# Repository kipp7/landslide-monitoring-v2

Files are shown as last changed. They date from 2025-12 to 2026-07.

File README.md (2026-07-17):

# Landslide Monitoring V2








English | [简体中文](README.zh-CN.md)

<p align="center">
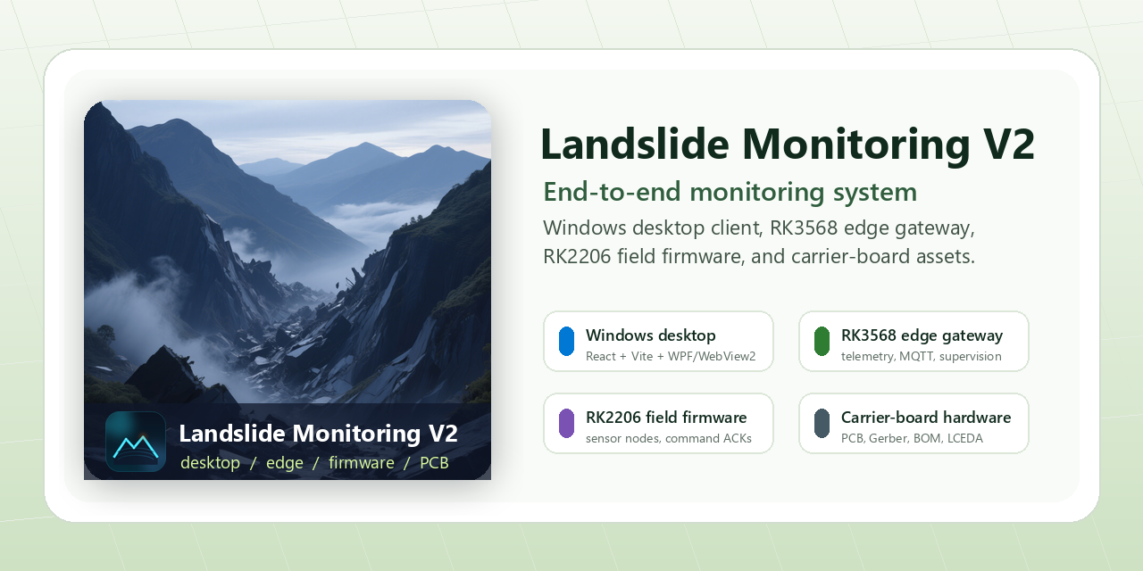
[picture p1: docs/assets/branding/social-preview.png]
Landslide Monitoring V2 end-to-end system preview
  
</p>

Landslide Monitoring V2 is an end-to-end open-source landslide monitoring system. It brings together the Windows operator client, cloud backend services, RK3568 edge gateway services, RK2206 field-node firmware, and carrier-board hardware handoff assets in one public repository.

The repository is organized around five product areas: desktop operations, cloud backend services, edge gateway services, field firmware, and carrier-board hardware.

## System Overview

```text
RK2206 field nodes
  -> RK3568 edge gateway
    -> compatible monitoring API / MQTT broker
      -> Windows desktop operator client
```

## Highlights

- Windows monitoring client built with React, Vite, WPF, and WebView2.
- Cloud backend with REST API, PostgreSQL, ClickHouse, EMQX, Kafka, telemetry ingestion, rules, and device-command workers.
- RK3568 edge services for serial telemetry, MQTT forwarding, local health summaries, supervision, and alarm actuation.
- RK2206 XL01 field firmware package for sensor acquisition, telemetry envelopes, command acknowledgements, watchdogs, and board utilities.
- Carrier-board public handoff package with schematic, PCB preview, Gerber, BOM, pick-and-place, and LCEDA source package.
- Bilingual documentation, GitHub issue templates, maintainer notes, security policy, CI, and MIT license.

## Repository Layout

| Path | Responsibility |
| --- | --- |
| `apps/desktop-ui/` | React + Vite monitoring interface for operator workflows. |
| `apps/windows-shell/` | WPF + WebView2 Windows host, packaging assets, and native startup checks. |
| `services/` | Cloud API, telemetry, alerting, prediction, and command-processing services. |
| `infra/compose/` | Single-host backend infrastructure and application deployment. |
| `edge/rk3568-gateway/` | RK3568 gateway, link-monitor, supervisor, and alarm actuator services. |
| `firmware/rk2206-xl01/` | RK2206 XL01 field-node firmware package and pinout notes. |
| `hardware/carrier-board/` | Public carrier-board design and fabrication handoff assets. |
| `packages/`, `libs/` | Shared TypeScript packages used by edge and backend services. |
| `scripts/desktop/` | Windows desktop development, packaging, and verification scripts. |
| `docs/` | Architecture, scope, release, system, maintainer, and bilingual documentation. |

## Maintained Surfaces

| Surface | Status | Primary Docs |
| --- | --- | --- |
| Windows desktop client | Maintained | [Desktop UI](apps/desktop-ui/README.md), [Windows shell](apps/windows-shell/README.md) |
| Cloud backend | Maintained | [Docker Compose deployment](infra/compose/README.md) |
| RK3568 edge gateway | Maintained | [Edge gateway](edge/rk3568-gateway/README.md) |
| RK2206 field firmware | Maintained as public firmware package | [Firmware](firmware/rk2206-xl01/README.md) |
| Carrier-board hardware handoff | Maintained as public design package | [Hardware](hardware/carrier-board/README.md) |
| Web and mobile applications | Not included in the public tree | [Project scope](docs/PROJECT_SCOPE.md) |

## Tech Stack

| Layer | Technology |
| --- | --- |
| Desktop UI | React 18, TypeScript, Vite, Ant Design |
| Visualization | ECharts, Leaflet, Three.js |
| Native desktop shell | .NET 8, WPF, WebView2 |
| Cloud backend | Node.js 20, Fastify, PostgreSQL, ClickHouse, EMQX, Kafka |
| Edge services | Node.js 20, TypeScript, MQTT, serialport, systemd deployment templates |
| Field firmware | OpenHarmony/RK2206 application package |
| Hardware handoff | Schematic, PCB preview, Gerber, BOM, pick-and-place, LCEDA project package |
| Tooling | npm workspaces, ESLint, Prettier, GitHub Actions |

## Quick Start

```powershell
git clone https://github.com/kipp7/landslide-monitoring-v2.git
cd landslide-monitoring-v2
npm install
npm run dev
```

The desktop UI dev server starts at `http://localhost:5174/`.

Launch the native Windows shell against the dev server:

```powershell
npm run desktop:dev
```

## Build And Validate

Desktop UI:

```powershell
npm audit
npm run lint
npm run build
```

RK3568 edge services:

```powershell
npm run edge:build
npm run edge:lint
```

Windows shell:

```powershell
dotnet build .\apps\windows-shell\LandslideDesk.Win\LandslideDesk.Win.csproj -c Release
```

Create the default Windows portable package:

```powershell
npm run desktop:publish
```

Default packaging outputs stay outside Git:

- `artifacts/windows/portable/`
- `docs/reports/windows-package-latest.json`

## Documentation

- [Documentation hub](docs/README.md)
- [System overview](docs/system/OVERVIEW.md)
- [Architecture](docs/ARCHITECTURE.md)
- [Project scope](docs/PROJECT_SCOPE.md)
- [Release process](docs/RELEASE.md)
- [中文文档总览](docs/zh-CN/README.md)
- [中文系统概览](docs/zh-CN/system/OVERVIEW.md)
- [中文架构说明](docs/zh-CN/ARCHITECTURE.md)
- [中文项目范围](docs/zh-CN/PROJECT_SCOPE.md)
- [中文发布流程](docs/zh-CN/RELEASE.md)

## Repository Scope

This repository includes public source code, documentation, examples, deployment templates, the RK2206 firmware package, and carrier-board handoff files. Runtime secrets, local logs, generated builds, and site-specific configuration should stay outside Git.

## Contributing

Contributions are welcome. Please read [CONTRIBUTING.md](CONTRIBUTING.md) before opening a pull request, and include screenshots or recordings for visible UI changes.

## License

Released under the [MIT License](LICENSE).

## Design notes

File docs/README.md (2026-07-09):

# Documentation

English | [简体中文](zh-CN/README.md)

This documentation set keeps the public repository small, clear, and buildable. It explains the maintained system areas, runtime boundaries, local validation commands, release process, and contribution workflow.

## Start Here

| Document | Purpose |
| --- | --- |
| [System Overview](system/OVERVIEW.md) | End-to-end product surfaces and data flow. |
| [Architecture](ARCHITECTURE.md) | Runtime boundary, module responsibilities, and packaging flow. |
| [Project Scope](PROJECT_SCOPE.md) | Repository contents, maintained areas, and current non-goals. |
| [Release Process](RELEASE.md) | Local build, validation, packaging, and GitHub release checklist. |
| [Desktop UI](../apps/desktop-ui/README.md) | React/Vite UI package responsibilities and commands. |
| [Windows Shell](../apps/windows-shell/README.md) | WPF/WebView2 host responsibilities and packaging behavior. |
| [RK3568 Edge Gateway](../edge/rk3568-gateway/README.md) | Edge service responsibilities, deployment notes, and local configuration. |
| [RK2206 Firmware](../firmware/rk2206-xl01/README.md) | Field-node firmware package and build context. |
| [Carrier Board](../hardware/carrier-board/README.md) | Hardware design and fabrication handoff package. |
| [Contributing](../CONTRIBUTING.md) | Contribution workflow, checks, and project conventions. |
| [Maintainers Guide](../MAINTAINERS.md) | Review policy, dependency update cadence, and release readiness checks. |
| [Security](../SECURITY.md) | Vulnerability reporting and secret-handling policy. |

## Repository Conventions

- Directory names describe product responsibility and runtime role.
- Generated artifacts belong under `artifacts/` and stay out of Git.
- Local reports belong under `docs/reports/` and should be regenerated as needed.
- Public-facing behavior changes should update both English and Chinese documentation.
- Pull requests that change visible UI should include screenshots or recordings.
- Hardware files are treated as handoff assets and should be reviewed before fabrication.

## Maintained Surface

The current public repository maintains:

- Windows desktop UI and native shell source.
- RK3568 edge gateway services and deployment templates.
- RK2206 XL01 field firmware package.
- Carrier-board hardware design and fabrication handoff assets.
- Desktop packaging and verification scripts.
- Public documentation, issue templates, and pull request templates.

The following areas are outside the current public scope:

- Production backend services.
- Mobile applications.
- Web dashboard application code.
- Production deployment infrastructure.
- Site-specific configuration and environment files.
- Credentials, generated outputs, local logs, and runtime state.

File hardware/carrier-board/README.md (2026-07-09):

# Carrier Board Hardware

This directory contains the public carrier-board handoff package for the RK2206/XL01 landslide monitoring node.

## Contents

| Path | Purpose |
| --- | --- |
| `assets/board-layout-module-carrier-150x100-v7.svg` | Human-readable layout reference. |
| `board-layout-notes.md` | Placement, connector, and routing notes. |
| `coordinate-table.md` | Component coordinate planning table. |
| `pin1-dimension-notes.md` | Pin-1 and mechanical dimension notes. |
| `electrical-layout-notes.zh-CN.md` | Chinese electrical and wiring notes. |
| `production/gerber-pcb1-2026-05-05.zip` | Gerber package for PCB fabrication review. |
| `production/schematic-2026-04-30.pdf` | Schematic export. |
| `production/pcb-preview-2026-05-05.pdf` | PCB preview export. |
| `production/bom-board1-2026-04-23.xlsx` | BOM export. |
| `production/pick-and-place-2026-04-27.xlsx` | Pick-and-place export. |
| `production/lceda-project-rk2206-v1.2-2026-05-02.epro2` | LCEDA project package. |

## Manufacturing Notice

Review the schematic, BOM, pick-and-place orientation, connector footprints, and supplier substitutions before ordering. Fabrication should be checked against the selected vendor's requirements.

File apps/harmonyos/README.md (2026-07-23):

# HarmonyOS landslide monitoring prototype

This is the native ArkTS/ArkUI phone prototype for the landslide monitoring
platform. The server remains the only source of truth: the app calls the
existing `/api/v1` HTTP API and never connects to PostgreSQL or ClickHouse.

## Local development

Open this directory in DevEco Studio, select the `default` product, configure
the API base URL in `entry/src/main/ets/data/ApiConfig.ets`, and run the `entry`
module on a HarmonyOS phone or emulator.

DevEco Studio provides the required SDK and Hvigor runtime. The project can be
built from DevEco Studio or with its bundled `hvigorw` command after setting
`DEVECO_SDK_HOME`.

## Data and cache behavior

- Login, dashboard, stations, devices, telemetry, alerts, and predictions use
  the existing `/api/v1` contract.
- Dashboard `todayReportCount` counts distinct device reports, while
  `todayDataCount` remains the sparse ClickHouse sensor-row count for API
  compatibility. Both use the Beijing calendar day (`UTC+8`, starting at
  local 00:00); the App displays it as `今日数据上传条数` with the exact
  Beijing update time and does not label it as sensor rows.
- The **Hermes intelligent workbench** uses `/api/v1/edge-ai/status`,
  `/api/v1/edge-ai/chat`, `/api/v1/edge-ai/conversations`, and the bounded
  action endpoints. Conversations, user/assistant messages, task status, and
  results are persisted by the server in the existing PostgreSQL database and
  isolated by authenticated user. The App remains API-only.
- Hermes exposes only three bounded, read-only actions to the App: re-evaluate
  risk (`重新研判`), collect diagnostic evidence (`诊断链路`), and generate a
  situation report (`生成报告`). A message may contain several safe actions;
  the server creates an auditable plan and dispatches them to RK3568 in spoken
  order. The App shows the real conversation and each server task rather than
  treating an action log as chat history.
- Protected requests such as restarting services, changing networks or alarm
  thresholds, controlling devices, writing serial data, and triggering or
  clearing physical alarms are blocked before RK3568 is called. Physical alarm
  authority remains with the rule engine and confirmed human workflows.
- Edge AI is loaded independently from the monitoring dashboard. If RK3568
  Hermes is unavailable, the App keeps the last cached AI snapshot and all
  original monitoring pages continue to refresh normally.
- Successful summary, station, device, and latest-state responses are cached
  with TTLs. The app renders stale data immediately and refreshes in the
  background.
- Historical series stay in memory only. Preferences stores small snapshots,
  never credentials or a second business database.
- Access and refresh tokens are stored with HarmonyOS AssetStoreKit and are
  removed on logout or when the API server is changed. A valid session is
  restored after the app process restarts.
- Device detail refreshes every 10 seconds while visible; dashboard and alerts
  refresh every 30 seconds. Refresh stops when the app is backgrounded.
- All temperature and moisture values are presented as soil temperature and
  soil moisture. Generic server keys are compatibility fallbacks only.
- Soil conductivity uses `electrical_conductivity_us_cm` and is displayed in
  `μS/cm`; when the latest-state snapshot omits it, device detail falls back to
  the newest point in the requested historical series.
- Conductivity visibility follows device capability metadata. An explicit
  `hasConductivitySensor` value takes priority; the current A/B/C deployment
  enables conductivity for field nodes B and C only.
- Monitoring-node counts, sensor trends, and state requests exclude platform
  alarm actuators. The Tongxiao RK2206 terminal is shown separately as
  `通晓 RK2206 声光告警终端` under linkage alarm devices, so it cannot distort
  A/B/C monitoring statistics.
- The Tongxiao linkage status comes from `/api/v1/field-alarm/status` and its
  physical-device probe when available. It is not inferred from telemetry
  `lastSeenAt`, because the actuator is not a monitoring-data producer.
- The alert map resolves coordinates in this order: coordinates recorded with
  the alert, recent device GPS, seven-day GPS history, the last GPS snapshot,
  station coordinates, and finally the Windows desktop default position at
  Xiamen University (`24.43803, 118.09631`). A stale GPS value is labelled as
  the last GPS rather than real-time data. GPS values outside the project's
  China operating region are treated as invalid device data and cannot replace
  the last valid position.
- Map preview renders every monitoring node and fits the viewport to all node
  markers. Nodes without GPS use the same three-point spread around Xiamen
  University as the Windows desktop, while an active alert remains centred and
  switches the matching node to a red warning ripple. Other nodes retain a
  green monitoring ripple; a separate red ripple is used when the precise alert
  coordinate differs from its node location. Live GPS markers that resolve to
  the same site are spread only in the presentation layer and labelled as such,
  so A/B/C remain selectable without changing their stored coordinates.
- The station page embeds the same map as a distribution view. It shows every
  monitoring node, focuses the selected station, and refreshes GPS without
  introducing a second location model.
- The most recent valid GPS snapshot is stored in Preferences using the same
  API-server and user cache namespace. It is cleared on logout or server
  change, so positions cannot leak across accounts or environments.
- Foreground `ALERT_TRIGGER` SSE events open a blocking in-app alert panel and
  start the bundled smooth civil-defense-style alarm with a synchronized
  vibration cadence. Muting pauses both sound and vibration. Updates replace the same
  `alertId` in place, critical escalation reopens the strong reminder, and
  acknowledgement leaves the warning active, and only resolution removes that
  alert from the panel. Concurrent node alerts are queued by `alertId` instead
  of being duplicated by event ID.
  See [`ALERT_INTEGRATION.md`](./ALERT_INTEGRATION.md) for the shared Windows,
  App, and Push payload contract.
- The **My** page keeps the API address hidden in normal use. Connection state,
  cache cleanup, refresh cadence, location use, and app version are grouped as
  settings; the address is only exposed after opening the server editor.
- The map uses Leaflet with TianDiTu `img_w` satellite imagery and `cia_w`
  Chinese annotations. Its browser-side key is injected by ArkTS from
  `entry/src/main/ets/data/MapConfig.ets`. Map tiles are not part of the
  business-data cache and require network access; coordinates and their source
  remain visible when the basemap cannot load.

## API configuration

The normal login screen uses the default API base URL from
`entry/src/main/ets/data/ApiConfig.ets` and keeps it hidden. Authentication
errors remain on the login screen. If the server cannot be reached or the API
path is invalid, the app opens a separate server connection screen where the
address can be changed. Signed-in users can open **My > Server connection** to
change it; changing environments clears the current session and cached data.

For emulator and LAN debugging, use a reachable LAN or HTTPS URL that includes
the `/api/v1` path. `127.0.0.1` inside an emulator refers to the emulator
itself. Release builds should use HTTPS.

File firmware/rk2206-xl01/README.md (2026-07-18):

# RK2206 XL01 Field Firmware

This directory contains the stable RK2206 XL01 field-node firmware package used by the landslide monitoring system.

## Responsibilities

- Sensor acquisition and field-node data model.
- GPS and deformation data handling.
- Telemetry envelope construction.
- Device command parsing and command acknowledgement.
- COBS/CRC framed southbound transport and gateway-polled telemetry.
- SC16IS752-backed RS485 soil, optional conductivity, and tilt acquisition.
- Watchdog-backed recovery after 180 seconds without an accepted gateway command.
- Watchdog, FIFO, and board-level utility helpers.

## Upstream Build Context

The firmware is designed to be built inside a compatible OpenHarmony/RK2206 vendor tree. This directory contains the application package and documentation needed for that integration.

## Key Files

- `BUILD.gn` - OpenHarmony build target definition.
- `main/landslide_main.c` - field-node entrypoint.
- `app/` - telemetry, command, identity, and application models.
- `drivers/` - sensor and XL01 integration drivers.
- `config/app_config.h` - board/application constants.
- `PINOUT.md` and `RK2206_PINOUT_NOTES.zh-CN.md` - wiring and pinout references.

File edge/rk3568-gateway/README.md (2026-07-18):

# RK3568 Edge Gateway

This directory contains the RK3568 edge services that bridge field nodes and the monitoring platform.

## Services

| Service | Role |
| --- | --- |
| `field-gateway` | Main serial-to-MQTT gateway with spool/cache, health file output, polling, command ACK handling, and RK3568 deployment scripts. |
| `field-link-monitor` | Read-only local sidecar that summarizes field-link health and exposes local supervision endpoints. |
| `hermes-edge-supervisor` | Local edge supervision service that consumes health signals and produces operator guidance. |
| `rk3568-alarm-actuator` | Local actuator service for RK3568-driven field alarm control. |
| `cellular` | EC200A readiness, business-link health, and optional reverse-tunnel deployment helpers. |

## Deployment

Each service keeps its own `deploy/` directory when deployment assets exist. Environment examples use placeholders and must be copied to local `.env` or systemd environment files before real deployment.

## Local Configuration

Keep deployment-specific values in local environment files. Use `.env.example` and `deploy/*.example` files as templates for device configuration.

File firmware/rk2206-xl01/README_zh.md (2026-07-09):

# XL01 滑坡监测节点 - 模块化架构 v2.0

## 项目简介

基于 RK2206 + XL01 无线模块的滑坡监测节点，采用分层模块化架构设计。

**当前版本**: v2.0  
**状态**: 可构建的公开固件包
**架构**: 分层模块化设计

---

## 架构特点

### 模块化分层设计

```
xl01_landslide_monitor/
├── config/           # 配置层：全局参数集中管理
│   └── app_config.h
├── utils/            # 工具层：通用功能模块
│   ├── fifo.h/.c           # FIFO缓冲区
│   └── watchdog_mgr.h/.c   # 看门狗管理
├── drivers/          # 驱动层：硬件抽象
│   ├── xl01/               # 无线通信模块驱动
│   │   ├── xl01_driver.h
│   │   └── xl01_driver.c
│   └── sensors/            # 传感器驱动
│       ├── sht30_driver.h/.c    # 温湿度
│       ├── mpu6050_driver.h/.c  # 加速度/陀螺仪
│       └── gps_driver.h/.c      # GPS定位
├── app/              # 应用层：数据结构定义
│   └── sensor_data.h
└── main/             # 主程序：业务逻辑
    └── landslide_main.c
```

### 设计优势

| 特性 | 说明 |
|-----|---|
| **关注点分离** | 配置、驱动、应用逻辑各司其职 |
| **硬件抽象** | 传感器驱动独立，易于测试和替换 |
| **低耦合** | 模块间依赖最小化 |
| **高内聚** | 相关功能组织在一起 |
| **可维护性** | 单一职责原则，修改影响面小 |
| **可测试性** | 独立模块便于单元测试 |
| **可扩展性** | 新增传感器只需添加新驱动模块 |

---

## 核心功能

### 1. 模块化传感器支持
每个传感器可独立启用/禁用（在 `config/app_config.h` 中配置）：
```c
#define ENABLE_GPS          0    // GPS定位模块
#define ENABLE_SHT30        0    // 温湿度传感器
#define ENABLE_MPU6050      0    // 加速度/陀螺仪
#define ENABLE_VIRTUAL      1    // 虚拟数据（测试用）✓
```

### 2. ACK确认机制
当前 ACK 机制分成两层：

1. **链路级 ACK**
- 节点 ↔ 无线/网关之间的确认
- 当前仍使用 `"ACK"` / `"OK"` 字符串
- 只用于确认串口/无线链路发送成功

2. **平台命令回执**
- 不再停留在 `"ACK"` / `"OK"`
- 对齐软件主线：
  - `cmd_ack/{device_id}`
  - `DeviceCommandAck v1`

当前代码里保留的 `ENABLE_ACK_CHECK` / `ACK_TIMEOUT_MS` 主要属于第 1 层，也就是链路级 ACK：
```c
#define ENABLE_ACK_CHECK    1       // 启用ACK检查
#define ACK_TIMEOUT_MS      1000    // ACK超时（毫秒）
#define MAX_RETRY_COUNT     3       // 最大重试次数
```

工作流程：
1. RK2206 发送遥测或标准回执 payload
2. 等待网关/接收端返回链路级 `"ACK\n"` / `"OK"`
3. 收到 ACK → 链路发送成功 ✓
4. 超时 → 自动重试（最多3次）

### 3. 防丢包机制
- **1024字节FIFO缓冲** - 高速接收不丢数据
- **三任务架构**:
  - `UartRxTask` (高优先级, 1ms轮询)
  - `DataProcessTask` (普通优先级)
  - `SensorUploadTask` (低优先级)

### 4. 看门狗保护
```c
#define ENABLE_WATCHDOG     1       // 启用看门狗
#define WATCHDOG_TIMEOUT    10      // 超时时间（秒）
```
系统异常时自动重启恢复。

### 5. 低功耗支持
```c
#define UPLOAD_INTERVAL_MS  5000    // 上传间隔（可调）
#define ENABLE_LOW_POWER    0       // 低功耗模式（预留）
```

---

## 配置参数

所有配置参数都在 `config/app_config.h` 文件中集中管理：

### 身份配置
```c
#define IDENTITY_SCHEMA_VERSION  1
#define CRED_VERSION             1
#define DEVICE_ID                "00000000-0000-0000-0000-000000000001"
#define DEVICE_SECRET            "CHANGE_ME_DEVICE_SECRET"
#define INSTALL_LABEL            "FIELD-NODE-A"
#define LEGACY_NODE_LABEL        "A"   // 仅调试标签，不再作为平台主身份
```

### 上传配置
```c
#define UPLOAD_INTERVAL_MS  5000    // 上传间隔
                                    // 推荐值：
                                    //   3000 = 快速监测
                                    //   5000 = 标准（推荐）
                                    //  10000 = 省电模式
```

### 硬件配置
```c
// XL01无线模块
#define XL01_UART_ID    EUART2_M1   // UART2
#define XL01_BAUDRATE   115200      // 波特率

// I2C传感器
#define I2C_IDX         EI2C0_M0    // PB4/PB5
#define SHT30_I2C_ADDR  0x44        // SHT30地址
#define MPU6050_I2C_ADDR 0x68       // MPU6050地址

// GPS模块
#define GPS_UART_ID     EUART0_M0   // PB6/PB7
#define GPS_BAUDRATE    9600        // 波特率
```

---

## 🚀 快速开始

### 1. 编译固件

```bash
# 进入Docker容器
docker exec -it openharmony-dev bash

# 编译
cd /root/workspace/txsmartropenharmony
hb build -f

# 固件位置
# out/rk2206/isoftstone-rk2206/liteos.bin
```

### 2. 烧录固件

使用HiBurn工具烧录 `liteos.bin` 到RK2206。

### 3. 配置接收端 / 网关

**临时串口接收示例（仅链路验证，不是最终平台真相）**
```python
import serial
ser = serial.Serial("COM3", 115200)
while True:
    if ser.in_waiting > 0:
        line = ser.readline().decode('utf-8').strip()
        print(line)
        # 回复链路级 ACK（如果启用了 ACK 检查）
        ser.write(b"ACK\n")
```

说明：

- 这段 Python 只适合验证串口/无线链路本身
- 当前长期目标不是“中心节点长期回 ACK 字符串”
- 而是让网关或适配层最终把数据接入软件主线：
  - 遥测：`telemetry/{device_id}`
  - 命令：`cmd/{device_id}`
  - 回执：`cmd_ack/{device_id}`

### 4. 观察输出

**RK2206串口输出**:
```
========================================
  Configuration Summary
========================================
  Device ID: 00000000-0000-0000-0000-000000000001
  Upload Interval: 5000 ms
  ACK Check: Enabled
  Sensors: Virtual ✓
========================================

[SEND #1] 245 bytes device=00000000-0000-0000-0000-000000000001 ✓ ACK
  Temp:25.0°C Humi:60.0% Tilt:0.00° GPS:OK Bat:99%
```

**当前建议对齐到平台主线的上报格式**:
```json
{
  "schema_version": 1,
  "device_id": "00000000-0000-0000-0000-000000000001",
  "event_ts": null,
  "seq": 1,
  "metrics": {
    "temperature_c": 25.0,
    "humidity_pct": 60.0,
    "tilt_x_deg": 0.0,
    "tilt_y_deg": 0.0,
    "gps_latitude": 22.543000,
    "gps_longitude": 114.057900,
    "battery_pct": 99,
    "warning_flag": false
  },
  "meta": {
    "install_label": "FIELD-NODE-A",
    "legacy_node": "A",
    "uptime_s": 5,
    "legacy_valid_flags": {
      "temp_ok": 1,
      "imu_ok": 1,
      "gps_ok": 1
    }
  }
}
```

当前软件主线对应 topic：

- 遥测：`telemetry/{device_id}`
- 命令：`cmd/{device_id}`
- 回执：`cmd_ack/{device_id}`

---

## 🔧 传感器接入流程（模块化方式）

### Step 1: 测试虚拟数据（当前状态）
```c
#define ENABLE_VIRTUAL 1  // ✓
```
确保 XL01 通信正常，且链路级 ACK 机制工作。

### Step 2: 接入SHT30温湿度
1. 连接硬件（I2C）
2. 修改配置（`config/app_config.h`）：
   ```c
   #define ENABLE_VIRTUAL 0
   #define ENABLE_SHT30   1
   ```
3. 驱动已实现在 `drivers/sensors/sht30_driver.c`
4. 编译测试

### Step 3: 接入MPU6050加速度/陀螺仪
```c
#define ENABLE_MPU6050 1
```
驱动已实现在 `drivers/sensors/mpu6050_driver.c`

### Step 4: 接入GPS模块
```c
#define ENABLE_GPS 1
```
驱动已实现在 `drivers/sensors/gps_driver.c`（需完善NMEA解析）

---

## 📝 添加新传感器（模块化）

遵循模块化原则，添加新传感器非常简单：

### 1. 创建驱动模块
在 `drivers/sensors/` 下创建 `xxx_driver.h` 和 `xxx_driver.c`：

```c
// drivers/sensors/xxx_driver.h
#ifndef DRIVERS_SENSORS_XXX_DRIVER_H
#define DRIVERS_SENSORS_XXX_DRIVER_H

int XXX_Init(void);
int XXX_Read(float *value);

#endif

// drivers/sensors/xxx_driver.c
#include "xxx_driver.h"
#include "../../config/app_config.h"

int XXX_Init(void) {
    // 初始化代码
    return 0;
}

int XXX_Read(float *value) {
    // 读取代码
    return 0;
}
```

### 2. 更新配置
在 `config/app_config.h` 中添加：
```c
#define ENABLE_XXX  1
```

### 3. 更新数据结构
在 `app/sensor_data.h` 的 `SensorData` 结构体中添加字段：
```c
typedef struct {
    // ...现有字段...
    float xxx_value;  // 新传感器数据
    int xxx_valid;    // 数据有效标志
} SensorData;
```

### 4. 集成到主程序
在 `main/landslide_main.c` 中：
```c
// 引入头文件
#if ENABLE_XXX
#include "../drivers/sensors/xxx_driver.h"
#endif

// SystemInit() 中初始化
#if ENABLE_XXX
XXX_Init();
#endif

// SensorCollectionTask() 中读取
#if ENABLE_XXX
if (XXX_Read(&g_sensor_data.xxx_value) == 0) {
    g_sensor_data.xxx_valid = 1;
}
#endif

// DataUploadTask() 中添加到JSON
// "xxx":%.2f,"xxx_ok":%d,
```

### 5. 更新构建配置
在 `BUILD.gn` 的 `sources` 中添加：
```gn
"drivers/sensors/xxx_driver.c",
```

完成！新传感器已集成，无需修改其他模块。

---

## 📊 当前软件主线对齐后的遥测格式

```json
{
  "schema_version": 1,   // 契约版本
  "device_id": "00000000-0000-0000-0000-000000000001",
  "event_ts": null,
  "seq": 123,            // 序列号
  "metrics": {
    "temperature_c": 25.5,
    "humidity_pct": 62.3,
    "accel_x_g": 0.15,
    "accel_y_g": 0.09,
    "accel_z_g": 1.02,
    "gyro_x_dps": 0.5,
    "gyro_y_dps": -0.3,
    "gyro_z_dps": 0.1,
    "tilt_x_deg": 0.15,
    "tilt_y_deg": 0.09,
    "gps_latitude": 22.543012,
    "gps_longitude": 114.057923,
    "battery_pct": 85,
    "warning_flag": false
  },
  "meta": {
    "install_label": "FIELD-NODE-A",
    "legacy_node": "A",
    "uptime_s": 615,
    "legacy_valid_flags": {
      "temp_ok": 1,
      "imu_ok": 1,
      "gps_ok": 1
    }
  }
}
```

---

## 📈 统计监控

每10个数据包输出统计信息：
```
========== Statistics ==========
  Uptime: 50 sec
  Sent: 10/10 (Success: 100.0%)
  Retries: 0, Failed: 0
  Total bytes: 2450
  RX packets: 0
================================
```

---

## ❓ 故障排查

### 问题1: 接收端 / 网关收不到数据
**检查**:
- ✓ XL01天线是否连接
- ✓ 串口连接（白线→RX, 绿线→TX）
- ✓ XL01是否配置为透传模式
- ✓ 波特率是否匹配（115200）

### 问题2: ACK总是超时
**检查**:
- ✓ 接收端 / 网关程序是否运行
- ✓ 接收端是否回复链路级 `"ACK\n"`
- ✓ 串口号是否正确
- ✓ 增加超时：`#define ACK_TIMEOUT_MS 2000`

### 问题3: 平台命令回执没有闭环
**检查**:
- ✓ 当前是否只完成了链路级 ACK，而没有输出标准 `DeviceCommandAck v1`
- ✓ 当前网关是否把回执发到了 `cmd_ack/{device_id}`
- ✓ `device_id` 是否与平台设备身份一致
### 问题4: 编译错误
**检查**:
- ✓ 确保所有 `.c` 文件都在 `BUILD.gn` 的 `sources` 中
- ✓ 确保头文件路径正确（使用相对路径 `../../`）
- ✓ 确保配置宏定义正确（`config/app_config.h`）

---

## 技术特性总结

### 优势
1. **模块化**: 分层设计，职责清晰
2. **可维护**: 单一职责，易于定位问题
3. **可测试**: 独立模块，支持单元测试
4. **可扩展**: 新增功能不影响现有代码
5. **运行保护**: 统计信息、异常恢复和看门狗保护

### 性能指标
- **上传间隔**: 3-60秒（可配置）
- **链路 ACK 延迟**: 0.2-5.5秒（含重试）
- **缓冲容量**: 1024字节FIFO
- **成功率**: >95%（良好信号下）

---

## 相关文档

- `CHANGELOG.md` - 变更记录
- 中心节点 ACK 示例和 ACK 机制说明应以仓库内文档或示例代码为准。

---

## 维护信息

**版本**: v2.0  
**更新**: 2025-10-22  
**状态**: 固件工程具备模块化基础，但仍在向当前软件主线契约全面收口

**架构亮点**:
- 分层模块化设计
- 驱动层硬件抽象
- 配置集中管理
- 模块独立可测试
- 清晰的职责划分

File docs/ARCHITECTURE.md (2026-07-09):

# Architecture

Landslide Monitoring V2 is organized as a public end-to-end monitoring workspace. The repository keeps the desktop client, edge gateway, field firmware, and carrier-board handoff files together in one buildable tree.

## System Boundary

```text
Field layer
  RK2206 XL01 firmware
    -> sensor acquisition, telemetry envelope, command acknowledgement

Edge layer
  RK3568 gateway services
    -> serial link, MQTT forwarding, health summaries, supervision, alarm actuation

Operator layer
  Windows desktop client
    -> React monitoring UI hosted by WPF + WebView2
```

The public tree contains source, documentation, examples, deployment templates, and hardware handoff assets. Runtime secrets, generated builds, local logs, and site-specific configuration stay outside Git.

## Applications And Packages

| Path | Responsibility |
| --- | --- |
| `apps/desktop-ui` | React + Vite monitoring interface, routes, stores, charts, maps, and mock data. |
| `apps/windows-shell` | WPF/WebView2 native host, startup preflight checks, tray behavior, installer assets. |
| `edge/rk3568-gateway/field-gateway` | Serial-to-MQTT gateway with local spool/cache, health output, command ACK handling, and deployment templates. |
| `edge/rk3568-gateway/field-link-monitor` | Read-only local sidecar that summarizes field-link health. |
| `edge/rk3568-gateway/hermes-edge-supervisor` | Local supervision service that consumes health signals and produces operator-facing guidance. |
| `edge/rk3568-gateway/rk3568-alarm-actuator` | RK3568 alarm actuator service for field sound/light alarm control. |
| `firmware/rk2206-xl01` | RK2206 XL01 firmware package intended for an OpenHarmony/RK2206 vendor build tree. |
| `hardware/carrier-board` | Public carrier-board schematic, board preview, Gerber, BOM, pick-and-place, and LCEDA handoff package. |
| `packages/observability` | Shared logging helpers for edge services. |
| `packages/validation` | Shared validation helpers for edge payloads and configuration. |

## Desktop Client

The desktop client owns the operator-facing workflows:

- Dashboard and key monitoring site overview.
- Device management and command-oriented screens.
- GPS deformation and monitoring views.
- Analysis pages with charts, maps, and domain mock data.
- Account, settings, and system state pages.

The UI can run independently in development with:

```powershell
npm run dev
```

The native shell loads the UI in two modes:

- Development: reads `DESK_DEV_SERVER_URL`, usually `http://localhost:5174/`.
- Packaged: loads static files from the published `web/` directory.

## Edge Gateway

The RK3568 layer bridges field devices and upstream monitoring services. Its public services are split by responsibility:

- `field-gateway` owns serial ingestion, message reconstruction, MQTT publishing, spool/cache behavior, command windows, and health files.
- `field-link-monitor` reads local status files and exposes read-only supervision summaries.
- `hermes-edge-supervisor` turns local health signals into diagnostic and operator guidance output.
- `rk3568-alarm-actuator` controls field alarm hardware without taking over telemetry or gateway responsibilities.

Edge services are TypeScript packages and are validated from the root workspace:

```powershell
npm run edge:build
npm run edge:lint
```

## Field Firmware

The RK2206 XL01 firmware package contains application code, configuration, drivers, pinout notes, and build metadata. It is designed for integration with a compatible OpenHarmony/RK2206 vendor tree and uses the standard OpenHarmony/RK2206 build flow.

## Hardware Handoff

The carrier-board directory contains public design and fabrication handoff files. These files are useful for review, reproduction, and documentation, but fabrication still requires schematic review, BOM verification, footprint checks, and supplier substitution review.

## Packaging Flow

1. Build `apps/desktop-ui` into `apps/desktop-ui/dist`.
2. Publish `apps/windows-shell` with .NET.
3. Copy the static UI build into the desktop package under `web/`.
4. Write local package metadata under `docs/reports/`.
5. Keep generated outputs out of Git.

## Design Principles

- Keep public modules tied to clear product responsibilities.
- Prefer readable directory names over internal abbreviations.
- Keep generated artifacts, local reports, and machine state out of Git.
- Allow desktop UI work without backend deployment through mock data.
- Keep RK3568 services independently buildable and lintable.
- Treat hardware deliverables as reviewable handoff assets and check them against the selected vendor's requirements.

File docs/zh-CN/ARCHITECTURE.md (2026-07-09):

# 架构说明

山体滑坡监测 V2 是一个公开的端到端监测系统工作区。仓库把桌面客户端、边缘网关、现场固件和载板硬件交付资料放在同一个可构建的公开树中。

## 系统边界

```text
现场层
  RK2206 XL01 固件
    -> 传感采集、遥测封包、指令确认

边缘层
  RK3568 网关服务
    -> 串口链路、MQTT 转发、健康摘要、监督服务、声光报警执行

操作层
  Windows 桌面客户端
    -> WPF + WebView2 宿主中的 React 监测界面
```

公开树包含源码、文档、示例、部署模板和硬件交付资料。运行密钥、本地日志、生成产物和现场特定配置应保留在 Git 之外。

## 应用与包

| 路径 | 职责 |
| --- | --- |
| `apps/desktop-ui` | React + Vite 监测界面，包括路由、状态、图表、地图和 mock 数据。 |
| `apps/windows-shell` | WPF/WebView2 原生宿主，包括启动检查、托盘能力和安装器资源。 |
| `edge/rk3568-gateway/field-gateway` | 串口到 MQTT 网关，负责本地缓存、健康输出、指令 ACK 和部署模板。 |
| `edge/rk3568-gateway/field-link-monitor` | 只读本地 sidecar，汇总现场链路健康状态。 |
| `edge/rk3568-gateway/hermes-edge-supervisor` | 本地监督服务，消费健康证据并输出操作员可读建议。 |
| `edge/rk3568-gateway/rk3568-alarm-actuator` | RK3568 声光报警执行服务。 |
| `firmware/rk2206-xl01` | 面向 OpenHarmony/RK2206 vendor 构建树的 RK2206 XL01 固件包。 |
| `hardware/carrier-board` | 载板原理图、PCB 预览、Gerber、BOM、坐标文件和 LCEDA 交付包。 |
| `packages/observability` | 边缘服务共用日志工具。 |
| `packages/validation` | 边缘载荷和配置共用校验工具。 |

## 桌面客户端

桌面客户端负责操作员直接使用的工作流：

- 首页总览和关键监测点状态。
- 设备管理和指令相关页面。
- GPS 形变和监测视图。
- 基于图表、地图、领域 mock 数据的分析页面。
- 账号、设置和系统状态页面。

开发时可以独立运行：

```powershell
npm run dev
```

原生壳有两种加载模式：

- 开发模式：读取 `DESK_DEV_SERVER_URL`，通常为 `http://localhost:5174/`。
- 打包模式：从发布目录中的 `web/` 静态资源加载界面。

## 边缘网关

RK3568 层负责连接现场设备和上游监测服务。公开服务按职责拆分：

- `field-gateway` 负责串口采集、消息重组、MQTT 上行、本地缓存、指令窗口和健康文件。
- `field-link-monitor` 读取本地状态文件并暴露只读监督摘要。
- `hermes-edge-supervisor` 将本地健康信号转为诊断和操作建议。
- `rk3568-alarm-actuator` 控制现场声光报警硬件，不接管遥测或网关主链路。

边缘服务是 TypeScript 包，可在仓库根目录验证：

```powershell
npm run edge:build
npm run edge:lint
```

## 现场固件

RK2206 XL01 固件包包含应用代码、配置、驱动、引脚说明和构建元数据。它用于集成到兼容的 OpenHarmony/RK2206 vendor 树，并使用 OpenHarmony/RK2206 构建流程。

## 硬件交付

载板目录包含公开设计和打板交付文件。这些文件可用于复核、复现和文档说明，但打板前仍需检查原理图、BOM、封装、方向和供应商替代料。

## 打包流程

1. 将 `apps/desktop-ui` 构建到 `apps/desktop-ui/dist`。
2. 使用 .NET 发布 `apps/windows-shell`。
3. 将静态 UI 构建结果复制到桌面包的 `web/` 目录。
4. 将本地打包报告写入 `docs/reports/`。
5. 生成输出保留在 Git 之外。

## 设计原则

- 公开模块应对应清晰的产品职责。
- 使用可读目录名，避免不清晰缩写。
- 生成产物、本地报告和机器状态保留在 Git 之外。
- 通过 mock 数据支持无后端 UI 开发。
- RK3568 服务保持可独立构建和 lint。
- 硬件资料作为可复核交付资产维护，打板前应结合所选供应商要求复核。

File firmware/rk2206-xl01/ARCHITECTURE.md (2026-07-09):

# XL01 滑坡监测系统 - 架构设计文档

## 1. 架构概述

### 1.1 设计原则

本项目采用模块化分层架构，遵循以下设计原则：

- **职责清晰**：保持模块边界和接口清晰
- **关注点分离**：配置、驱动、工具、应用、业务逻辑各层独立
- **低耦合高内聚**：模块间依赖最小化，相关功能组织在一起
- **DRY原则**：Don't Repeat Yourself，避免代码重复
- **KISS原则**：Keep It Simple, Stupid，保持简单

### 1.2 分层架构

```
┌─────────────────────────────────────┐
│  配置层 (config/)                   │ ← 集中管理所有参数
├─────────────────────────────────────┤
│  工具层 (utils/)                    │ ← 可复用通用模块
├─────────────────────────────────────┤
│  驱动层 (drivers/)                  │ ← 硬件抽象接口
├─────────────────────────────────────┤
│  应用层 (app/)                      │ ← 数据结构定义
├─────────────────────────────────────┤
│  主程序 (main/)                     │ ← 业务逻辑编排
└─────────────────────────────────────┘
```

---

## 2. 模块详解

### 2.1 配置层 (config/)

**职责**：集中管理所有系统参数，提供统一的配置接口。

**文件**：
- `app_config.h` - 全局配置头文件

**配置类别**：
1. **节点配置**：节点ID
2. **上传配置**：上传间隔、重试次数、ACK超时
3. **传感器开关**：各传感器启用标志
4. **硬件配置**：UART ID、I2C地址、波特率
5. **系统配置**：看门狗、低功耗模式

**优势**：
- ✅ 所有参数集中管理，易于查找和修改
- ✅ 避免魔法数字（Magic Number）
- ✅ 便于不同硬件平台的移植

---

### 2.2 工具层 (utils/)

**职责**：提供可复用的通用功能模块。

#### 2.2.1 FIFO缓冲区 (`fifo.h/.c`)

**功能**：环形缓冲区实现，用于UART接收数据缓存。

**接口**：
```c
void Fifo_Init(Fifo *fifo);                          // 初始化
int Fifo_Write(Fifo *fifo, unsigned char *data, unsigned int len);  // 写入
int Fifo_Read(Fifo *fifo, unsigned char *data, unsigned int len);   // 读取
int Fifo_Available(Fifo *fifo);                      // 可用字节数
```

**特点**：
- ✅ 线程安全（单读单写场景）
- ✅ 防止数据丢失
- ✅ 高效环形缓冲

#### 2.2.2 看门狗管理 (`watchdog_mgr.h/.c`)

**功能**：系统看门狗封装，提供统一的看门狗接口。

**接口**：
```c
void Watchdog_Init(void);    // 初始化看门狗
void Watchdog_Feed(void);    // 喂狗
```

**特点**：
- ✅ 支持编译时开关（`ENABLE_WATCHDOG`）
- ✅ 禁用时自动变为空操作，无性能损失
- ✅ 统一接口，易于测试

---

### 2.3 驱动层 (drivers/)

**职责**：硬件抽象层，封装传感器和通信模块的底层操作。

#### 2.3.1 XL01无线驱动 (`drivers/xl01/`)

**功能**：XL01无线通信模块驱动。

**接口**：
```c
void XL01_Init(void);                                 // 初始化
int XL01_SendWithRetry(const char *data, int len, Statistics *stats);  // 发送（带重试）
void XL01_PollReceive(void);                          // 轮询接收
int XL01_ProcessReceivedData(Statistics *stats);     // 处理接收数据
```

**特点**：
- ✅ 透传模式实现
- ✅ ACK机制（可选）
- ✅ 重试机制
- ✅ FIFO缓冲

#### 2.3.2 传感器驱动 (`drivers/sensors/`)

**SHT30温湿度传感器** (`sht30_driver.h/.c`)
```c
int SHT30_Init(void);
int SHT30_Read(float *temp, float *humi);
```

**MPU6050 IMU传感器** (`mpu6050_driver.h/.c`)
```c
int MPU6050_Init(void);
int MPU6050_Read(float *ax, float *ay, float *az, float *gx, float *gy, float *gz);
```

**GPS定位模块** (`gps_driver.h/.c`)
```c
int GPS_Init(void);
int GPS_Read(float *lat, float *lon);
```

**驱动设计原则**：
- ✅ 统一接口：`XXX_Init()` + `XXX_Read()`
- ✅ 返回值：0 = 成功，负数 = 错误码
- ✅ 独立性：每个驱动可独立编译和测试
- ✅ 自包含：驱动本身定义必要的常量，减少外部依赖

---

### 2.4 应用层 (app/)

**职责**：定义应用级数据结构。

**文件**：
- `sensor_data.h` - 传感器数据结构和统计结构

**数据结构**：

```c
typedef struct {
    // 系统信息
    unsigned int seq;
    unsigned int uptime;
    
    // 温湿度
    float temperature;
    float humidity;
    int temp_valid;
    
    // GPS
    float latitude;
    float longitude;
    int gps_valid;
    
    // 加速度/陀螺仪
    float accel_x, accel_y, accel_z;
    float gyro_x, gyro_y, gyro_z;
    float angle_x, angle_y;
    int imu_valid;
    
    // 状态
    int warning;
    int battery_level;
} SensorData;

typedef struct {
    unsigned int total_sent;
    unsigned int success_count;
    unsigned int retry_count;
    unsigned int failed_count;
    unsigned int total_bytes;
    unsigned int rx_packets;
    unsigned int uptime_sec;
} Statistics;
```

**特点**：
- ✅ 清晰的数据结构定义
- ✅ 各层共享，避免重复定义
- ✅ 易于扩展新字段

---

### 2.5 主程序层 (main/)

**职责**：业务逻辑编排，协调各层模块工作。

**文件**：
- `landslide_main.c` - 主程序入口

**任务架构**：

```
┌────────────────────────────────────┐
│  UartRxTask (高优先级, 1ms)       │ ← UART接收
├────────────────────────────────────┤
│  DataProcessTask (普通优先级, 10ms)│ ← 数据处理
├────────────────────────────────────┤
│  SensorCollectionTask (普通, 1s)  │ ← 传感器采集
├────────────────────────────────────┤
│  DataUploadTask (低优先级, 5s)    │ ← 数据上传
└────────────────────────────────────┘
```

**主要函数**：
1. `App_SystemInit()` - 系统初始化
2. `SensorCollectionTask()` - 传感器采集任务
3. `UartRxTask()` - UART接收任务
4. `DataProcessTask()` - 数据处理任务
5. `DataUploadTask()` - 数据上传任务
6. `MainEntry()` - 主入口函数

**流程图**：

```
启动
  ↓
系统初始化
  ├─ 初始化看门狗
  ├─ 初始化XL01
  ├─ 初始化I2C
  ├─ 初始化传感器（按配置）
  └─ 打印配置摘要
  ↓
创建任务
  ├─ UartRxTask（高优先级）
  ├─ DataProcessTask（普通）
  ├─ SensorCollectionTask（普通）
  └─ DataUploadTask（低优先级）
  ↓
任务调度器启动
  ↓
各任务并发运行
```

---

## 3. 编译配置

### 3.1 BUILD.gn

```gn
static_library("xl01_landslide_monitor") {
    sources = [
        # 主程序
        "main/landslide_main.c",
        
        # 工具
        "utils/fifo.c",
        "utils/watchdog_mgr.c",
        
        # 驱动 - XL01
        "drivers/xl01/xl01_driver.c",
        
        # 驱动 - 传感器
        "drivers/sensors/sht30_driver.c",
        "drivers/sensors/mpu6050_driver.c",
        "drivers/sensors/gps_driver.c",
    ]

    include_dirs = [
        "//utils/native/lite/include",
        "//kernel/liteos_m/kal/cmsis",
        "//base/iot_hardware/peripheral/interfaces/kits",
    ]
}
```

**说明**：
- ✅ 所有模块文件都在 `sources` 中列出
- ✅ 使用统一的 `include_dirs`
- ✅ 编译为静态库

---

## 4. 依赖关系

### 4.1 模块依赖图

```
main/landslide_main.c
  ├─ config/app_config.h
  ├─ utils/fifo.h
  ├─ utils/watchdog_mgr.h
  ├─ drivers/xl01/xl01_driver.h
  ├─ drivers/sensors/sht30_driver.h
  ├─ drivers/sensors/mpu6050_driver.h
  ├─ drivers/sensors/gps_driver.h
  └─ app/sensor_data.h

drivers/xl01/xl01_driver.c
  ├─ config/app_config.h
  ├─ utils/fifo.h
  └─ app/sensor_data.h

drivers/sensors/*.c
  └─ (最小依赖，自包含常量定义)

utils/*.c
  └─ (无外部依赖，纯工具函数)
```

### 4.2 依赖原则

- ✅ **单向依赖**：上层依赖下层，下层不依赖上层
- ✅ **最小依赖**：只引入必要的头文件
- ✅ **驱动独立**：传感器驱动尽量自包含，减少对配置层的依赖

---

## 5. 扩展指南

### 5.1 添加新传感器

**步骤**：

1. **创建驱动文件**
   ```bash
   drivers/sensors/
   ├── xxx_driver.h
   └── xxx_driver.c
   ```

2. **实现驱动接口**
   ```c
   int XXX_Init(void);
   int XXX_Read(float *value);
   ```

3. **更新配置**
   ```c
   // config/app_config.h
   #define ENABLE_XXX  1
   ```

4. **更新数据结构**
   ```c
   // app/sensor_data.h
   typedef struct {
       // ...
       float xxx_value;
       int xxx_valid;
   } SensorData;
   ```

5. **集成主程序**
   ```c
   // main/landslide_main.c
   #if ENABLE_XXX
   #include "../drivers/sensors/xxx_driver.h"
   #endif
   
   // 初始化
   #if ENABLE_XXX
   XXX_Init();
   #endif
   
   // 读取
   #if ENABLE_XXX
   if (XXX_Read(&g_sensor_data.xxx_value) == 0) {
       g_sensor_data.xxx_valid = 1;
   }
   #endif
   ```

6. **更新构建配置**
   ```gn
   // BUILD.gn
   sources = [
       // ...
       "drivers/sensors/xxx_driver.c",
   ]
   ```

### 5.2 添加新通信模块

参考 `drivers/xl01/` 的实现，创建新的驱动模块。

---

## 6. 测试策略

### 6.1 单元测试

**可测试模块**：
- ✅ `utils/fifo.c` - 缓冲区逻辑
- ✅ `utils/watchdog_mgr.c` - 看门狗封装
- ✅ `drivers/sensors/*.c` - 传感器驱动（Mock I2C）
- ✅ `drivers/xl01/xl01_driver.c` - 通信驱动（Mock UART）

**测试框架建议**：
- Unity（轻量级C测试框架）
- CMock（Mock生成工具）

### 6.2 集成测试

**测试场景**：
1. 虚拟数据通信测试
2. 单传感器集成测试
3. 多传感器集成测试
4. ACK机制测试
5. 丢包恢复测试
6. 长时间稳定性测试

---

## 7. 最佳实践

### 7.1 代码规范

- ✅ 使用有意义的命名
- ✅ 函数长度不超过50行
- ✅ 文件长度不超过500行
- ✅ 添加必要的注释
- ✅ 使用 `#define` 定义常量，避免魔法数字

### 7.2 错误处理

- ✅ 返回值约定：0 = 成功，负数 = 错误
- ✅ 打印错误信息，便于调试
- ✅ 关键操作添加重试机制

### 7.3 资源管理

- ✅ 在 `Init()` 函数中申请资源
- ✅ 定期喂看门狗
- ✅ 使用 `LOS_Msleep()` 让出CPU

---

## 8. 性能优化

### 8.1 内存优化

- ✅ 使用固定大小缓冲区（1024字节FIFO）
- ✅ 避免动态内存分配
- ✅ 复用缓冲区

### 8.2 CPU优化

- ✅ 任务优先级合理分配
- ✅ UART轮询间隔优化（1ms）
- ✅ 上传间隔可配置（5秒默认）

### 8.3 功耗优化

- ✅ 可配置上传间隔
- ✅ 预留低功耗休眠接口
- ✅ GPS可选关闭（高功耗）

---

## 9. 故障排查

### 9.1 编译错误

**常见问题**：
- ❌ 头文件路径错误
- ❌ 宏定义缺失
- ❌ 函数名冲突

**解决方法**：
- ✅ 检查 `BUILD.gn` 中的 `sources` 列表
- ✅ 确保相对路径正确 (`../../config/`)
- ✅ 检查函数命名（如 `SystemInit` → `App_SystemInit`）

### 9.2 运行时错误

**常见问题**：
- ❌ 看门狗超时重启
- ❌ UART收不到数据
- ❌ ACK超时

**解决方法**：
- ✅ 调试时禁用看门狗
- ✅ 检查UART引脚连接
- ✅ 增加ACK超时时间

---

## 10. 总结

### 10.1 架构优势

| 方面 | 单体架构 | 模块化架构 |
|-----|---|---|
| **可维护性** | 低 | ✅ 高 |
| **可测试性** | 低 | ✅ 高 |
| **可扩展性** | 低 | ✅ 高 |
| **代码复用** | 低 | ✅ 高 |
| **团队协作** | 困难 | ✅ 容易 |
| **Bug定位** | 困难 | ✅ 容易 |

### 10.2 技术亮点

1. **职责清晰**：保持模块边界和接口清晰
2. **分层架构**：清晰的职责划分
3. **驱动抽象**：统一的接口设计
4. **配置集中**：易于管理和移植
5. **可测试性**：模块可独立测试

### 10.3 适用场景

- ✅ IoT传感器节点
- ✅ 无线数据采集
- ✅ 嵌入式系统开发
- ✅ 多传感器集成
- ✅ 团队协作开发

---

**版本**: v2.0  
**更新**: 2025-10-22

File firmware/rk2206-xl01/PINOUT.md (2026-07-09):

# RK2206 滑坡监测系统 - 当前引脚真值

## 适用范围

本文件只记录**当前工程应采用的单一引脚真值**。

如果其他 GPS / UART 方案文档与本文件冲突：

- 以本文件为准
- 以当前编译代码为准

## 1. 当前接口分配

| 模块 | 接口 | 引脚 | GPIO | 当前状态 |
| --- | --- | --- | --- | --- |
| XL01 | `EUART2_M1` | `PB2 / PB3` | `GPIO0_PB2 / GPIO0_PB3` | 已测试 |
| GPS | `EUART0_M0` | `PB6 / PB7` | `GPIO0_PB6 / GPIO0_PB7` | 当前代码真值，待真机复验 |
| MPU6050 / SHT30 | `EI2C0_M0` | `PB4 / PB5` | `GPIO0_PB4 / GPIO0_PB5` | 当前代码真值 |

## 2. 当前代码宏

```c
#define XL01_UART_ID        EUART2_M1
#define XL01_BAUDRATE       115200

#define GPS_UART_ID         EUART0_M0
#define GPS_BAUDRATE        9600

#define I2C_IDX             EI2C0_M0
#define I2C_BAUDRATE        EI2C_FRE_100K
```

## 3. 接线真值

### XL01

```text
XL01 RX -> PB2
XL01 TX -> PB3
XL01 VCC -> 3.3V
XL01 GND -> GND
```

### GPS

```text
GPS TX -> PB6
GPS RX -> PB7
GPS VCC -> 3.3V
GPS GND -> GND
```

### MPU6050 / SHT30

```text
SDA -> PB4
SCL -> PB5
VCC -> 3.3V
GND -> GND
```

## 4. 重要说明

### 4.1 当前为什么不是 A6 / A7 或 C6 / C7

当前并不是说 `A6/A7` 或 `C6/C7` 永远不可能使用，而是：

- 它们没有成为当前实际编译代码的统一真值
- 当前阶段不再按这些早期候选方案接线

### 4.2 当前为什么先以代码真值为准

当前真实参与编译的代码里：

- I2C 已迁到 `PB4 / PB5`
- GPS 当前写成 `PB6 / PB7`

因此当前工程真值应先统一到：

- GPS `PB6 / PB7`
- I2C `PB4 / PB5`

而不是继续保留多套候选文档。

## 5. 当前用途

本文件用于：

- 现场接线
- 代码修改前核对
- 真机 smoke 前确认

不再用于：

- 保留多个 GPS 候选方案
- 继续讨论早期引脚试配记录

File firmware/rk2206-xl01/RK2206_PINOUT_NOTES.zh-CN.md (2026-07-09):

# RK2206 v5.0 当前引脚配置（小凌派板）

## 版本信息
- **版本**: v5.0 GPS数据清洁优化版
- **日期**: 2025-10-24
- **固件**: 本地构建产物，保留在公开仓库之外

---

## 实际使用的引脚配置

| 模块 | 接口类型 | 引脚 | GPIO | I2C/UART地址 | 状态 |
|---|---|---|---|---|---|
| **XL01无线** | UART2_M1 | PB2(RX), PB3(TX) | GPIO0_PB2/3 | 115200波特率 | ✅ 已测试 |
| **MPU6050加速度** | I2C0_M0 | PB4(SDA), PB5(SCL) | GPIO0_PB4/5 | 0x68 @ 100kHz | ✅ 已测试 |
| **GPS定位** | UART0_M0 | PB6(TX), PB7(RX) | GPIO0_PB6/7 | 9600波特率 | ✅ 已测试 |
| **SHT30温湿度** | I2C0_M0 | PB4(SDA), PB5(SCL) | GPIO0_PB4/5 | 0x44 @ 100kHz | ⚠️ 未启用 |

---

## 详细接线图

### 1️⃣ XL01 无线通信模块
```
小凌派RK2206              XL01模块
┌─────────┐             ┌──────┐
│ PB3(TX) ├─────────────┤ RX   │  (白线) - 交叉连接
│ PB2(RX) ├─────────────┤ TX   │  (绿线) - 交叉连接
│ 3.3V    ├─────────────┤ VCC  │  (红线)
│ GND     ├─────────────┤ GND  │  (黑线)
└─────────┘             └──────┘
               天线 → 必须连接！
```
**代码配置**:
```c
#define XL01_UART_ID    EUART2_M1
#define XL01_BAUDRATE   115200
```

---

### 2️⃣ MPU6050 加速度/陀螺仪传感器
```
小凌派RK2206              MPU6050
┌─────────┐             ┌──────┐
│ PB4(SDA)├─────────────┤ SDA  │  - I2C数据线
│ PB5(SCL)├─────────────┤ SCL  │  - I2C时钟线
│ 3.3V    ├─────────────┤ VCC  │  
│ GND     ├─────┬───────┤ GND  │
└─────────┘     └───────┤ AD0  │  ← AD0接GND (地址0x68)
                        └──────┘
```
**代码配置**:
```c
#define I2C_IDX             EI2C0_M0    // PB4/PB5
#define I2C_BAUDRATE        EI2C_FRE_100K
#define MPU6050_I2C_ADDR    0x68
```
**注意**: AD0引脚必须接GND，设置地址为0x68

---

### 3️⃣ GPS 定位模块 (ATGM336H)
```
小凌派RK2206              GPS模块
┌─────────┐             ┌──────┐
│ PB7(RX) ├─────────────┤ TX   │  (橙色) - 交叉连接
│ PB6(TX) ├─────────────┤ RX   │  (白色) - 交叉连接
│ 3.3V    ├─────────────┤ VCC  │  (红色)
│ GND     ├─────────────┤ GND  │  (黑色)
└─────────┘             └──────┘
              天线 → 放室外定位！
```
**代码配置**:
```c
#define GPS_UART_ID     EUART0_M0   // PB6/PB7 (板子标注的UART口)
#define GPS_BAUDRATE    9600
```
**板子标注**: PB6/PB7在小凌派上标注为 **UART_TX / UART_RX**

---

### 4️⃣ SHT30 温湿度传感器 (共享I2C总线)
```
小凌派RK2206              SHT30
┌─────────┐             ┌──────┐
│ PB4(SDA)├─────────────┤ SDA  │  - 与MPU6050共享
│ PB5(SCL)├─────────────┤ SCL  │  - 与MPU6050共享
│ 3.3V    ├─────────────┤ VCC  │  
│ GND     ├─────┬───────┤ GND  │
└─────────┘     └───────┤ ADDR │  ← ADDR接GND (地址0x44)
                        └──────┘
```
**代码配置**:
```c
#define I2C_IDX             EI2C0_M0    // 与MPU6050共享
#define SHT30_I2C_ADDR      0x44
#define ENABLE_SHT30        0           // 当前未启用
```

---

## ⚙️ **当前系统配置 (app_config.h)**

```c
// 节点配置
#define NODE_ID             "A"

// 上传配置
#define UPLOAD_INTERVAL_MS  5000        // 5秒上传一次
#define MAX_RETRY_COUNT     3
#define ENABLE_ACK_CHECK    1

// 传感器启用状态
#define ENABLE_GPS          1           // ✓ 已启用
#define ENABLE_MPU6050      1           // ✓ 已启用
#define ENABLE_SHT30        0           // ✗ 未启用
#define ENABLE_VIRTUAL      0           // ✗ 禁用虚拟数据

// 看门狗
#define ENABLE_WATCHDOG     1
#define WATCHDOG_TIMEOUT    10          // 10秒
```

---

## 🔧 **引脚复用说明**

### I2C总线共享
- **PB4/PB5** 作为I2C0_M0总线，可同时连接：
  - MPU6050 (地址 0x68)
  - SHT30 (地址 0x44)
  - 两者地址不同，不会冲突 ✅

### UART引脚
- **PB2/PB3**: UART2_M1 → XL01通信
- **PB6/PB7**: UART0_M0 → GPS接收（板子标注口）

---

## ✅ **测试状态**

| 功能 | 状态 | 备注 |
|---|---|---|
| XL01发送数据 | ✅ | 透传模式正常 |
| MPU6050读取 | ✅ | 加速度/陀螺仪数据正常 |
| GPS定位 | ✅ | GNRMC/GNGGA解析成功 |
| 倾角计算 | ✅ | 基于MPU6050计算 |
| 数据上传 | ⚠️ | 中心节点未收到ACK |

---

## 📋 **串口输出示例**

```
[OK] XL01 initialized (Baudrate: 115200)
[GPS] Initializing UART0 (Baudrate: 9600)...
[OK] GPS initialized with NMEA parsing
[OK] I2C initialized
[OK] MPU6050 initialized successfully!

📡 GPS: $GNRMC,065453.000,A,2240.89491,N,11011.72413,E...
✓✓✓ GPS定位成功(RMC): 纬度=22.681582° 经度=110.195402° ✓✓✓

[SEND #3] 228 bytes ✗ FAILED ⚠️ WARNING!
  Temp:0.0°C Humi:0.0% Tilt:61.13°/15.61° GPS:(22.681581,110.195404) Bat:0%
```

---

## 已知问题

1. **GPS数据偶尔混乱** - v5.0已优化UART缓冲逻辑，过滤乱码
2. **中心节点不返回ACK** - 需检查中心节点配置或改为单向传输
3. **SHT30未启用** - 温湿度数据显示0.0

---

## 本地交付文件

1. **固件**: 本地构建产物，保留在公开仓库之外
2. **说明**: 以仓库内 README 和引脚文档为准
3. **引脚配置**: 本文件
4. **版本记录**: `VERSION.txt`（如本地工程提供）

---

**更新时间**: 2025-10-24

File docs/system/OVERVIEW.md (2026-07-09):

# System Overview

Landslide Monitoring V2 is an end-to-end monitoring system composed of field sensing nodes, an edge gateway, a Windows operator console, and carrier-board hardware assets.

## Maintained Product Surfaces

| Surface | Path | Role |
| --- | --- | --- |
| Windows desktop client | `apps/desktop-ui`, `apps/windows-shell` | Operator-facing UI and native Windows host. |
| RK3568 edge gateway | `edge/rk3568-gateway` | Serial collection, MQTT uplink, local health files, field-link supervision, and alarm actuation. |
| RK2206 field firmware | `firmware/rk2206-xl01` | Sensor acquisition, GPS/deformation handling, command ACKs, and telemetry envelope generation. |
| Carrier-board hardware | `hardware/carrier-board` | PCB layout notes, manufacturing package, schematic preview, BOM, and pick-and-place package. |
| Shared packages | `packages` | Lightweight validation and observability helpers used by edge services. |

## Runtime Flow

```text
RS485/GPS/SHT30/MPU6050 sensors
  -> RK2206 field node firmware
  -> XL01 / southbound serial link
  -> RK3568 field gateway
  -> MQTT / compatible monitoring API
  -> Windows desktop operator console
```

## Repository Scope

This repository publishes the maintained application source, hardware handoff assets, and operational documentation. Vendor SDK trees, credentials, generated caches, local logs, and site-specific configuration stay outside the public tree.

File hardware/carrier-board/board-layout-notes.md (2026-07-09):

# PCB Layout Module Carrier v7 Notes

Board reference size: 150mm x 100mm.

This is a placement guide for the hand-soldered module-carrier version. It is not a locked mechanical drawing. Before ordering PCBs, verify real module dimensions, socket spacing, pin 1 direction, and acrylic cover clearance.

## Placement Table

| Ref | Part | Suggested size | Suggested position | Notes |
|---|---|---:|---|---|
| J1 | XH2.54 2P battery input | about 12 x 8mm | left edge, x=4, y=18 | Side-entry opening faces board edge. Pin1 BAT+, pin2 BAT-. |
| SW1 | SS-12D10G5 power switch | 13.5 x 6.6mm | x=20, y=17.5 | Must be reachable from board top or acrylic cutout. |
| F1/Q1/D4/D5/C15/C16 | Input protection/filter | grouped | x=6-58, y=28-36 | Keep compact. C15 positive to VBAT_SW, negative to GND. |
| U1 | MP1584 5V module | 22.5 x 17mm | x=7, y=39 | Hand-solder, adjust output to 5.00V before soldering. |
| U2 | MP1584 3.3V module | 22.5 x 17mm | x=35, y=39 | Hand-solder, adjust output to 3.30V before soldering. |
| D1/R1 | Power LED/resistor | small | x=5, y=58 | Visible from edge/top. |
| U3 | DL-XLS1 | 18 x 27mm | x=69, y=10 | Keep antenna side near board edge. Avoid copper/metal in antenna keepout. |
| J2/J3/SW2 | DL-XLS1 CMD/USR/KEY | small | x=90, y=11-34 | Keep near DL-XLS1. Watch acrylic cover height. |
| J4 | GPS 1x4 female header | about 18 x 7mm | x=111, y=8 | Keep away from MP1584 switching modules. |
| J5/J8 + RK2206 | RK2206 projection | 72.5 x 60.7mm | x=34, y=37 | Largest mechanical constraint. Confirm pin1 and row spacing. |
| U4 | CJMCU-752 / SC16IS752 module socket | 24 x 23mm | x=112, y=31 | Measure 2x8 and 2x5 socket positions from real module before PCB order. |
| U5 | Isolated TTL-to-RS485 module 1 | 34 x 18mm | x=111, y=58 | VIN/TX/RX/GND on left, A+/B+/earth on right. |
| U6 | Isolated TTL-to-RS485 module 2 | 34 x 18mm | x=111, y=79 | Same as U5. |

## Routing Widths

| Net class | Suggested width |
|---|---:|
| VBAT_IN / VBAT_SW main power | 1.0-1.5mm |
| 5V_SYS | 0.8-1.0mm |
| 3V3_SYS | 0.6-0.8mm |
| GND | copper pour, with stitching vias |
| I2C_SDA / I2C_SCL | 0.2-0.3mm |
| UART TX/RX | 0.2-0.3mm |
| RS485 A/B | 0.3-0.5mm, short and parallel |

## Critical Checks Before PCB Order

- CJMCU-752 socket hole positions must be measured from the real module.
- RS485 isolated module footprint must match the vendor footprint: left TTL 2.54mm pads and right 5.08mm terminal/half-hole area.
- Use 3V3_SYS for RS485 module VIN unless module TX output is proven 3.3V-safe when powered by 5V.
- RS485 module UART wiring is crossed: module TX to SC16IS752 RX, module RX to SC16IS752 TX.
- Acrylic cover clearance must account for RK2206 height, female sockets, MP1584 modules, CJMCU-752 module, and RS485 modules.
- Keep MP1584 modules away from DL-XLS1 and GPS area.

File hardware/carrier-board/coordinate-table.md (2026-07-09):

# PCB Layout Coordinate Table v5

Origin: board top-left. Unit: mm. Board: 150 x 100.

| ID | Name | X | Y | W | H | Note |
|---|---|---:|---:|---:|---:|---|
| KO1 | RK2206 projection / no tall parts | 40 | 37 | 72.5 | 60.7 | 72.5 x 60.7 x 11.1mm |
| KO2 | DL-XLS1 antenna keepout | 101 | 3 | 31 | 11 | no copper, traces, screws, metal |
| KO3 | power tall-part zone | 3 | 3 | 32 | 94 | MP1584/switch/electrolytic outside RK projection |
| KO4 | RS485 field wiring zone | 123 | 36 | 26 | 58 | terminals/TVS/transceivers inside edge clearance |
| J1 | BAT_IN 2P | 5 | 8 | 11 | 9 | KF142V 5.08-2P approx 11x9 keepout |
| F1 | PPTC 1812 | 19 | 8 | 6 | 4 | 4.5x3.2 body; keepout 6x4 |
| Q1A | Input protection cluster | 28 | 6 | 14 | 10 | AO3401A+D4+D5+R11+C16, detail sheet shows subparts |
| SW1 | PWR_SW | 5 | 22 | 18 | 7 | side switch keepout, verify with chosen footprint |
| C15 | 100uF/25V | 25 | 22 | 8 | 8 | RVT1E101M0607 approx D6.3x7.7 |
| U1 | MP1584_5V | 5 | 36 | 22.5 | 17 | module 22.5x17 |
| U2 | MP1584_3V3 | 5 | 61 | 22.5 | 17 | module 22.5x17 |
| J4 | GPS 1x4 | 45 | 8 | 11 | 5 | 2.54mm 1x4 header |
| J2 | XLS1_CMD | 62 | 8 | 10 | 5 | 2.54mm 1x4 header |
| J3 | XLS1_USR | 62 | 20 | 10 | 5 | 2.54mm 1x4 header |
| U4 | SC16IS752 | 74 | 28 | 12 | 7 | TSSOP-28, detail sheet shows crystal/caps |
| Y1 | 14.7456MHz | 77 | 38 | 5 | 4 | 3225 crystal keepout |
| U3 | DL-XLS1 | 107 | 17 | 18 | 27 | 18x27 module |
| U5 | SP3485_CH1 | 127 | 43 | 7 | 7 | SOIC-8 keepout |
| D2 | SM712_CH1 | 136 | 43 | 4 | 5 | SOT-23 keepout |
| J6 | RS485_CH1 | 141 | 38 | 8 | 23 | 4P 5.08 terminal, depth approx 8-10, length approx 21 |
| U6 | SP3485_CH2 | 127 | 68 | 7 | 7 | SOIC-8 keepout |
| D3 | SM712_CH2 | 136 | 68 | 4 | 5 | SOT-23 keepout |
| J7 | RS485_CH2 | 141 | 64 | 8 | 23 | 4P 5.08 terminal, depth approx 8-10, length approx 21 |
| J5 | RK2206_IF_L | 44 | 52 | 4 | 35 | 1x12; actual position must match connector |
| J8 | RK2206_IF_R | 94 | 52 | 4 | 35 | 1x12; actual position must match connector |

## Detail Dimensions

| Part | Approx size / keepout | Note |
|---|---:|---|
| RK2206 | 72.5 x 60.7 x 11.1mm | projected no-tall-parts area |
| DL-XLS1 | 18 x 27mm | antenna side needs copper/traces/metal keepout |
| MP1584 module | 22.5 x 17mm | two modules |
| 4P 5.08 terminal | ~8-10mm depth, ~21-23mm length | verify exact footprint |
| J1 2P terminal | ~11 x 9mm keepout | verify exact footprint |
| F1 1812 | ~4.5 x 3.2mm body | keepout 6 x 4 |
| AO3401A SOT-23 | ~2.9 x 1.6mm body | Q1 |
| SMBJ15CA SMB | ~4.6 x 3.6mm body | D4 |
| BZT52C10 SOD-123 | ~2.7 x 1.6mm body | D5 |
| R/C 0805 | ~2.0 x 1.25mm body | R11/C16/C1/C2 etc. |
| C15 RVT1E101M0607 | D6.3 x 7.7mm | high component |
| SC16IS752 TSSOP-28 | ~12 x 7mm keepout | body about 9.7 x 4.4 |
| SP3485 SOIC-8 | ~7 x 7mm keepout | body about 4.9 x 3.9 |
| SM712 SOT-23 | ~4 x 5mm keepout | D2/D3 |
| Y1 3225 | ~5 x 4mm keepout | body 3.2 x 2.5 |

## Trace Width Targets

| Net | Width | Note |
|---|---:|---|
| VBAT main rails | 1.2~1.5mm | J1/F1/Q1/SW1/MP1584 input |
| RS485 terminal V+ | 1.0~1.2mm | sensor supply to J6/J7 |
| 5V_SYS | 0.8~1.0mm | GPS/RK2206 |
| 3V3_SYS | 0.5~0.8mm | DL-XLS1/U4/U5/U6 |
| I2C/UART/DE/TP | 0.20~0.25mm | normal digital signals |
| TSSOP escape | 0.15~0.18mm | only short U4 escape, widen after escape |
| RS485 A/B | 0.25~0.30mm | gap 0.25~0.40mm, route parallel |
| XTAL1/XTAL2 | 0.15~0.20mm | very short, away from MP1584 |
| GND | top/bottom pours | many GND vias around U4/U5/U6 |

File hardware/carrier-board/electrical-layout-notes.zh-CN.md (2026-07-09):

• 下面按你当前版本，从原理图到 PCB 的完整流程走。

  1. 电源输入

  新增电池接口：

  J_BAT
  1  VBAT_3S
  2  GND

  VBAT_3S 是 3S2P 电池原压：

  约 9V~12.6V

  2. 总电源开关

  你已经添加开关，按这个接：

  SW_PWR
  COM  -> VBAT_3S
  OUT  -> VBAT_SW
  NC   -> 不接
  固定脚 -> 不接，只做机械固定

  后面所有电源都从 VBAT_SW 走。

  3. 两个 MP1584 模块

  5V 模块：

  U_BUCK_5V
  IN+  -> VBAT_SW
  IN-  -> GND
  OUT+ -> 5V_SYS
  OUT- -> GND

  3.3V 模块：

  U_BUCK_3V3
  IN+  -> VBAT_SW
  IN-  -> GND
  OUT+ -> 3V3_SYS
  OUT- -> GND

  加测试点：

  TP_VBAT_SW
  TP_5V_SYS
  TP_3V3_SYS
  TP_GND

  4. RS485 传感器电源

  不用稳压 12V，直接用开关后的电池电压：

  VBAT_SENSOR = VBAT_SW

  端子：

  J_RS485_1
  1  VBAT_SENSOR
  2  GND
  3  RS4851_A
  4  RS4851_B
  5  SHIELD

  J_RS485_2
  1  VBAT_SENSOR
  2  GND
  3  RS4852_A
  4  RS4852_B
  5  SHIELD

  5. DL-XLS1

  按你已建好的封装和符号接：

  pin8   -> 3V3_SYS
  pin9   -> GND
  pin11  USR_RX <- DL_RX_FROM_MCU
  pin12  USR_TX -> DL_TX_TO_MCU
  pin10  KEY -> 按键到 GND，或测试点
  pin17  CMD_TX -> XLS1_CMD_TX 测试/配置口
  pin18  CMD_RX -> XLS1_CMD_RX 测试/配置口
  pin1   NC
  pin2~7 必须悬空
  pin13~16 UIO0~UIO3 可悬空或测试点

  对应 RK2206：

  DL-XLS1 pin12 USR_TX -> RK2206 PB2 / MCU_RX
  DL-XLS1 pin11 USR_RX <- RK2206 PB3 / MCU_TX

  建议加配置口：

  J_XLS1_CMD
  1  3V3_SYS
  2  GND
  3  XLS1_CMD_TX
  4  XLS1_CMD_RX

  6. GPS

  J_GPS
  1  5V_SYS
  2  GND
  3  GPS_TX_TO_MCU
  4  GPS_RX_FROM_MCU

  对应 RK2206：

  GPS_TX_TO_MCU -> PB6 / MCU_RX
  GPS_RX_FROM_MCU <- PB7 / MCU_TX

  7. SC16IS752 双串口扩展

  U_SC16IS752
  VCC   -> 3V3_SYS
  GND   -> GND
  SDA   -> I2C_SDA / PB4
  SCL   -> I2C_SCL / PB5
  A0    -> GND
  A1    -> GND
  RESET -> 3V3_SYS，经 10k 上拉
  IRQ   -> 测试点或 RK2206 空闲 GPIO

  I2C 上拉：

  R_SDA 4.7k：I2C_SDA -> 3V3_SYS
  R_SCL 4.7k：I2C_SCL -> 3V3_SYS

  串口 A：

  TXA -> RS485_1_DI
  RXA <- RS485_1_RO
  RTSA/GPIOA -> RS485_1_DE

  串口 B：

  TXB -> RS485_2_DI
  RXB <- RS485_2_RO
  RTSB/GPIOB -> RS485_2_DE

  8. 两路 RS485 收发器

  第 1 路：

  U_RS485_1
  VCC -> 3V3_SYS
  GND -> GND
  DI  <- RS485_1_DI
  RO  -> RS485_1_RO
  DE  <- RS485_1_DE
  /RE <- RS485_1_DE
  A   -> RS4851_A
  B   -> RS4851_B

  第 2 路：

  U_RS485_2
  VCC -> 3V3_SYS
  GND -> GND
  DI  <- RS485_2_DI
  RO  -> RS485_2_RO
  DE  <- RS485_2_DE
  /RE <- RS485_2_DE
  A   -> RS4852_A
  B   -> RS4852_B

  每路建议：

  SM712 TVS：A/B 到 GND
  120Ω 终端电阻：A 和 B 之间，最好用跳帽控制
  偏置电阻预留：A 上拉到 3V3_SYS，B 下拉到 GND
  测试点：A、B、GND

  9. 日志调试口

  保留：

  J_DEBUG
  1  3V3_SYS
  2  GND
  3  LOG_TX_TO_USB
  4  LOG_RX_FROM_USB

  对应：

  PC3 / MCU_TX -> LOG_TX_TO_USB
  PC2 / MCU_RX -> LOG_RX_FROM_USB

  10. 必删旧模块

  删除旧的：

  J_XL01 插针版
  J_SHT30
  J_MPU6050
  旧 SHT30/MPU6050 去耦电容
  旧 I2C 传感器标签

  保留 I2C 上拉，但改给 SC16IS752 用。

  11. PCB 布局顺序

  按这个顺序放：

  1. J_BAT、电源开关、两个 MP1584 放电源区
  2. RS485 两个端子放板边
  3. RS485 收发器和 SM712 靠近端子
  4. SC16IS752 靠近 RS485 收发器
  5. DL-XLS1 放板边，天线区域朝外，禁布铜
  6. GPS 接口远离 MP1584 和 DL-XLS1 天线
  7. RK2206 接口按机械位置放
  8. J_DEBUG 放边缘或测试点形式

  12. PCB 关键规则

  DL-XLS1 天线区域不要铺铜、不要走线、不要放金属件
  MP1584 远离 GPS 和 DL-XLS1
  RS485 A/B 差分线尽量并行、靠近端子加 TVS
  VBAT_SENSOR 线宽加粗
  5V_SYS、3V3_SYS 线宽不要太细
  GND 尽量整面铺铜
  开关和端子机械件周围留空间

  13. 下板前检查

  ERC/DRC 后人工检查：

  VBAT_3S 没有直接短到 GND
  5V_SYS 没有短到 3V3_SYS
  DL-XLS1 pin8 是 3V3，不是 5V
  DL-XLS1 pin9 是 GND
  DL-XLS1 pin11/12 UART 交叉正确
  pin2~7 悬空
  SC16IS752 是 3V3 供电
  RS485 芯片是 3V3 供电
  RS485 端子电源是 VBAT_SENSOR，不是 5V_SYS
  MP1584 方向 IN/OUT 没反
  开关 OFF 时后级 VBAT_SW 断开

  14. 第一次上电顺序

  1. 不插传感器，不插 RK2206，只上电池
  2. 测 VBAT_SW
  3. 测 5V_SYS = 5.00V
  4. 测 3V3_SYS = 3.30V
  5. 再焊/插 DL-XLS1、SC16IS752、RS485 芯片
  6. 最后接 GPS 和 RS485 传感器

  下一步你把当前原理图截图发我，优先看：电源开关、MP1584、DL-XLS1、SC16IS752、RS485 这五块。

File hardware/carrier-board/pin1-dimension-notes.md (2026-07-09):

# PCB Layout Pin1 and Dimensions v6

Origin: board top-left. Unit: mm. Board: 150 x 100.

| ID | Name | X | Y | W | H | Pin1 / direction | Note |
|---|---|---:|---:|---:|---:|---|---|
| KO1 | RK2206 projection / no tall parts | 40 | 37 | 72.5 | 60.7 | - | 72.5 x 60.7 x 11.1mm |
| KO2 | DL-XLS1 antenna keepout | 101 | 3 | 31 | 11 | - | no copper / no traces / no metal |
| KO3 | Power tall-parts zone | 3 | 3 | 32 | 94 | - | MP1584, switch, C15 outside RK projection |
| KO4 | RS485 wiring zone | 123 | 36 | 26 | 58 | - | terminal -> TVS -> SP3485 |
| J1 | BAT_IN 2P | 5 | 8 | 11 | 9 | pin1上侧 | pin1=BAT+ |
| F1 | PPTC 1812 | 19 | 8 | 6 | 4 | 无极性/见细图 | no polarity |
| Q1A | input protect cluster | 28 | 6 | 14 | 10 | 无极性/见细图 | detail: Q1/D4/D5/R11/C16 |
| SW1 | power switch | 5 | 22 | 18 | 7 | pin1左侧 | pin2=COM |
| C15 | 100uF/25V | 25 | 22 | 8 | 8 | pin1上侧 | + to VBAT_SW |
| U1 | MP1584_5V | 5 | 36 | 22.5 | 17 | pin1左侧 | IN left, OUT right |
| U2 | MP1584_3V3 | 5 | 61 | 22.5 | 17 | pin1左侧 | IN left, OUT right |
| J4 | GPS 1x4 | 45 | 8 | 11 | 5 | pin1左侧 | pin1=5V_SYS |
| J2 | XLS1_CMD | 62 | 8 | 10 | 5 | pin1左侧 | pin1=3V3_SYS |
| J3 | XLS1_USR | 62 | 20 | 10 | 5 | pin1左侧 | pin1=3V3_SYS |
| U4 | SC16IS752 | 74 | 28 | 12 | 7 | pin1左上 | pin1 top-left |
| Y1 | 14.7456MHz | 77 | 38 | 5 | 4 | pin1左下 | pin1->XTAL1 |
| U3 | DL-XLS1 | 107 | 17 | 18 | 27 | pin1左上 | pin1 top-left |
| U5 | SP3485_CH1 | 127 | 43 | 7 | 7 | pin1左上 | pin1 RO top-left |
| D2 | SM712_CH1 | 136 | 43 | 4 | 5 | pin1下侧 | pin3 GND side per footprint |
| J6 | RS485_CH1 4P | 141 | 38 | 8 | 23 | pin1上侧 | pin1=V+ |
| U6 | SP3485_CH2 | 127 | 68 | 7 | 7 | pin1左上 | pin1 RO top-left |
| D3 | SM712_CH2 | 136 | 68 | 4 | 5 | pin1下侧 | pin3 GND side per footprint |
| J7 | RS485_CH2 4P | 141 | 64 | 8 | 23 | pin1上侧 | pin1=V+ |
| J5 | RK2206_IF_L | 44 | 52 | 4 | 35 | pin1上侧 | pin1 top |
| J8 | RK2206_IF_R | 94 | 52 | 4 | 35 | pin1上侧 | pin1 top |

## Trace Width Targets

| Net | Width | Note |
|---|---:|---|
| VBAT main rails | 1.2~1.5mm | J1/F1/Q1/SW1/MP1584 input |
| RS485 terminal V+ | 1.0~1.2mm | sensor supply to J6/J7 |
| 5V_SYS | 0.8~1.0mm | GPS/RK2206 |
| 3V3_SYS | 0.5~0.8mm | DL-XLS1/U4/U5/U6 |
| I2C/UART/DE/TP | 0.20~0.25mm | normal digital signals |
| TSSOP escape | 0.15~0.18mm | short local U4 escape only |
| RS485 A/B | 0.25~0.30mm | gap 0.25~0.40mm, parallel |
| XTAL1/XTAL2 | 0.15~0.20mm | very short, away from MP1584 |
| GND | top/bottom pours | many GND vias around U4/U5/U6 |

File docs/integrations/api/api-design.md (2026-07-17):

---
title: api-design
type: note
permalink: landslide-monitoring-v2-mainline/docs/integrations/api/api-design
---

# API 接口设计（v2）

本版本与后端 v2 架构一致：`MQTT + Kafka + ClickHouse(遥测) + PostgreSQL(元数据/规则/告警) + Redis`，并以“稀疏指标、不写死、可扩展”为前提。

机器可读契约入口（用于生成 SDK/Mock 与做契约校验）：

- `docs/integrations/api/openapi.yaml`

## 设计原则

1. RESTful 风格：资源导向，HTTP 动词语义明确
2. 契约优先：API 文档先行，前端/Flutter 只依赖 API
3. 统一响应：结构化返回与标准化错误码
4. 统一 ID：所有业务 ID 使用 UUID 字符串
5. 时间统一：RFC3339 UTC（`2025-12-15T10:00:00Z`）

## 基础信息

- Base URL：`/api/v1`
- 认证方式：Bearer Token（JWT）
- 数据格式：JSON

## 统一响应格式

成功响应：
```json
{
  "success": true,
  "code": 200,
  "message": "ok",
  "data": {},
  "timestamp": "2025-12-15T10:00:00Z",
  "traceId": "req_01J..."
}
```

分页响应：
```json
{
  "success": true,
  "code": 200,
  "message": "ok",
  "data": {
    "list": [],
    "pagination": {
      "page": 1,
      "pageSize": 20,
      "total": 100,
      "totalPages": 5
    }
  },
  "timestamp": "2025-12-15T10:00:00Z",
  "traceId": "req_01J..."
}
```

错误响应：
```json
{
  "success": false,
  "code": 400,
  "message": "参数错误",
  "error": {
    "field": "endTime",
    "detail": "endTime 必须大于 startTime"
  },
  "timestamp": "2025-12-15T10:00:00Z",
  "traceId": "req_01J..."
}
```

## 错误码约定

- `200`：成功
- `400`：参数错误
- `401`：未认证
- `403`：无权限
- `404`：资源不存在
- `409`：资源冲突
- `429`：限流
- `500`：服务端错误

## API 模块

- `01-auth.md`：认证接口
- `02-users.md`：用户管理
- `03-devices.md`：设备管理（UUID deviceId + 设备身份包下发）
- `04-stations.md`：站点管理（UUID stationId）
- `05-data.md`：数据接口（稀疏指标：sensorKey + metrics）
- `06-alerts.md`：告警接口（版本化规则 + 事件化告警）
- `07-system.md`：系统接口（配置/日志/状态）

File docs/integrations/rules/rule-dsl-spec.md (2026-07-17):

---
title: rule-dsl-spec
type: note
permalink: landslide-monitoring-v2-mainline/docs/integrations/rules/rule-dsl-spec
---

# 规则 DSL 规范（v1，可实现且可扩展）

本 DSL 用于把“告警逻辑”做成数据（存库、版本化、可回放），避免硬编码。目标是：**多规则 + 多传感器组合 + 窗口 + 防抖回差 + 缺失策略 + 可插拔算法/AI**，并且不影响写入链路稳定性。

> 约定：所有时间均为 RFC3339 UTC；所有 ID（deviceId/stationId/ruleId/alertId）均为 UUID 字符串。

机器可读校验：

- JSON Schema（用于校验 DSL JSON 是否结构正确）：`docs/integrations/rules/rule-dsl.schema.json`

---

## 1. 总体结构（RuleVersion）

每次修改规则都创建一个新的 `ruleVersion`（不覆盖旧版本）。一个规则版本（JSON）建议结构如下：

```json
{
  "dslVersion": 1,
  "name": "位移趋势异常",
  "scope": {
    "type": "device",
    "deviceId": "2c1f2d8e-2bb7-4f58-bb6a-6c2a0f4a7a4c"
  },
  "enabled": true,
  "severity": "high",
  "cooldown": { "minutes": 30 },
  "timeField": "received",
  "missing": { "policy": "ignore" },
  "when": {
    "op": "AND",
    "items": [
      { "sensorKey": "displacement_velocity_mm_h", "operator": ">=", "value": 0.3 }
    ]
  },
  "window": { "type": "duration", "minutes": 10, "minPoints": 6 },
  "hysteresis": { "recoverBelow": 0.2 },
  "actions": [
    { "type": "emit_alert", "titleTemplate": "位移速率异常", "messageTemplate": "速率={{value}}mm/h" }
  ]
}
```

### 字段解释（必须项）

- `dslVersion`：DSL 版本号（v1=1）
- `scope`：适用范围（device/station/global）
- `enabled`：是否启用
- `severity`：告警级别（low/medium/high/critical）
- `when`：条件树（AND/OR/NOT）

### 可选项（强烈建议）

- `window`：窗口（持续时间/点数）
- `hysteresis`：回差（恢复阈值）
- `cooldown`：冷却时间（避免重复触发）
- `missing`：缺失策略（ignore/treat_as_fail/raise_missing_alert）
- `actions`：触发后的动作（至少支持 emit_alert；可扩展推送/写影子/触发命令等）

---

## 2. Scope（规则适用范围）

```json
{ "type": "device", "deviceId": "..." }
{ "type": "station", "stationId": "..." }
{ "type": "global" }
```

语义：
- `device`：仅对单设备生效
- `station`：站点下所有设备生效（后端需要能通过 stationId 找到设备集合）
- `global`：全局生效（谨慎使用）

---

## 3. 时间字段（timeField）

```json
{ "timeField": "received" }
{ "timeField": "event" }
```

语义：
- `received`（默认）：使用服务端接收时间窗口（推荐，抗设备漂移/乱序）
- `event`：使用设备时间窗口（仅在设备时间可靠时启用）

---

## 4. Missing Policy（缺失策略）

```json
{ "missing": { "policy": "ignore" } }
{ "missing": { "policy": "treat_as_fail" } }
{ "missing": { "policy": "raise_missing_alert", "sensorKeys": ["displacement_mm"] } }
```

语义：
- `ignore`：缺失不参与计算（最宽松）
- `treat_as_fail`：缺失视为“不满足条件”（适合严格规则）
- `raise_missing_alert`：缺失触发“传感器缺失/数据中断”类事件

注意：
- 设备可能天然没有某传感器，缺失是否异常应由 `device_sensors`（声明）辅助判断（实现阶段）。

---

## 5. Window（窗口）

窗口用于把规则从“瞬时阈值”提升为“持续/趋势/统计”。

### 5.1 按持续时间

```json
{ "window": { "type": "duration", "minutes": 10, "minPoints": 6 } }
```

- `minutes`：窗口长度
- `minPoints`：最少点数（不足则按 missing policy 处理）

### 5.2 按点数

```json
{ "window": { "type": "points", "points": 30 } }
```

---

## 6. Hysteresis（回差/防抖）

回差用于避免指标在阈值附近抖动导致频繁触发/恢复。

```json
{ "hysteresis": { "recoverBelow": 0.2 } }
{ "hysteresis": { "recoverAbove": 1.2 } }
```

语义：
- 对于 `>= threshold` 触发的规则，通常用 `recoverBelow`
- 对于 `<= threshold` 触发的规则，通常用 `recoverAbove`

实现要求：
- 规则引擎需要维护每个 `alert_id` 的当前状态（active/acked/resolved）与恢复条件。

---

## 7. Conditions（条件树）

### 7.1 逻辑节点

```json
{ "op": "AND", "items": [ ... ] }
{ "op": "OR", "items": [ ... ] }
{ "op": "NOT", "item": { ... } }
```

### 7.2 叶子节点：比较（sensor）

```json
{
  "sensorKey": "displacement_mm",
  "operator": ">=",
  "value": 1.5
}
```

operator 支持：
- `> >= < <= == !=`
- `between`：`{ "operator":"between", "min": 1.0, "max": 2.0 }`

类型规则：
- `float/int/bool/string` 均可（以 `sensors.data_type` 为准）
- `==`/`!=` 可用于字符串状态（如 `relay_state == "ON"`），但不建议高频字符串参与复杂聚合

---

## 8. 统计/派生条件（聚合与趋势）

为了支持“窗口内均值/斜率/变化量”等组合规则，提供 `metric` 节点：

### 8.1 聚合函数

```json
{
  "metric": {
    "sensorKey": "displacement_mm",
    "agg": "avg",
    "window": { "type": "duration", "minutes": 10 }
  },
  "operator": ">=",
  "value": 1.5
}
```

agg 支持（v1 建议实现最小集）：
- `last`（窗口最后一个值）
- `min` / `max` / `avg`
- `delta`（last - first）
- `slope`（简单线性趋势斜率；v1 约定单位为“每分钟变化量”，即 (last-first)/Δt(min)）

说明：
- `metric.window` 可省略，默认使用规则 `window`
- 聚合只对数值型 sensor 生效；字符串/bool 只支持 `last`

---

## 9. Algorithm/AI 输出作为条件（可选）

将 AI 预测做成异步 provider，规则通过引用预测结果参与判断。

```json
{
  "algo": {
    "provider": "predict_displacement",
    "sensorKey": "displacement_mm",
    "horizon": "6h"
  },
  "operator": ">=",
  "value": 2.0
}
```

要求：
- algo 结果必须包含 `prediction` 与 `confidence`
- 若 algo 不可用/超时：按规则策略降级（默认“不触发”，并在 evidence 中记录 `algo_unavailable=true`）

---

## 10. Cooldown（冷却）

```json
{ "cooldown": { "minutes": 30 } }
```

语义：
- 同一规则在同一 `scope` 内，触发后在 cooldown 时间内不重复触发（但允许 UPDATE）

---

## 11. Actions（动作）

v1 最小动作：

```json
{ "type": "emit_alert", "titleTemplate": "xxx", "messageTemplate": "yyy" }
```

扩展动作（预留）：
- `notify`：推送策略（App/SMS/Email）——建议由规则元数据决定，而不是硬编码
- `write_device_state`：更新影子（谨慎）
- `send_device_command`：下发控制命令（需要权限与幂等）

模板变量建议（实现阶段）：
- `{{deviceId}}`、`{{stationId}}`、`{{sensorKey}}`、`{{value}}`、`{{ts}}`、`{{window.avg}}`、`{{window.max}}` 等

---

## 12. 与数据库表的映射（v2）

建议存储方式：
- `alert_rules`：规则容器（scope + enabled + created_by）
- `alert_rule_versions`：版本内容（将整个 DSL JSON 存到 `conditions/window/hysteresis/...` 或新增一个 `dsl_json` 字段）

告警输出：
- 写入 `alert_events`（事件化），并推送 Kafka `alerts.events.v1`

---

## 13. 校验清单（避免遗漏）

创建/更新规则时必须校验：

- dslVersion 是否支持
- scope 是否有效（deviceId/stationId 存在）
- when 语法是否正确（AND/OR/NOT、叶子节点字段完整）
- sensorKey 是否存在于 `sensors` 字典（允许先注册字典再用）
- dataType 与 operator/value 是否匹配
- window/hysteresis/cooldown 参数范围是否合理（非负、上限保护）

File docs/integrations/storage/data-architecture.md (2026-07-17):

---
title: data-architecture
type: note
permalink: landslide-monitoring-v2-mainline/docs/integrations/storage/data-architecture
---

# 存储设计（PostgreSQL + ClickHouse，不写死）

目标：业务数据强一致、遥测数据高吞吐与高效聚合；新增传感器/指标不频繁改表结构。

## 1. PostgreSQL（元数据/规则/告警/权限）

### 核心表（建议 v1 最小集合）

- `users`、`roles`、`user_roles`
- `stations`
- `devices`
  - `device_id`（PK）
  - `status`（inactive/active/revoked）
  - `secret_hash`（只存 hash）
  - `last_seen_at`
  - `metadata_json`（JSONB，用于可扩展字段：型号/固件/采样率/安装信息）
- `sensors`（字典表，全局指标定义）
  - `sensor_key`（唯一，如 `displacement_mm`）
  - `unit`、`data_type`（float/int/bool/string）
  - `min/max`、`description`、`tags`（JSONB/数组）
- `device_sensors`（可选：声明设备“应有”哪些传感器）
- `alert_rules`、`alert_rule_versions`
  - 规则必须版本化（`rule_version`），避免后续无法解释历史告警
- `alert_events`
- `device_commands`（命令下发与状态）
- `audit_logs`

### 为什么需要 JSONB

在“指标可扩展、不写死”的前提下，一些变化快但不参与复杂查询的字段放 JSONB 更合适：

- 设备侧 meta：固件版本、采样间隔、供电方式、安装角度等
- 规则配置：DSL/条件树/窗口参数（仍需版本化）

## 2. ClickHouse（遥测时序）

### 设计原则

- 采用“稀疏点位模型”：每个 metric 一行，不做宽表大量列。
- 以 `received_ts` 为主时间轴（便于处理设备时间漂移、乱序）。
- 支持按设备/站点/传感器与时间范围查询、聚合。

### telemetry_raw（建议列）

- `received_ts` DateTime64
- `event_ts` Nullable(DateTime64)
- `device_id` String
- `sensor_key` LowCardinality(String)
- `seq` Nullable(UInt64)
- `value_f64` Nullable(Float64)
- `value_i64` Nullable(Int64)
- `value_str` Nullable(String)
- `value_bool` Nullable(UInt8)
- `quality` Nullable(UInt8)
- `schema_version` UInt16

说明：

- 同一条上报拆成多行：`metrics` 中每个 key 写一行到 `telemetry_raw`。
- 值类型通过不同列承载，避免把所有值塞 JSON（不利于聚合查询）。

### 聚合表（建议）

为了曲线性能与长期存储，建议规划聚合表（可后续实现）：

- `telemetry_agg_1m`：按 1 分钟聚合（avg/min/max/last）
- `telemetry_agg_1h`：按 1 小时聚合

聚合规则：

- 原始数据保留期较短（例如 30 天，可配置）
- 聚合数据保留更久（例如 1 年或更久）

## 3. “不写死”的落地方式

- 新增指标：只需在 PostgreSQL `sensors` 插入定义；设备开始上报该 `sensor_key` 即可落 ClickHouse。
- 删除/停用指标：在 `sensors` 标记 `disabled`（不要立刻删历史数据）。
- 设备缺传感器：不影响写入；是否异常由规则引擎决定（缺失策略配置化）。

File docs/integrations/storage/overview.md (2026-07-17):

---
title: overview
type: note
permalink: landslide-monitoring-v2-mainline/docs/integrations/storage/overview
---

# 存储设计概览（v2：PostgreSQL + ClickHouse）

本文件是存储层的对接契约入口（What/Why），DDL 见本目录下的 `postgres/` 与 `clickhouse/`。

## 设计原则

1. 不写死：新增/删除传感器不依赖频繁改表结构
2. 写路径削峰：设备高频上报先入 Kafka，再由写入服务批量落库
3. 读写分离：查询曲线/聚合走 ClickHouse；规则/告警/权限走 PostgreSQL
4. 可回放：规则版本化，支持按历史遥测回测/重算

## 存储分工

### PostgreSQL（强一致、业务与配置）

- 用户/权限：`users`、`roles`、`permissions`、`user_roles`
- 站点/设备/字典：`stations`、`devices`、`sensors`、`device_sensors`
- 设备影子与命令：`device_state`、`device_commands`
- 规则与告警：`alert_rules`、`alert_rule_versions`、`alert_events`、`alert_notifications`
- 审计与日志：`audit_logs`、`operation_logs`、`api_logs`、`system_configs`

### ClickHouse（遥测时序与聚合）

- `telemetry_raw`：稀疏点位模型（每个 metric 一行），支持高吞吐写入
- 聚合表（规划）：`telemetry_agg_1m`、`telemetry_agg_1h`（长期保留与快查询）

## “不写死”的关键点

- 遥测不在 PostgreSQL 存“宽表 iot_data”；新增指标只需向 `sensors` 字典表插入定义即可。
- `telemetry_raw` 按 `device_id + sensor_key + time` 存储；设备缺传感器时可不上传该 key。
- 设备控制/非数值状态不混入遥测曲线：通过 `device_state`（影子）与 `device_commands`（下发/回执）完成闭环。

## 目录结构

- PostgreSQL DDL：`docs/integrations/storage/postgres/tables/`
- ClickHouse DDL：`docs/integrations/storage/clickhouse/`

建议执行顺序（实现阶段）：

1. PostgreSQL：先执行 `postgres/tables/00-extensions.sql`，再按编号顺序执行其他 DDL
2. ClickHouse：执行 `clickhouse/01-telemetry.sql`，再按需引入聚合表

可选初始化数据：

- PostgreSQL：`postgres/tables/14-seed-data.sql`

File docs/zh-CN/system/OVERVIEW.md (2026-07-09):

# 系统总览

Landslide Monitoring V2 是一套端到端山体滑坡监测系统，包含现场传感节点、边缘网关、Windows 操作员客户端和载板硬件资料。

## 当前维护的产品面

| 产品面 | 路径 | 职责 |
| --- | --- | --- |
| Windows 桌面客户端 | `apps/desktop-ui`, `apps/windows-shell` | 操作员界面和原生 Windows 宿主。 |
| RK3568 边缘网关 | `edge/rk3568-gateway` | 串口采集、MQTT 上行、本地健康文件、现场链路监督和声光报警驱动。 |
| RK2206 现场固件 | `firmware/rk2206-xl01` | 传感器采集、GPS/形变处理、命令 ACK 和遥测封装。 |
| 载板硬件资料 | `hardware/carrier-board` | PCB 布局说明、打板包、原理图预览、BOM 和坐标文件。 |
| 共享工程包 | `packages` | 边缘服务使用的轻量校验和可观测性工具。 |

## 运行链路

```text
RS485/GPS/SHT30/MPU6050 传感器
  -> RK2206 现场节点固件
  -> XL01 / southbound 串口链路
  -> RK3568 field gateway
  -> MQTT / 兼容监测 API
  -> Windows 桌面操作员客户端
```

## 仓库范围

当前公开树发布维护中的应用源码、硬件交付资料和运维文档。供应商 SDK 全量目录、凭据、生成缓存、本地日志和点位特定配置不进入公开主分支。

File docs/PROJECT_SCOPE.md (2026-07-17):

# Project Scope

This repository is maintained as the public source tree for Landslide Monitoring V2, an end-to-end landslide monitoring system. The current `main` branch includes the actively maintained desktop client, cloud backend, RK3568 edge gateway services, RK2206 field firmware package, carrier-board hardware handoff assets, packaging scripts, and public documentation.

## Maintained Surface

- `apps/desktop-ui/` - React + Vite monitoring interface.
- `apps/windows-shell/` - WPF + WebView2 Windows host and installer resources.
- `services/` - cloud API, telemetry, alerting, prediction, and command-processing services.
- `infra/compose/` - single-host backend infrastructure and application deployment.
- `edge/rk3568-gateway/` - RK3568 edge services and deployment templates.
- `firmware/rk2206-xl01/` - RK2206 XL01 field-node firmware package.
- `hardware/carrier-board/` - carrier-board design and fabrication handoff assets.
- `packages/` and `libs/` - shared TypeScript packages used by edge and backend services.
- `scripts/desktop/` - desktop development, packaging, and verification scripts.
- `docs/` - public architecture, release, system, maintainer, and bilingual documentation.
- `.github/` - CI, issue templates, pull request template, and dependency automation.

## Repository Contents

The public tree includes:

- Application source for the maintained desktop, backend, edge, and firmware packages.
- Public examples and deployment templates.
- Firmware package files for integration with a compatible vendor build tree.
- Carrier-board design and fabrication handoff files.
- Build, lint, packaging, and verification scripts.
- Public documentation, issue templates, and pull request templates.

The following areas are outside the current public tree:

- Mobile applications and web dashboard application code.
- Vendor SDK trees.
- Generated release artifacts and local build outputs.
- Credentials, private endpoints, device passwords, and local environment files.
- Site-specific configuration, local logs, and runtime state.

## Maintenance Rule

New modules should include a README, local validation command, and CI coverage when practical. Areas that are not listed as maintained should be reintroduced through a documented public path before being treated as supported.

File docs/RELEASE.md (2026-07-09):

# Release Process

This document covers local validation and release preparation for the public repository. The current releaseable artifact is the Windows desktop package; edge services, firmware, and hardware assets are validated as source and handoff packages.

## Preflight

```powershell
npm install
npm audit
npm run lint
npm run build
npm run edge:build
npm run edge:lint
dotnet build .\apps\windows-shell\LandslideDesk.Win\LandslideDesk.Win.csproj -c Release
```

## Desktop Portable Package

```powershell
npm run desktop:publish
```

Default output:

- `artifacts/windows/portable/`
- `docs/reports/windows-package-latest.json`

## Verify A Desktop Package

```powershell
powershell -NoProfile -ExecutionPolicy Bypass -File .\scripts\desktop\verify-windows-package.ps1
```

## Optional Self-Contained Package

```powershell
powershell -NoProfile -ExecutionPolicy Bypass -File .\scripts\desktop\package-windows-self-contained.ps1
```

Default output:

- `artifacts/windows/self-contained/`
- `docs/reports/windows-self-contained-package-latest.json`

## Optional Installer

```powershell
powershell -NoProfile -ExecutionPolicy Bypass -File .\scripts\desktop\build-windows-installer.ps1
```

Installer generation requires Inno Setup 6. The script can download the WebView2 bootstrapper when needed.

## Edge Source Validation

The RK3568 edge services are validated as workspace packages:

```powershell
npm run edge:build
npm run edge:lint
```

Deployment to a physical RK3568 board requires local environment files and site-specific values that stay outside Git.

## Firmware And Hardware Review

- Confirm `firmware/rk2206-xl01/README.md`, `PINOUT.md`, and build metadata match the intended firmware package.
- Confirm `hardware/carrier-board/README.md` lists the current public handoff assets.
- Review schematic, BOM, pick-and-place orientation, and Gerber package before any fabrication order.

## GitHub Release Checklist

- CI is green on `main`.
- `npm audit` reports zero vulnerabilities.
- Desktop lint/build pass.
- Edge build/lint pass.
- Windows shell builds in Release mode.
- Desktop portable package is generated and verified.
- Firmware and hardware README files match the published package.
- `CHANGELOG.md` is updated.
- No generated artifacts, local environment files, credentials, private endpoints, or local field logs are committed.

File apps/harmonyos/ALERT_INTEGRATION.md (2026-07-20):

# HarmonyOS 告警联动接口

鸿蒙 App 不维护告警副本数据库。前台实时提醒、系统通知和告警地图都以服务器告警记录为准。

## 前台实时接口

App 登录并处于前台时连接：

```http
GET /api/v1/alerts/stream
Accept: text/event-stream
Authorization: Bearer <access-token>
Last-Event-ID: <last-event-id>
```

服务器使用 SSE 的 `alert` 事件发送告警。`id` 与数据中的 `eventId` 必须相同：

```text
id: 3cae3f27-63d2-4f2a-9fe1-54c57d727463
event: alert
data: {"type":"alert","eventId":"3cae3f27-63d2-4f2a-9fe1-54c57d727463","alertId":"d2e7ca4b-63e2-4d0a-9ff8-2f045eb6ed86","eventType":"ALERT_TRIGGER","severity":"high","title":"节点 B 倾角告警","message":"Y 轴倾角超过预警阈值","deviceId":"...","stationId":"...","evidence":{"latitude":24.43803,"longitude":118.09631},"createdAt":"2026-07-20T02:10:00.000Z"}
```

字段约定：

| 字段 | 必填 | 说明 |
| --- | --- | --- |
| `eventId` | 是 | 告警事件唯一 ID，用于 SSE 续传和客户端去重 |
| `alertId` | 是 | 告警生命周期 ID，用于详情、事件和地图接口 |
| `eventType` | 是 | `ALERT_TRIGGER`、`ALERT_UPDATE`、`ALERT_ACK` 或 `ALERT_RESOLVE` |
| `severity` | 是 | `low`、`medium`、`high` 或 `critical` |
| `title` | 是 | 面向值守人员的简短中文标题 |
| `message` | 是 | 告警原因和关键数值，不包含操作说明 |
| `deviceId` | 否 | 触发告警的监测设备 |
| `stationId` | 否 | 设备所属站点 |
| `evidence` | 否 | 告警证据；GPS 建议放在 `latitude`、`longitude`，也兼容 `gps.latitude`、`gps.longitude` |
| `createdAt` | 是 | ISO 8601 UTC 时间 |

`ALERT_TRIGGER` 会打开应用内强提醒并启动循环警报音；同一 `alertId` 的 `ALERT_UPDATE` 会原位更新原因和证据，升级到 `critical` 时重新打开强提醒并鸣响。`ALERT_ACK` 只记录值守人员已确认，不停止警报；只有同一 `alertId` 的 `ALERT_RESOLVE` 才会从当前面板或多节点队列中移除告警并停止对应提醒。值守人员可在告警未解除时暂时静音，但仍可随时查看告警和地图。

多个节点同时告警时，App 按 `alertId` 维护队列；后续更新替换同一条告警，不得按 `eventId` 追加成重复告警。比赛倾角告警的 `evidence` 使用 `baseline`、`current`、`delta`、`maxAxis`、`maxDeviationDeg` 和 `thresholds`，与 Windows 端共用同一字段。

## 地图依赖接口

点击“查看定位”后，App 使用同一 `alertId` 拉取：

```http
GET /api/v1/alerts/{alertId}/events
GET /api/v1/stations
GET /api/v1/devices
GET /api/v1/data/state/{deviceId}
GET /api/v1/data/series/{deviceId}
```

定位优先级为告警证据 GPS、设备实时 GPS、设备七日历史 GPS、最后有效 GPS、站点 GPS、厦门大学默认位置。

打开具体告警地图时，App 会在获得系统授权后读取手机当前定位，用于在本机计算与告警点或安全集合点的直线距离和相对方位。手机定位不上传服务器、不写入业务数据库，也不保存到本地快照；退出地图后只保留当前进程中的临时状态。

服务器核验过安全集合点后，可在告警 `evidence` 中下发：

| 字段 | 说明 |
| --- | --- |
| `safeZoneLatitude` / `safe_zone_latitude` | 安全集合点纬度 |
| `safeZoneLongitude` / `safe_zone_longitude` | 安全集合点经度 |
| `safeZoneName` / `safe_zone_name` | 面向人员显示的集合点名称 |
| `evacuationInstruction` / `evacuation_instruction` | 经现场核验的撤离说明 |

没有核验过的安全集合点或撤离路线时，App 只提示远离边坡与沟谷、遵循现场疏散标识，不根据手机与告警点的两点直线擅自生成逃生方向。

## 后台 Push

后台推送继续使用现有设备注册接口：

```http
POST /api/v1/push/devices
DELETE /api/v1/push/devices
```

Push `data` 至少携带 `alertId`；建议与 SSE 完全复用 `eventId`、`eventType`、`severity`、`deviceId` 和 `stationId`。用户点击系统通知进入 App 后，App 会先展示应用内告警面板，再由用户选择是否打开地图。服务器不需要为 App 新建业务数据库。

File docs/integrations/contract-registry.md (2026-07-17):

---
title: contract-registry
type: note
permalink: landslide-monitoring-v2-mainline/docs/integrations/contract-registry
---

# 契约注册表（Contract Registry，v2）

目标：提供“机器可读契约”的固定入口，避免全局搜索与多处散落导致遗漏。

## 1. HTTP（OpenAPI）

- `docs/integrations/api/openapi.yaml`

## 2. Rules（DSL）

- Rule DSL Schema：`docs/integrations/rules/rule-dsl.schema.json`

## 3. MQTT（设备协议）

- TelemetryEnvelope v1：`docs/integrations/mqtt/schemas/telemetry-envelope.v1.schema.json`
- PresenceEvent v1：`docs/integrations/mqtt/schemas/presence-event.v1.schema.json`
- DeviceCommand v1：`docs/integrations/mqtt/schemas/device-command.v1.schema.json`
- DeviceCommandAck v1：`docs/integrations/mqtt/schemas/device-command-ack.v1.schema.json`

## 4. Kafka（消息总线）

- telemetry.raw.v1：`docs/integrations/kafka/schemas/telemetry-raw.v1.schema.json`
- telemetry.dlq.v1：`docs/integrations/kafka/schemas/telemetry-dlq.v1.schema.json`
- alerts.events.v1：`docs/integrations/kafka/schemas/alerts-events.v1.schema.json`
- device.commands.v1：`docs/integrations/kafka/schemas/device-commands.v1.schema.json`
- device.command_acks.v1：`docs/integrations/kafka/schemas/device-command-acks.v1.schema.json`
- device.command_events.v1：`docs/integrations/kafka/schemas/device-command-events.v1.schema.json`
- ai.predictions.v1：`docs/integrations/kafka/schemas/ai-predictions.v1.schema.json`

## 5. Storage（DDL/表结构）

> Storage 属于“契约”的一部分：它约束了后端如何落库与回放。单机形态下，存储设计必须与 API/消息字段严格对齐。

- PostgreSQL DDL（按编号执行）：`docs/integrations/storage/postgres/tables/00-extensions.sql`
- ClickHouse DDL：`docs/integrations/storage/clickhouse/01-telemetry.sql`

## 6. 示例（Example Packs）

示例用于联调对齐与脚本校验：

- MQTT 示例：`docs/integrations/mqtt/examples/README.md`
- Kafka 示例：`docs/integrations/kafka/examples/README.md`
- Rules 示例：`docs/integrations/rules/examples/README.md`

## 7. Firmware（设备端适配规范）

设备端“运行行为/命令集合/采样上报策略”统一入口：

- `docs/integrations/firmware/README.md`

## 8. 使用规则

- 所有 schema 文件必须版本化（文件名含 `v1` / `v2`），新增字段必须考虑向后兼容。
- 文档示例（Markdown）必须与 schema 自洽；实现阶段建议写脚本从 Markdown 提取 JSON 块并做校验。

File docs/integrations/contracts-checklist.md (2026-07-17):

---
title: contracts-checklist
type: note
permalink: landslide-monitoring-v2-mainline/docs/integrations/contracts-checklist
---

# 契约完整性清单（v2：必须 100% 对齐）

本清单的目标是把“契约优先”落地为**可检查项**。当你认为“契约已完成”时，应逐项对照确认，避免遗漏导致前后端/设备/存储不一致。

建议配合脚本做机器检查：`python docs/tools/validate-contracts.py`（能覆盖 OpenAPI/示例/注册表路径等常见遗漏）。

## 1) API（HTTP）

权威入口：

- 文档入口：`docs/integrations/api/README.md`
- 机器可读：`docs/integrations/api/openapi.yaml`

完成标准（必须全部满足）：

- `openapi.yaml` 覆盖 `integrations/api/*.md` 中出现的所有端点与方法
- 所有端点均定义：
  - request（query/path/body）
  - response（成功/失败，至少 400/401/403/404/500）
  - 统一响应结构（含 `traceId`、UTC 时间）
- ID/时间/枚举值与 `docs/guides/standards/naming-conventions.md` 一致
- “写操作”明确幂等策略（如 commandId、ruleVersion）
- 明确查询保护（最大范围/最大点数/导出异步）

## 2) MQTT（设备对接）

权威入口：

- `docs/integrations/mqtt/README.md`

完成标准：

- Topic 规范明确（publish/subscribe、ACL 约束）
- TelemetryEnvelope v1 结构可机器校验（JSON Schema）
- 命令与回执消息结构可机器校验（JSON Schema）
- 身份鉴权与断电安全存储规范明确（device_id + secret + A/B slot）

## 3) Kafka（链路对接）

权威入口：

- `docs/integrations/kafka/README.md`

完成标准：

- Topic 列表明确（含版本号）
- 每个 topic 的 payload 有 schema（至少 JSON Schema/严格字段约定）
- DLQ 结构明确（reason_code、raw_payload、received_ts）
- 幂等键与分区键明确（device_id）

## 4) Storage（PostgreSQL + ClickHouse）

权威入口：

- `docs/integrations/storage/README.md`

完成标准：

- PostgreSQL DDL 可按编号顺序执行（含索引/约束/必要的 JSONB 字段）
- ClickHouse 表定义满足稀疏指标与 TTL/聚合规划
- 关键字段命名与 API/消息保持一致（尤其 device_id/deviceId 的映射规则要清楚）

## 5) Rules（DSL + 事件化告警）

权威入口：

- DSL 规范：`docs/integrations/rules/rule-dsl-spec.md`
- Schema：`docs/integrations/rules/rule-dsl.schema.json`

完成标准：

- DSL 示例可通过 schema 校验（至少 v1 核心示例）
- DSL 与落库映射一致（`alert_rule_versions.dsl_json` 必须保存完整 DSL）
- 事件化告警输出字段一致（alertId/ruleVersion/evidence）

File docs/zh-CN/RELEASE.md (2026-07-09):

# 发布流程

本文档说明公开仓库的本地验证和发布准备流程。当前可发布产物是 Windows 桌面包；边缘服务、固件和硬件资料作为源码与交付包进行验证。

## 发布前检查

```powershell
npm install
npm audit
npm run lint
npm run build
npm run edge:build
npm run edge:lint
dotnet build .\apps\windows-shell\LandslideDesk.Win\LandslideDesk.Win.csproj -c Release
```

## 桌面便携包

```powershell
npm run desktop:publish
```

默认输出：

- `artifacts/windows/portable/`
- `docs/reports/windows-package-latest.json`

## 验证桌面包

```powershell
powershell -NoProfile -ExecutionPolicy Bypass -File .\scripts\desktop\verify-windows-package.ps1
```

## 可选：自包含包

```powershell
powershell -NoProfile -ExecutionPolicy Bypass -File .\scripts\desktop\package-windows-self-contained.ps1
```

默认输出：

- `artifacts/windows/self-contained/`
- `docs/reports/windows-self-contained-package-latest.json`

## 可选：安装器

```powershell
powershell -NoProfile -ExecutionPolicy Bypass -File .\scripts\desktop\build-windows-installer.ps1
```

安装器生成需要 Inno Setup 6。脚本会在需要时下载 WebView2 bootstrapper。

## 边缘服务源码验证

RK3568 边缘服务作为 workspace 包验证：

```powershell
npm run edge:build
npm run edge:lint
```

部署到真实 RK3568 板卡需要本地环境文件和现场特定值，这些内容不能提交。

## 固件与硬件复核

- 确认 `firmware/rk2206-xl01/README.md`、`PINOUT.md` 和构建元数据匹配当前固件包。
- 确认 `hardware/carrier-board/README.md` 已列出当前公开交付资料。
- 打板前复核原理图、BOM、贴片方向和 Gerber 包。

## GitHub Release 检查清单

- `main` 分支 CI 通过。
- `npm audit` 为 0 个漏洞。
- 桌面端 lint/build 通过。
- 边缘端 build/lint 通过。
- Windows 壳 Release 构建通过。
- 桌面便携包已生成并验证。
- 固件和硬件 README 与发布包一致。
- `CHANGELOG.md` 已更新。
- 没有提交生成产物、本地环境文件、凭据、私有端点或本地现场日志。

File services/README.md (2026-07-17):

---
title: README
type: note
permalink: landslide-monitoring-v2-mainline/services/readme
---

# services/

云端后端服务层（可运行的进程/容器）。

原则：

- 以 “MQTT → Kafka → ClickHouse + Postgres” 为主链路（见 ADR）
- 边界层必须做输入校验（HTTP/MQTT/Kafka）
- 所有服务必须可观测（traceId、结构化日志、关键指标）

核心链路：

- `services/api/`：Windows 桌面端使用的 HTTP API
- `services/ingest/`：MQTT → Kafka（schema 校验、DLQ）
- `services/telemetry-writer/`：Kafka → ClickHouse（批量写入）
- `services/rule-engine-worker/`：规则执行与事件化告警
- `services/command-*`：设备命令下发、ACK、事件记录、通知与超时处理
- `services/ai-prediction-worker/`：区域模型匹配与预测
- `services/alert-notify-worker/`：告警通知
- `services/presence-recorder/`、`services/telemetry-dlq-recorder/`：在线状态与死信记录

单机部署入口位于 `infra/compose/`。RK3568 板端程序位于 `edge/rk3568-gateway/`，不在本目录重复维护。

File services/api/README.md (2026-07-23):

---
title: README
type: note
permalink: landslide-monitoring-v2-mainline/services/api/readme
---

# api-service（HTTP API）

本服务提供对外 HTTP API（`/api/v1`），严格对齐契约：`docs/integrations/api/openapi.yaml`。

## Hermes 任务代理

- `POST /api/v1/edge-ai/chat`：创建或继续对话，拆分并顺序执行只读白名单任务。
- `GET /api/v1/edge-ai/conversations`：查询当前用户的会话历史。
- `GET /api/v1/edge-ai/conversations/{conversationId}/messages`：查询消息和任务轨迹。
- `GET /api/v1/edge-ai/tasks/{taskId}`：查询单项任务结果。

会话和任务复用现有 PostgreSQL，DDL 位于
`docs/integrations/storage/postgres/tables/23-hermes-agent.sql`。RK3568 仅接收
`recheck`、`collect_logs`、`generate_report` 三类任务；重启、改阈值、网络
切换、设备控制和告警控制不会被自动下发。

本 PR 阶段只实现“数据查询最小闭环”：
- `GET /api/v1/data/state/{deviceId}`：查询设备最新状态（从 ClickHouse 计算得到，后续可切换到 Postgres shadow）
- `GET /api/v1/data/series/{deviceId}`：查询设备曲线（ClickHouse）

## 环境变量

参考：`services/api/.env.example`

## 本地运行（开发）

1) 安装依赖（仓库根目录）：
- `npm install`

2) 构建：
- `npm run build`

3) 进入目录运行：
- `cd services/api`
- 复制 `.env.example` 为 `.env` 并填写（不要提交 `.env`）
- `node dist/index.js`

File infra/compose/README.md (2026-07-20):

---
title: README
type: note
permalink: landslide-monitoring-v2-mainline/infra/compose/readme
---

# 单机部署（Docker Compose，v2）

本目录是单机部署的**权威物料**（实现阶段也会继续沿用），目标是：

- 一键启动基础设施（单机）
- 数据目录外置（便于备份/迁移/扩容）
- 运行步骤可复现（企业化要求：可交接、可回滚）

## 1) 目录说明

- `docker-compose.yml`：基础设施（EMQX/Kafka/ClickHouse/Postgres/Redis/Kafka UI）
- `docker-compose.app.yml`：应用层服务（API、采集/入库、规则与命令链路；旧 Web 仅在 `legacy-web` profile 下启用）
- `env.example`：环境变量模板（复制为 `.env`）
- `scripts/`：初始化与运维脚本（建 topic / 初始化 DDL / 离线备份）

说明：Kafka 采用 KRaft 单机模式（无 ZooKeeper），镜像为 `apache/kafka`。

## 2) 快速开始（Windows/PowerShell）

从仓库根目录执行：

1. 创建 env 文件（不要提交到仓库）：

   - `copy infra\\compose\\env.example infra\\compose\\.env`

2. 修改密码与数据目录：

   - 编辑 `infra/compose/.env`，至少修改 `PG_PASSWORD`、`CH_PASSWORD`、`REDIS_PASSWORD`、`EMQX_DASHBOARD_PASSWORD`
   - 如果后端开启登录，还需要设置 `JWT_ACCESS_SECRET`、`JWT_REFRESH_SECRET`
   - `DATA_DIR` 默认指向仓库根目录下 `data/`（推荐保留）

3. 启动基础设施：

   - `docker compose -f infra/compose/docker-compose.yml --env-file infra/compose/.env up -d`

4. 启动完整后端主链（推荐现场联调使用，不启动旧 Web）：

   - `docker compose -f infra/compose/docker-compose.yml -f infra/compose/docker-compose.app.yml --env-file infra/compose/.env up -d`

   如果确实需要旧 Web，再显式追加 `--profile legacy-web`；Windows 桌面端只需要连接 API。

> 如果出现镜像拉取超时（Docker Hub 在国内经常不稳定），请先在 Docker Desktop 配置 Registry Mirror，再重试。

### 2.1 可选边缘 AI

边缘 AI Worker 默认不启动，不影响采集、入库和规则告警。完成模型验证后再显式启用：

- 构建：`docker compose -f infra/compose/docker-compose.yml -f infra/compose/docker-compose.app.yml --env-file infra/compose/.env --profile edge-ai build ai-prediction-worker`
- 启动：`docker compose -f infra/compose/docker-compose.yml -f infra/compose/docker-compose.app.yml --env-file infra/compose/.env --profile edge-ai up -d ai-prediction-worker`
- 回退：`docker compose -f infra/compose/docker-compose.yml -f infra/compose/docker-compose.app.yml --env-file infra/compose/.env --profile edge-ai stop ai-prediction-worker`

该 Worker 限制为 `0.5 CPU / 384 MB`，训练查询限制单线程、30 秒和 256 MB；停止它不会停止 Kafka、ClickHouse、遥测写入或规则引擎。详细边界见 `docs/system/EDGE_AI_RUNBOOK.md`。

如果生产服务器保留的是不可整体替换的部署快照，先加载已验证镜像，再单独使用 `docker-compose.edge-ai.runtime.yml` 接入现有 Docker 网络。该运行清单不会定义或重建任何核心容器。

5. 初始化数据库（首次启动后执行一次）：

   - PostgreSQL：`powershell -ExecutionPolicy Bypass -File infra/compose/scripts/init-postgres.ps1`
   - ClickHouse：`powershell -ExecutionPolicy Bypass -File infra/compose/scripts/init-clickhouse.ps1`

6. 创建 Kafka topics（首次启动后执行一次）：

   - `powershell -ExecutionPolicy Bypass -File infra/compose/scripts/create-kafka-topics.ps1`

7. 如需对当前中心主链做标准化验收留证：

   - `powershell -NoProfile -ExecutionPolicy Bypass -File scripts/dev/check-field-center-compose-acceptance.ps1 -DeployMode validate -AllowUnsafeSecrets`

## 3) 运维入口

### 3.1 Kafka UI

默认开启在 profile `ops` 下：

- 启动（含 UI）：`docker compose -f infra/compose/docker-compose.yml --env-file infra/compose/.env --profile ops up -d`
- 访问：默认 `http://localhost:8081`（可通过 `.env` 的 `KAFKA_UI_PORT` 修改）

### 3.2 EMQX Dashboard

- `http://localhost:18083`
- 账号密码来自 `.env` 的 `EMQX_DASHBOARD_USER/EMQX_DASHBOARD_PASSWORD`

## 4) 备份与恢复（当前为离线备份）

> 单机优先保证“能恢复”。在未引入更高级的 CH online backup 工具前，先提供离线备份方案。

- `powershell -ExecutionPolicy Bypass -File infra/compose/scripts/backup-offline.ps1`

说明：

- 该脚本会 `docker compose down` 后拷贝数据目录，再 `up -d`，会有短暂停机。
- 备份产物在仓库根目录的 `backups/<timestamp>/`（已在 `.gitignore` 忽略）。

## 5) 相关文档

- 契约与 DDL 来源：
  - PostgreSQL：`docs/integrations/storage/postgres/tables/`
  - ClickHouse：`docs/integrations/storage/clickhouse/`
- 运维 runbook：`docs/guides/runbooks/README.md`
- 阶段 1（设备鉴权/ACL）接线：`docs/guides/deployment/single-host/emqx-http-auth.md`

## 6) 企业化健康检查与证据包（推荐）

当出现“启动失败/端口不可用/服务不健康”等问题时，建议先跑：

- 健康检查：`powershell -ExecutionPolicy Bypass -File infra/compose/scripts/health-check.ps1`
- 证据包（用于 Issue/Incident）：`powershell -ExecutionPolicy Bypass -File infra/compose/scripts/collect-evidence.ps1`

证据包会输出到 `backups/evidence/<timestamp>/`（已忽略，不会被提交）。

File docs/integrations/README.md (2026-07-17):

---
title: README
type: note
permalink: landslide-monitoring-v2-mainline/docs/integrations/readme
---

# integrations/

该目录是所有“对接契约”的唯一来源，避免全局搜索与多份文档不一致。

子目录：

- API：`docs/integrations/api/README.md`
- MQTT：`docs/integrations/mqtt/README.md`
- Firmware（单片机适配）：`docs/integrations/firmware/README.md`
- Kafka：`docs/integrations/kafka/README.md`
- Rules：`docs/integrations/rules/README.md`
- Storage：`docs/integrations/storage/README.md`
- AI（预测/专家系统）：`docs/integrations/ai/README.md`
- IoT adapters（HTTP Push / 第三方平台接入）：`docs/integrations/iot/README.md`

机器可读契约入口（实现阶段逐步启用）：

- OpenAPI：`docs/integrations/api/openapi.yaml`
- Rule DSL Schema：`docs/integrations/rules/rule-dsl.schema.json`
- MQTT/Kafka Schema：见 `docs/integrations/contract-registry.md`
- 契约完整性清单：`docs/integrations/contracts-checklist.md`
- 契约注册表：`docs/integrations/contract-registry.md`
- 契约校验脚本：`docs/tools/validate-contracts.py`

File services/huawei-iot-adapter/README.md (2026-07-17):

---
title: README
type: note
permalink: landslide-monitoring-v2-mainline/services/huawei-iot-adapter/readme
---

# huawei-iot-adapter

用途：兼容“华为云 IoT HTTP 推送/第三方 HTTP 推送”场景，将 HTTP 上报转换为 `telemetry.raw.v1` 写入 Kafka，进入 v2 主链路（Kafka → ClickHouse/Postgres）。

入口与契约：

- `docs/integrations/iot/README.md`
- `docs/integrations/iot/huawei-iot-http-push.md`

运行（示例）：

- `copy services\\huawei-iot-adapter\\.env.example services\\huawei-iot-adapter\\.env`
- `npm -w services/huawei-iot-adapter run build`
- `npm -w services/huawei-iot-adapter run start`

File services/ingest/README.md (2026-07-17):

---
title: README
type: note
permalink: landslide-monitoring-v2-mainline/services/ingest/readme
---

# ingest-service（MQTT → Kafka）

本服务负责把设备端 MQTT 上报的 `TelemetryEnvelope` 校验后写入 Kafka（并把异常消息写入 DLQ），为后续 ClickHouse 落库、规则引擎回放提供统一事件源。

权威契约来源：

- MQTT：`docs/integrations/mqtt/README.md`
- Kafka：`docs/integrations/kafka/README.md`

## 环境变量

参考：`services/ingest/.env.example`

- `MQTT_URL`：例如 `mqtt://127.0.0.1:1883`
- `MQTT_USERNAME`：可选；若 broker 启用鉴权则必须与 `MQTT_PASSWORD` 同时设置（建议使用内部账号，例如 `ingest-service`）
- `MQTT_PASSWORD`：可选；需与 `MQTT_USERNAME` 成对出现
- `MQTT_TOPIC_TELEMETRY`：默认 `telemetry/+`
- `MESSAGE_MAX_BYTES`：单条 MQTT payload 最大字节数（超过则写入 DLQ，默认 `262144`）
- `METRICS_MAX_KEYS`：单条消息允许的 metrics key 数量上限（超过则写入 DLQ，默认 `500`）
- `DLQ_RAW_PAYLOAD_MAX_BYTES`：写入 DLQ 的 `raw_payload` 最大字节数（截断以避免 DLQ 本身过大，默认 `65536`）
- `KAFKA_BROKERS`：逗号分隔，例如 `127.0.0.1:9092`
- `KAFKA_CLIENT_ID`：默认 `ingest-service`
- `KAFKA_TOPIC_TELEMETRY_RAW`：默认 `telemetry.raw.v1`
- `KAFKA_TOPIC_TELEMETRY_DLQ`：默认 `telemetry.dlq.v1`

## 本地运行（开发）

1) 安装依赖（仓库根目录）：

- `npm install`

2) 构建：

- `npm run build`

3) 进入目录运行：

- `cd services/ingest`
- 复制 `.env.example` 为 `.env` 并填好（不要提交 `.env`）
- `node dist/index.js`

## 行为说明（当前实现）

- 收到 MQTT 消息后：
  - JSON 解析失败 → 写入 Kafka `telemetry.dlq.v1`（`reason_code=invalid_json`）
  - Schema 校验失败 → 写入 Kafka `telemetry.dlq.v1`（`reason_code=schema_validation_failed`）
  - payload 过大/metrics 过多 → 写入 Kafka `telemetry.dlq.v1`（`reason_code=payload_too_large|metrics_too_many`）
  - 校验通过 → 写入 Kafka `telemetry.raw.v1`（补充 `received_ts`）

注意：Schema 文件当前直接引用 `docs/integrations/*/schemas`，实现阶段会把 schemas 固化为 `libs/` 的可发布包（见 `docs/guides/standards/code-generation.md`）。

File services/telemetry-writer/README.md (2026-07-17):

---
title: README
type: note
permalink: landslide-monitoring-v2-mainline/services/telemetry-writer/readme
---

# telemetry-writer（Kafka → ClickHouse）

本服务负责消费 Kafka `telemetry.raw.v1`，将“稀疏指标”拆分为多行写入 ClickHouse `landslide.telemetry_raw`，为曲线查询/聚合分析/告警回放提供可靠的时序存储。

权威契约来源：
- Kafka：`docs/integrations/kafka/README.md`
- ClickHouse：`docs/integrations/storage/clickhouse/01-telemetry.sql`

## 环境变量

参考：`services/telemetry-writer/.env.example`

## 本地运行（开发）

1) 安装依赖（仓库根目录）：
- `npm install`

2) 构建：
- `npm run build`

3) 进入目录运行：
- `cd services/telemetry-writer`
- 复制 `.env.example` 为 `.env` 并填写（不要提交 `.env`）
- `node dist/index.js`

## 行为说明（当前实现）

- 消费 Kafka topic：`telemetry.raw.v1`
- 校验消息是否符合：`docs/integrations/kafka/schemas/telemetry-raw.v1.schema.json`
- 将 `metrics` 展开为多行插入 ClickHouse（每个 metric 一行）：
  - 数值：写入 `value_i64`（可安全表示的整数）或 `value_f64`
  - 字符串：写入 `value_str`
  - 布尔：写入 `value_bool`（0/1）
  - `received_ts` 作为主时间轴；`event_ts`（若有）作为设备侧事件时间

注意：
- writer 会将“无法解析 JSON / schema 不匹配 / ClickHouse 写入失败（疑似数据错误）”的消息写入 `telemetry.dlq.v1`，避免坏消息阻塞消费并保留可追溯线索。
- 对带高频 `packet_class` 的消息，writer 会按 `HIGH_FREQUENCY_BUDGET_BYTES` 做语义预算检查；超限时直接写入 `telemetry.dlq.v1`，不再写 ClickHouse，也不再更新 `device_state`。
- 对低频补充包（如 `lf_meta`），writer 在更新 `device_state` 时会按稀疏字段合并已有 `metrics/meta`，不会因为低频包缺少高频字段就把已有高频状态抹掉。
- 对“ClickHouse 不可达/网络超时”等疑似基础设施问题，writer 会重试并在多次失败后中止本批次处理（不提交 offset），等待恢复后重放。
  - 可通过 `CLICKHOUSE_UNAVAILABLE_COOLDOWN_MS` / `CLICKHOUSE_UNAVAILABLE_COOLDOWN_MAX_MS` 控制故障冷却窗口（避免 ClickHouse 长时间故障时产生日志风暴与无意义重试）。
- writer 默认对 Kafka 单条消息大小设置保护（`MESSAGE_MAX_BYTES`），并会截断 DLQ 的 `raw_payload`（`DLQ_RAW_PAYLOAD_MAX_BYTES`），避免极端 payload 造成内存压力与日志/消息膨胀。
- writer 会按 `STATS_LOG_INTERVAL_MS` 周期输出处理统计（写入批次、DLQ 数量等），便于单机 Compose 排查与容量评估。
- schema 当前直接引用 `docs/` 下的 JSON Schema；后续会固化为 `libs/` 的可复用资源包（便于版本化与发布）。

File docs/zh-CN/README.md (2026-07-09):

# 文档总览

[English](../README.md) | 简体中文

这组文档保持小而清晰：说明公开仓库的系统范围、各维护面的职责、本地验证命令、发布流程和贡献方式。

## 推荐阅读顺序

| 文档 | 用途 |
| --- | --- |
| [系统概览](system/OVERVIEW.md) | 端到端产品面和数据流。 |
| [架构说明](ARCHITECTURE.md) | 运行边界、模块职责和打包流程。 |
| [项目范围](PROJECT_SCOPE.md) | 仓库内容、当前维护面和现阶段非目标。 |
| [发布流程](RELEASE.md) | 本地构建、验证、打包和 GitHub Release 检查清单。 |
| [Desktop UI](../../apps/desktop-ui/README.md) | React/Vite UI 包职责和命令。 |
| [Windows Shell](../../apps/windows-shell/README.md) | WPF/WebView2 宿主职责和打包行为。 |
| [RK3568 Edge Gateway](../../edge/rk3568-gateway/README.md) | 边缘服务职责、部署说明和本地配置。 |
| [RK2206 Firmware](../../firmware/rk2206-xl01/README.md) | 现场节点固件包和构建上下文。 |
| [Carrier Board](../../hardware/carrier-board/README.md) | 硬件设计和打板交付资料。 |
| [中文贡献指南](../../CONTRIBUTING.zh-CN.md) | 贡献流程、检查命令和项目约定。 |
| [维护者指南](MAINTAINERS.md) | 评审策略、依赖更新节奏和发布前检查。 |
| [安全策略](../../SECURITY.md) | 漏洞报告和凭据处理策略。 |

## 仓库约定

- 目录名表达产品职责和运行角色。
- 生成产物放在 `artifacts/`，并保留在 Git 之外。
- 本地报告放在 `docs/reports/`，需要时重新生成。
- 面向用户的行为变化应同步更新中英文文档。
- 涉及可见界面的 Pull Request 应附截图或录屏。
- 硬件文件作为工程交付资料维护，打板前仍需复核。

## 当前维护范围

当前公开仓库维护：

- Windows 桌面 UI 和原生壳源码。
- RK3568 边缘网关服务和部署模板。
- RK2206 XL01 现场固件包。
- 载板硬件设计和打板交付资料。
- 桌面端打包和验证脚本。
- 公开文档、Issue 模板和 Pull Request 模板。

以下内容不属于当前公开范围：

- 生产后端服务。
- 移动端应用。
- Web Dashboard 应用代码。
- 生产部署基础设施。
- 点位特定配置和环境文件。
- 凭据、生成产物、本地日志和运行状态。

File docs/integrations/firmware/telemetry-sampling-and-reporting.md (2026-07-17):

---
title: telemetry-sampling-and-reporting
type: note
permalink: landslide-monitoring-v2-mainline/docs/integrations/firmware/telemetry-sampling-and-reporting
---

# 采样与上报策略（固件必须遵守）

目标：按“最坏情况”设计设备行为，但实现不写死，能通过命令动态调整；同时保证后端能长期承载。

## 1. 两个频率必须解耦

- `sampling_s`：采样周期（秒），决定数据精度与功耗
- `report_interval_s`：上报周期（秒），决定链路吞吐与存储增长

原则：

- sampling 可以比 report 更快（例如采样 1s、上报 5s，取窗口统计/最新值）
- report 可以根据网络质量动态拉长

## 2. 上报内容组织（稀疏指标）

设备每次上报为一个 TelemetryEnvelope：

- 必须包含：`schema_version`, `device_id`, `metrics`
- 可选包含：`event_ts`, `seq`, `meta`

约束：

- `metrics` 只包含“本次能读到的字段”，不需要字段一致
- 读不到的指标不要填 0 伪造，建议直接缺失或设为 `null`
- 指标 key 必须为 `snake_case`，例如 `battery_v`, `tilt_x_deg`

## 3. meta 字段使用建议

`meta` 用于低频变化、对排查有帮助的信息，示例：

- 固件版本：`fw`
- 配置：`sampling_s`, `report_interval_s`
- 电量模式：`power_mode`

约束：

- meta 允许冗余，但禁止包含 secret/token
- meta 中的配置仅用于可观测，最终配置以设备本地生效为准

## 4. 设备时间（event_ts）

设备如果无法可靠获得 UTC 时间：

- `event_ts` 可以设置为 `null`
- 后端以 `received_ts` 作为查询/聚合主时间

设备若具备可靠时钟（GPS/NTP/RTC）：

- 必须填 UTC RFC3339（`2025-12-15T10:00:00Z`）
- 设备端要监控“时间跳变”（例如 NTP 校准导致倒退）并记录到 meta（例如 `time_jump_ms`）

## 5. 最坏情况建议值（默认配置）

为了按最坏情况设计但不写死，建议给出“默认起步配置”，实现阶段可在后端配置中调整：

- `sampling_s`: 1~5
- `report_interval_s`: 5~30

说明：

- 单机链路压力主要来自 report_interval，而不是 sampling
- 采样频率提升时，建议上报做窗口聚合（min/max/avg/last）

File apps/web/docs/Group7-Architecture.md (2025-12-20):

# Group 7 系统架构图（Mermaid）

> 可在支持 Mermaid 的工具中导出为 PNG/PDF；或使用浏览器扩展/VSCode 插件截图。

```mermaid
flowchart TB
  %% Client Layer
  subgraph C[Client 前端]
    B[Web 浏览器]
    UI[Next.js 前端 UI\nApp Router 页面/组件\n地图/图表组件]
  end

  %% Server Layer
  subgraph S[Server 服务器侧]
    API[Next.js API Routes (/api/*)]
    SVC[业务服务模块\n设备管理 / GPS监测 / 基线 / 分析 / 系统监控]
  end

  %% Data Layer
  subgraph D[Data 数据层]
    DB[(PostgreSQL / Supabase)]
    RT[(Realtime / WebSocket)]
  end

  %% IoT Layer
  subgraph I[IoT 物联侧]
    DEV[传感器 / 边端设备]
    IOT[IoT 服务与设备影子\n数据接入/清洗/映射]
  end

  %% Edges
  B --> UI
  UI <--> API
  API --> SVC
  SVC <--> DB
  SVC <--> RT

  DEV --> IOT --> DB
  RT -- 推送更新 --> UI

  %% Notes
  classDef note fill:#f7f7f7,stroke:#aaa,color:#333,font-size:12px;
  N1["前端：统一的视觉语言与交互流程；\n模块：设备管理、GPS监测、基线、分析、系统监控"]:::note
  N2["服务：API 路由协调业务模块，\n读写数据库并通过 Realtime 向前端推送"]:::note
  N3["IoT：设备数据经接入与映射入库；\n前端可订阅实时通道获取最新状态"]:::note

  UI --- N1
  SVC --- N2
  IOT --- N3
```

## 关键说明
- 前端以 Next.js App Router 组织页面；地图/图表组件承载数据可视与交互。
- API Routes 协同业务服务模块，统一对外的读写/计算入口。
- 数据层使用 PostgreSQL（Supabase）存储结构化数据；Realtime 为前端提供订阅/推送。
- 物联设备数据通过 IoT 服务接入，完成清洗、映射与入库；异常/状态变化通过 Realtime 通知前端。

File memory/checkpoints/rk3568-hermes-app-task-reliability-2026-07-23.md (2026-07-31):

---
title: rk3568-hermes-app-task-reliability-2026-07-23
type: note
tags:
- checkpoint
- rk3568
- hermes
- harmonyos
status: active
permalink: landslide-monitoring-v2-mainline/memory/checkpoints/rk3568-hermes-app-task-reliability-2026-07-23
---

# Checkpoint: RK3568 Hermes App Task Reliability

## Objective

Keep the App -> cloud API -> RK3568 Hermes path reliable for retries,
concurrent use, persistent conversations, and bounded automatic tasks without
changing or blocking monitoring, map, SSE, Push, cache, MQTT, serial,
telemetry, rule-engine, or physical alarm authority.

## Last Confirmed State

- PR [#349](https://github.com/kipp7/landslide-monitoring-v2/pull/349) is merged
  as `3332a19f58c42c55c6e490e7f40b7150a38475e8`; PR #351 advanced public
  `main` to `e3b36473b959f550f2007efddb0d52705433db13` with rollout memory only.
- PR [#354](https://github.com/kipp7/landslide-monitoring-v2/pull/354)
  merged the rollout follow-up fixes and current production checkpoint into
  public `main` as `36cb444679f6f4a2e9b4b257fba7bf36c21a0778`.
- PR #355 advanced public `main` to
  `1e04268b3a39a2658409c637738cc57f58aa7b54`. PR #356 remains open with
  the HarmonyOS chat-first UI and its second-round simulator refinements.
- PostgreSQL 16 has `hermes_conversations`, `hermes_messages`, and
  `hermes_tasks` plus four indexes. PostgreSQL and ClickHouse remain the only
  server business sources; no App-specific database was introduced.
- The production API image is
  `sha256:ca3522dff1151651e07cbefba0184a749fe697194bd16262a28ecd74b883efbd`,
  labelled revision `60ee7b76136477c0bf4ca0a3ad2554e5829afa64`, with restart count `0`.
  All non-API containers retained their existing uptime during the API switch.
- Cloud rollback data is under
  `/opt/lsmv2-production/backups/hermes-pr349-20260731-150457`; the original
  PostgreSQL dump SHA256 is
  `72c78d6b5d56aeee42be216d6e67c0d7a1331e02110ec174d63f92ae7a568259`.
  API rollback tags are `pre-hermes-pr349-20260731-150457` and
  `pre-hermes-followup-20260731`.
- RK3568 runs immutable release
  `/opt/lsmv2/releases/hermes-edge-supervisor-3332a19f`; its deployment archive
  SHA256 is
  `df1a19843edb6060c756471bafc90cc2e95d207702e9b21d7282f6b1c5d58410`.
- RK3568 rollback data is under
  `/opt/lsmv2/backups/hermes-pr349-20260731-150457`, with the previous release
  retained at `/opt/lsmv2/releases/hermes-edge-supervisor-adba15c3`.
- RK3568 passed `10/10` queue/risk tests, `/healthz`, supervision, capacity
  `16`, all three actions, duplicate request reuse, conflict HTTP `409`,
  `0640` artifacts, and a credential-pattern redaction scan.
- Production multi-step chat executed
  `collect_logs -> recheck -> generate_report`, repeated the audited plan with
  `按刚才的再来一次`, restored `4` messages and `6` tasks, and polled every
  task as `succeeded`. Protected restart/network/physical-alarm intent created
  no task.
- A rollout phrase that initially matched only `generate_report` is now covered:
  `先检查当前链路，再收集诊断日志，然后生成报告` maps to
  `collect_logs -> generate_report`; repeat/history verification passed. All
  rollout-only conversations were deleted afterwards.
- The field gateway, field-link monitor, physical alarm actuator, and reverse
  tunnel kept PIDs `158686`, `1954`, `1370`, and `138145`; their restart counts
  did not change. Hermes runs as PID `178203`, restart count `0`, with
  `CPUQuota=50%`, `MemoryMax=384M`, and `TasksMax=64`.
- The guardian deadlock cause was a synchronous service restart combined with
  reverse ordering. Production uses non-blocking `try-restart` and a 75-second
  timeout; the corresponding source fix is commit `60ee7b7`.
- RK3568 time was corrected from 2026-07-26 to Beijing time on 2026-07-31.
  Aliyun, Tencent, Ubuntu, and pool NTP all timed out over UDP/123, so
  `System clock synchronized` remains `no`; verify time retention after a power
  cycle instead of claiming network NTP is fixed.
- A/B/C currently have no serial replies. The serial port is open and MQTT is
  connected, but all nodes must remain `configured`, not falsely online.
- App acceptance now targets the DevEco Studio phone emulator rather than a
  physical phone. HarmonyOS `5.0.1(13)` is connected through HDC at
  `127.0.0.1:5555`.
- The latest signed PR #356 HAP built at
  `E:/codex-build/hermes-chat-ui-20260731/entry/build/default/outputs/default/entry-default-signed.hap`
  has SHA256
  `8F2D815CAABEE5BEBD4FD4DAD7FE59FC11DAB2E40F2674678810718200EA726D`.
  It installed and launched successfully on the emulator.
- The second UI pass replaces the three-button header with history, centered
  connection state, and new conversation; hides quick tasks behind the composer
  tool button; removes the unrelated global task result from chat; keeps user
  bubbles content-sized; and removes repeated assistant labels and timestamps.
- The chat screen, content-sized short-message bubbles, hidden and expanded task
  tools, fixed composer, and software-keyboard layout passed HarmonyOS 5.0.1(13)
  simulator inspection. The clean system snapshot is
  `E:/codex-build/hermes-chat-ui-20260731/hermes-chat-final-v2.jpeg` with SHA256
  `C8A3E493B02C184486995A8DF53768B67E33184DAF4628D6C957EC323E5716DD`.
- The first rebuild attempt exposed a stale-HAP hazard: the source copy command
  had timed out before copying, while Hvigor reported old packaging tasks as
  `UP-TO-DATE`. Future out-of-tree builds must verify source and build-copy
  SHA256 values, then run `hvigorw clean` before `assembleHap`.
- The previous signed HAP remains the rollback copy at
  `_private-production-backup/hermes-pr349-20260731-150457/entry-default-pr349-signed.hap`.
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

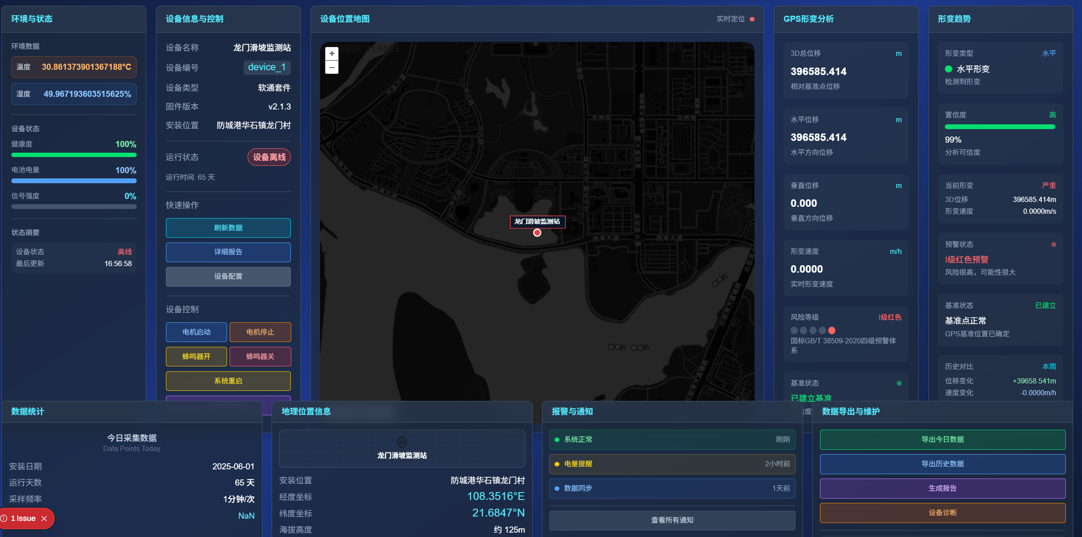
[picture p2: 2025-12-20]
相互遮挡.png

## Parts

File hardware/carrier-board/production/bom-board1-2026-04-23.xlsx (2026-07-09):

No. | Quantity | Comment | Designator | Footprint | Value | Manufacturer Part | Manufacturer | Supplier Part | Supplier
1 | 5 | 100nF | C1,C3,C5,C7,C8 | C0805 | 100nF | CL21B104KBCNNNC | SAMSUNG(三星) | C1711 | LCSC
2 | 3 | 10uF | C2,C4,C6 | C0805 | 10uF | CL21A106KAYNNNE | SAMSUNG(三星) | C15850 | LCSC
3 | 3 | 2.54-1*4P母 | J_GPS,J_MPU6050,J_SHT30 | HDR-TH_4P-P2.54-V-F |  | 2.54-1*4P母 | BOOMELE(博穆精密) | C2718488 | LCSC
4 | 1 | HX-XH2.54-3PZZ | J_PWR | HDR-TH_3P-P2.54-V-M |  | HX-XH2.54-3PZZ | hanxia(韩下) | C42391661 | LCSC
5 | 1 | PZ254V-11-04P | J_XL01 | HDR-TH_4P-P2.54-V-M |  | PZ254V-11-04P | XFCN(兴飞) | C492403 | LCSC
6 | 1 | KH-2.54FH-1X12P-H8.5 | P_RK2206_EXT10_LFTE | HDR-TH_12P-P2.54-V-F |  | KH-2.54FH-1X12P-H8.5 | kinghelm(金航标) | C2905419 | LCSC
7 | 2 | 4.7kΩ | R1,R2 | R0805 | 4.7kΩ | 0805W8F4701T5E | UNI-ROYAL(厚声) | C17673 | LCSC

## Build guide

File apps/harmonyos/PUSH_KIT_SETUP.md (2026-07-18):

# HarmonyOS Push Kit 接入

App 已具备前台告警 SSE 和本地通知。Push Kit 用于 App 退到后台或进程未运行时的告警送达，不替代服务器告警数据，也不新增独立业务数据库。

## 当前交付状态

- App 前台告警已接入 `GET /api/v1/alerts/stream`，新告警会刷新列表并生成系统通知。
- Push Token 注册接口已收口到现有 API：`POST/DELETE /api/v1/push/devices`。
- Push Token 只存入现有 PostgreSQL 的 `app_push_devices` 表，不建 App 专用业务库。
- `alert-notify-worker` 已增加华为 Push Kit 发送器，未配置 AGC 凭据时保持关闭，不影响现有告警链路。
- 生产服务器尚未执行本次迁移和重建；下方步骤是主线部署时的唯一交接清单。

## 启用条件

1. 在 AppGallery Connect 创建 HarmonyOS 应用，包名使用 `com.kipp7.landslide.monitoring`。
2. 在 AGC 开通 Push Kit，并让 AGC 应用证书与 DevEco Studio 正式签名保持一致。
3. 将 AGC 配置文件放到官方文档要求的工程位置。配置文件可能包含应用标识，但不得提交客户端密钥。
4. 对已有 PostgreSQL 执行 `docs/integrations/storage/postgres/tables/22-app-push-devices.sql`。新建数据库会由 Compose 初始化目录自动执行。
5. 在服务器 `.env` 中填写：
   - `HUAWEI_PUSH_ENABLED=true`
   - `HUAWEI_PUSH_SEND_URL`：AGC 当前 Push Kit 服务端 API 的完整发送地址
   - `HUAWEI_PUSH_CLIENT_ID`
   - `HUAWEI_PUSH_CLIENT_SECRET`
6. 重新构建并启动 `api` 与 `alert-notify-worker`。

部署后应先用已登录账号验证 `/api/v1/alerts/stream` 可持续连接，再用真机验证 Push Token 注册和后台通知。不要在 AGC 凭据未准备好时开启 `HUAWEI_PUSH_ENABLED`。

## 数据流

登录后，App 调用 Push Kit 获取 Token，并通过 `POST /api/v1/push/devices` 绑定到当前用户。退出账号或更换服务器时，App 调用 `DELETE /api/v1/push/devices` 停用绑定。

规则引擎产生 `alerts.events.v1` 后，`alert-notify-worker` 按现有订阅和最低告警等级筛选用户，再通过 Push Kit 发送。Token 只存放在现有 PostgreSQL 的 `app_push_devices` 表中，不进入 App 普通缓存。

## 验证

- 前台：触发新告警后，SSE 在约 2 秒内刷新告警列表并发布本地通知。
- 后台：真机退到后台后触发告警，Push Kit 应显示系统通知；点击通知进入对应告警地图。
- 退出：退出账号后，该 Token 的服务器绑定应变为停用。

模拟器可能不支持 Push Kit Token。前台 SSE、地图和数据监测不受影响；后台推送验收应使用已安装华为移动服务的 HarmonyOS 真机。

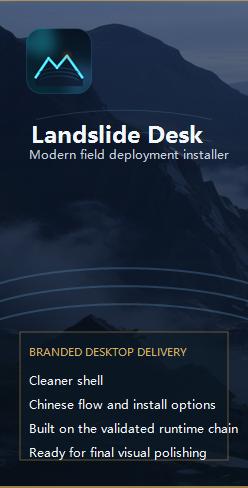
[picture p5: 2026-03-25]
apps/windows-shell/installer-modern/assets/BrandSidebar.png

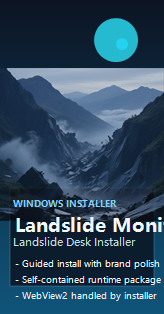
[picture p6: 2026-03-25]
apps/windows-shell/installer/assets/WizardImage.bmp

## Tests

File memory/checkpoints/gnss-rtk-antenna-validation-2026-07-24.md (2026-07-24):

---
title: gnss-rtk-antenna-validation-2026-07-24
type: note
tags:
  - checkpoint
  - gnss
  - rtk
status: active
---

# Checkpoint: gnss-rtk-antenna-validation-2026-07-24

## Objective

在现有 3 x UM220-IV NK 架构上实现稳定 RTK Fixed，并确定是否需要更换接收机。

## Last Confirmed State

- PC 上通过 COM11/115200 成功连接 UM220-IV NK，固件版本为 `R3.6.0.0`。
- 千寻知寸 FindCM NTRIP 已成功返回 `ICY 200 OK`，RTCM 1005/1033/1074/1084/1094/1114/1124 已注入 NK，差分龄约 2 s 且没有断线。
- 原 CT-GPS 天线 10 分钟仅得到 82 次 Float、0 次 Fixed；第二个普通天线 10 分钟得到 511 次 Float、0 次 Fixed，首次 Float 由约 259 s 改善到约 3.4 s。
- 当前只能按 RTK Float 估计精度，水平约 0.3 至 1.5 m、垂直约 0.5 至 2 m，不能按厘米级验收。
- 已确认 GGA=4 才是 RTK Fixed，GGA=5 是 RTK Float。
- 已确认 BT-760 正式规格与接口方向符合当前验证需求；决定先买 1 个而不是直接买 3 个。
- 已确认馈线组合为 TNC-J 到 SMA-J，3 m、50 ohm、非 RP-SMA；天线端 BT-760 为 TNC-K。

## In Progress

- 等待采购并收到 1 个 BT-760 和配套 3 m 馈线。
- RK3568 单 NTRIP 客户端向 3 个 RK2206 广播 RTCM 的固件工作尚未开始。

## Next Actions

- 到货后核对接口、公母头、50 ohm、线缆类型及有源天线馈电。
- 在开阔固定位置运行 30 至 60 分钟 PC 对比测试，保存 GGA 状态计数、首次 Fixed、Fixed 占比、差分龄、卫星数和 HDOP。
- 达标后购买另外 2 套同批次天线/馈线并进入 RK3568/RK2206 RTCM 广播实现。
- 不达标时先完成天线供电、馈线、天空视野、多路径、差分和固件排查，再决定是否升级 UM960/UM982。

## Risks

- BT-760 官方标称相位中心误差 +/- 2 mm，但没有频点/方位完整校准数据，不能仅凭规格表保证现场厘米级。
- 山体环境的树木、坡体、箱体和金属安装件可能造成遮挡或多路径，使更好的天线仍难以保持 Fixed。
- 共享 115200 链路若缺少 RTCM 帧优先级和队列上限，可能增加差分龄或影响现有遥测。
- NTRIP 凭据和真实坐标必须保持在本地未跟踪文件中。

## Resume Prompt

继续 GNSS RTK 验证：先读取 `memory/decisions/gnss-rtk-correction-and-antenna-strategy.md`、`memory/references/gnss-rtk-pc-test-baseline.md` 和 `memory/tasks/gnss-rtk-fixed-validation-and-deployment.md`，确认 BT-760 是否到货；若已到货，在开阔位置用现有 PC 脚本执行 30 至 60 分钟测试并按 GGA=4 Fixed 指标验收。

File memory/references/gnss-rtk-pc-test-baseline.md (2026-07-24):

---
title: gnss-rtk-pc-test-baseline
type: note
tags:
  - reference
  - gnss
  - rtk
  - ntrip
  - test
status: active
---

# Reference: gnss-rtk-pc-test-baseline

## Purpose

保存 2026-07-24 已验证的 UM220-IV NK、千寻知寸 FindCM 和 PC 串口注入测试基线，供 BT-760 到货测试及后续 RK3568/RK2206 部署复用。

## Commands

PC 测试工具位于项目工作区根目录，当前未纳入远端仓库。凭据文件保持本地且不得提交、复制到日志或写入 memory。

```powershell
python -u .\ntrip_rtk_test.py `
  --credentials '<local-credentials-file>' `
  --serial-port COM11 `
  --baud 115200 `
  --ntrip-port 8003 `
  --duration 1800
```

## Files

- `ntrip_rtk_test.py`: 读取本地凭据、向 NTRIP 发送 GGA、将原始 RTCM 全双工注入 NK，并统计 RTCM 类型和 GGA 状态；不输出账号、密码或坐标。
- 本地差分凭据文件：仅存放在项目工作区，路径和内容不进入远端仓库。

## Notes

### Hardware and serial baseline

- Rover: 3 x UM220-IV NK，固件 `R3.6.0.0`。
- PC 测试串口：`COM11`，`115200 8N1`，CH340 转接器。
- NK 可接收 RTCM 3.2/3.3；按 rover-only 规划。
- GGA 质量：`1` 单点，`2` DGPS，`5` RTK Float，`4` RTK Fixed。厘米级验收必须以稳定 `GGA=4` 为准，不能把 `5` 视为比 `4` 更高精度。

### Correction service baseline

- 服务：千寻知寸 FindCM。
- 挂载点：`AUTO`。
- 端口 `8003`：CGCS2000，历元 2000.0；系统内必须始终使用一致坐标框架。
- 已收到 `ICY 200 OK`。
- 已验证 RTCM 类型：`1005`、`1033`、`1074`、`1084`、`1094`、`1114`、`1124`。
- 差分龄约 2 s，测试期间无 NTRIP 断线。
- NTRIP 主机、账号、密码和真实坐标故意不记录在 memory。

### Antenna comparison

- 原 CT-GPS 1575.42 MHz 天线，10 分钟：GGA=2 为 518 次，GGA=5 为 82 次，GGA=4 为 0 次；首次 Float 约 259 s。
- 第二个稍好的类似天线，10 分钟：GGA=1 为 3 次，GGA=2 为 86 次，GGA=5 为 511 次（约 85.2%），GGA=4 为 0 次；首次 Float 约 3.4 s。
- 第二个天线显著改善收敛和 Float 稳定性，但尚未证明厘米级能力。
- 当前保守精度估计：水平约 0.3 至 1.5 m，垂直约 0.5 至 2 m。

### BT-760 purchase baseline

- 先购买 1 个 BT-760，卖家报价约人民币 130 元。
- 天线端为 `TNC-K`；若 NK 开发板为常见 `SMA-K`，馈线需要 `TNC-J` 到 `SMA-J`。
- 馈线要求：3 m、50 ohm、非 RP-SMA、支持直流馈电；优先低损耗铜芯线，并固定线缆避免拉扯开发板 SMA 座。
- 户外 TNC 接头使用自融防水胶带处理。

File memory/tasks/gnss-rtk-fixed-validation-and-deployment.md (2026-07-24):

---
title: gnss-rtk-fixed-validation-and-deployment
type: note
tags:
  - task
  - gnss
  - rtk
  - rk3568
  - rk2206
status: active
---

# Task: gnss-rtk-fixed-validation-and-deployment

## Goal

用最低成本验证现有 3 个 UM220-IV NK 能否在千寻知寸差分服务下稳定获得 RTK Fixed，并在验证通过后将单 NTRIP 客户端、三节点 RTCM 广播方案部署到 RK3568/RK2206 架构。

## Current State

- 千寻知寸 FindCM 试用已激活，PC NTRIP 接入和原始 RTCM 串口注入已验证成功。
- NK 已进入过 GGA=5 RTK Float，证明差分输入路径和 rover 解算路径有效，但两轮各 10 分钟测试均未出现 GGA=4。
- 第二个普通天线把首次 Float 缩短至约 3.4 s，并使 Float 占比达到约 85.2%。
- 已选择北天 BT-760 作为性价比验证天线；待先采购 1 个和 1 条 3 m、50 ohm、TNC-J 到 SMA-J 馈线。
- RK3568 到 3 个 RK2206 的 RTCM 广播尚未实施，等待 PC 端 BT-760 Fixed 验证。

## Constraints

- 现有链路为 RK3568 -> DL-XLS1/XL01 共享 115200 串口 -> 3 个 RK2206 -> 3 个 UM220-IV NK。
- RTCM 必须保持原始二进制，不能 JSON/Base64 包装。
- 不能在 memory、日志或 Git 中保存 NTRIP 主机、账号、密码和真实坐标。
- UM220-IV NK 按 rover 使用，不依赖其输出基站 RTCM。
- 三节点批量采购和固件改造必须等待单节点 RTK Fixed 验收结果。
- 正式遥测必须使用 `double` 和至少 8 位小数，并携带 GGA 质量、卫星数、HDOP 和差分龄。

## Plan

- 采购并核对 1 个 BT-760 与 3 m、50 ohm、TNC-J 到 SMA-J、非 RP-SMA 馈线。
- 在开阔天空、固定位置用 COM11/115200 和现有 PC 脚本运行 30 至 60 分钟测试。
- 记录首次 Fixed 时间、GGA=1/2/4/5 计数和占比、卫星数、HDOP、差分龄、RTCM 类型与断线情况。
- 若通过，采购另外 2 套同批次天线和馈线。
- 在现有 COBS + CRC 协议中定义二进制 RTCM 帧，由 RK3568 单客户端广播，RK2206 原样转发到 NK RX。
- 更新遥测结构和存储精度，随后做 3 节点同时在线、差分龄、固定率、带宽和恢复测试。
- 若不通过，依次排查开阔度/多路径、天线供电、馈线损耗、差分数据、串口完整性和固件，再评估 UM960/UM982。

## Open Questions

- BT-760 在相同测试位置能否在约 5 分钟内进入 GGA=4，并保持超过 80% Fixed？
- UM220-IV NK 在实际山体监测环境中的 Fixed 保持率和重新收敛时间是多少？
- 共享 115200 链路承载三节点遥测和 RTCM 时的帧调度、优先级与最大队列长度如何定义？
- 如果需要更换接收机，UM960 与 UM982 在单天线 rover、功耗、接口和成本上的最终选型是什么？

## Done When

- 单个 BT-760 在 30 至 60 分钟开阔环境测试中约 5 分钟内首次 Fixed，Fixed 占比高于 80%（优选高于 90%），差分龄稳定在 1 至 3 s。
- 3 个节点均使用经过验证的天线/馈线并能稳定输出 GGA=4。
- RK3568 单 NTRIP 客户端到 3 个 RK2206 的 RTCM 二进制广播完成，断线和重连可恢复。
- 遥测与存储保留足够坐标精度及完整质量字段，系统测试记录可追溯。

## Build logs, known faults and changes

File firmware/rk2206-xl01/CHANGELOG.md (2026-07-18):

# 更新日志

## [2026-07-19] - 现场链路自动恢复

- 同步已在 RK2206 厂商构建树验证的生产固件：COBS/CRC 帧、RK3568 轮询、SC16IS752 双路 RS485、土壤温湿度/可选电导率和倾角采集。
- 新增独立 `FieldLinkHealth` 任务。生产轮询模式连续 180 秒未成功处理网关命令时，通过硬件看门狗复位 RK2206，重建 MCU 侧 UART 和协议状态。
- 新固件标记为 `fw-field-link-auto-recovery-20260719`；A/B/C 使用相同恢复逻辑，只修改三项设备身份宏。
- 当前 PCB 未将 DL-XLS1 的复位或电源控制线接入 RK2206，因此该恢复不是无线模块硬断电。

## [v2.0] - 2025-10-22 - 模块化架构

### 架构重构

将代码重构为模块化分层架构，便于维护、测试和扩展。

#### 分层设计原则

采用经典的**分层架构**模式，将系统划分为5个独立层次：

```
┌─────────────────────────────────────┐
│  配置层 (config/)                   │ ← 集中管理所有参数
├─────────────────────────────────────┤
│  工具层 (utils/)                    │ ← 可复用通用模块
├─────────────────────────────────────┤
│  驱动层 (drivers/)                  │ ← 硬件抽象接口
├─────────────────────────────────────┤
│  应用层 (app/)                      │ ← 数据结构定义
├─────────────────────────────────────┤
│  主程序 (main/)                     │ ← 业务逻辑编排
└─────────────────────────────────────┘
```

#### 模块清单

**1. 配置模块**
- `config/app_config.h` - 全局参数集中管理

**2. 工具模块**
- `utils/fifo.h/.c` - FIFO缓冲区管理
- `utils/watchdog_mgr.h/.c` - 看门狗封装

**3. 驱动模块**
- `drivers/xl01/xl01_driver.h/.c` - XL01无线通信驱动
- `drivers/sensors/sht30_driver.h/.c` - SHT30温湿度传感器
- `drivers/sensors/mpu6050_driver.h/.c` - MPU6050加速度/陀螺仪
- `drivers/sensors/gps_driver.h/.c` - GPS定位模块

**4. 应用模块**
- `app/sensor_data.h` - 传感器数据结构定义

**5. 主程序**
- `main/landslide_main.c` - 主业务逻辑

#### 设计优势

| 原则 | 实现 | 优势 |
|-----|-----|---|
| **单一职责** | 每个模块功能明确 | 易于理解和维护 |
| **开放封闭** | 对扩展开放，对修改封闭 | 新增传感器无需改动现有代码 |
| **依赖倒置** | 面向接口编程 | 驱动可独立替换 |
| **接口隔离** | 最小化接口依赖 | 模块间低耦合 |
| **里氏替换** | 驱动接口统一 | 传感器可互换 |

### 📁 文件变更

#### 新增文件 (15个)
```
✅ config/app_config.h
✅ utils/fifo.h
✅ utils/fifo.c
✅ utils/watchdog_mgr.h
✅ utils/watchdog_mgr.c
✅ drivers/xl01/xl01_driver.h
✅ drivers/xl01/xl01_driver.c
✅ drivers/sensors/sht30_driver.h
✅ drivers/sensors/sht30_driver.c
✅ drivers/sensors/mpu6050_driver.h
✅ drivers/sensors/mpu6050_driver.c
✅ drivers/sensors/gps_driver.h
✅ drivers/sensors/gps_driver.c
✅ app/sensor_data.h
✅ main/landslide_main.c
```

#### 删除文件 (1个)
```
❌ xl01_framework.c  (876行单体文件 → 15个模块化文件)
```

#### 修改文件 (3个)
```
📝 BUILD.gn         - 更新编译源文件列表
📝 README_zh.md     - 反映新架构
📝 CHANGELOG.md     - 本文件
```

### 🔄 迁移对比

| 方面 | v1.1 (单体) | v2.0 (模块化) |
|-----|---|---|
| **文件数** | 1个876行 | 15个文件 |
| **配置管理** | 分散在代码中 | 集中在 `config/` |
| **传感器驱动** | 混在主文件 | 独立 `drivers/sensors/` |
| **通信驱动** | 混在主文件 | 独立 `drivers/xl01/` |
| **工具函数** | 嵌入主文件 | 独立 `utils/` |
| **数据结构** | 主文件顶部 | 独立 `app/` |
| **可测试性** | 难以测试 | 模块独立可测 |
| **新增传感器** | 修改主文件 | 添加新驱动文件 |
| **维护难度** | 高（影响面大） | 低（影响面小） |

### 🎯 功能保留

所有 v1.1 的功能在 v2.0 中**完全保留**，包括：

- ✅ 模块化传感器支持（GPS/SHT30/MPU6050/Virtual）
- ✅ ACK确认机制（应用层）
- ✅ 防丢包机制（FIFO + 三任务架构）
- ✅ 看门狗保护
- ✅ 低功耗支持
- ✅ 统计监控
- ✅ JSON数据格式

### 📚 升级指南

#### 从 v1.1 升级到 v2.0

**代码无需修改**，只需重新编译：

```bash
cd /root/workspace/txsmartropenharmony
hb build -f
```

**配置修改**（如需要）：

旧方式（v1.1）：
```c
// 在 xl01_framework.c 顶部修改
#define NODE_ID "A"
```

新方式（v2.0）：
```c
// 在 config/app_config.h 中修改
#define NODE_ID "A"
```

### 🔬 技术亮点

#### 1. 驱动抽象层
每个传感器驱动提供统一接口：
```c
int XXX_Init(void);      // 初始化
int XXX_Read(...);       // 读取数据
```

#### 2. 配置集中化
所有可调参数集中在 `config/app_config.h`：
- 节点配置（NODE_ID）
- 传感器开关（ENABLE_XXX）
- 上传参数（UPLOAD_INTERVAL_MS）
- 硬件配置（UART_ID, I2C_ADDR）

#### 3. 工具模块化
通用功能独立封装：
- `fifo.c` - FIFO缓冲区（可复用）
- `watchdog_mgr.c` - 看门狗管理（可复用）

#### 4. 头文件管理
严格的包含路径：
```c
#include "../../config/app_config.h"    // 相对路径
#include "../drivers/xl01/xl01_driver.h"
```

### 💡 最佳实践示例

#### 添加新传感器（完整流程）

**1. 创建驱动**
```bash
drivers/sensors/
├── bh1750_driver.h     # 光照传感器头文件
└── bh1750_driver.c     # 光照传感器实现
```

**2. 实现接口**
```c
// bh1750_driver.c
#include "bh1750_driver.h"
#include "../../config/app_config.h"

int BH1750_Init(void) {
    // I2C初始化
    return 0;
}

int BH1750_Read(float *lux) {
    // 读取光照值
    return 0;
}
```

**3. 更新配置**
```c
// config/app_config.h
#define ENABLE_BH1750  1
#define BH1750_I2C_ADDR  0x23
```

**4. 更新数据结构**
```c
// app/sensor_data.h
typedef struct {
    // ...
    float lux;
    int lux_valid;
} SensorData;
```

**5. 集成主程序**
```c
// main/landslide_main.c
#if ENABLE_BH1750
#include "../drivers/sensors/bh1750_driver.h"
#endif

// SystemInit() 中：
#if ENABLE_BH1750
BH1750_Init();
#endif

// SensorCollectionTask() 中：
#if ENABLE_BH1750
if (BH1750_Read(&g_sensor_data.lux) == 0) {
    g_sensor_data.lux_valid = 1;
}
#endif
```

**6. 更新构建**
```gn
// BUILD.gn
sources = [
    // ...
    "drivers/sensors/bh1750_driver.c",
]
```

完成！新传感器已集成，**无需修改其他模块**。

---

## [v1.1] - 2025-10-22

### ✨ 新增
- **真正的ACK确认机制**: 应用层ACK，中心节点必须回复"ACK\n"才算成功
- **准确的统计信息**: 成功率、重试次数、失败次数真实反映通信质量
- **ACK配置选项**: 可启用/禁用ACK检查，支持两种模式

### 🔧 改进
- ACK超时等待机制（1秒超时）
- 自动重试机制（最多3次）
- 优化输出格式（✓ ACK / ✗ FAILED）
- 接收到ACK/OK自动识别

---

## [v1.0] - 2025-10-22

### 新增功能
- **模块化框架**: 模块化传感器支持
- **防丢包机制**: 1024字节FIFO + 三任务架构
- **看门狗保护**: 10秒超时自动重启
- **低功耗支持**: 可配置上传间隔、预留休眠接口
- **统计监控**: 实时监控发送/接收/错误

### 🎯 核心特性
1. **模块化传感器**
   - GPS (ENABLE_GPS)
   - SHT30温湿度 (ENABLE_SHT30)
   - MPU6050加速度/陀螺仪 (ENABLE_MPU6050)
   - 虚拟数据测试 (ENABLE_VIRTUAL)

2. **三任务架构**
   - UartRxTask (高优先级, 1ms轮询)
   - DataProcessTask (普通优先级, 10ms)
   - SensorUploadTask (低优先级)

3. **FIFO缓冲**
   - 1024字节环形缓冲区
   - 防止高速接收时数据丢失

---

## [v0.x] - 2025-10-21 及之前

### 已删除的旧版本文件
以下文件已在 v1.1 清理时删除：
- `xl01_test_virtual.c`
- `xl01_simple_test.c`
- `xl01_test_transparent.c`
- `xl01_sensor_upload.c`
- `xl01_full_sensors.c`
- `cc9d.c / cc9d.h`
- `crc8.c / crc8.h`

---

## 版本对比

| 特性 | v0.x | v1.0 | v1.1 | v2.0 |
|---|---|---|---|---|
| 架构 | 单文件 | 单文件 | 单文件 | **模块化** ✨ |
| 文件数 | 1-3 | 1 | 1 | **15** ✨ |
| 分层设计 | ✗ | ✗ | ✗ | **✓** ✨ |
| 驱动独立 | ✗ | ✗ | ✗ | **✓** ✨ |
| 配置集中 | ✗ | ✗ | ✗ | **✓** ✨ |
| 可测试性 | 低 | 低 | 低 | **高** ✨ |
| 可维护性 | 低 | 中 | 中 | **高** ✨ |
| 可扩展性 | 低 | 中 | 中 | **高** ✨ |
| 模块化传感器 | ✗ | ✓ | ✓ | ✓ |
| FIFO缓冲 | 部分 | ✓ | ✓ | ✓ |
| 三任务架构 | ✗ | ✓ | ✓ | ✓ |
| 看门狗 | ✗ | ✓ | ✓ | ✓ |
| ACK确认 | ✗ | 假 | **真** | ✓ |
| 统计监控 | 基础 | ✓ | ✓ | ✓ |

---

## 路线图

### 已完成 ✅
- [x] XL01通信基础 (v0.1)
- [x] 虚拟数据测试 (v0.2)
- [x] 三任务架构 (v0.5)
- [x] FIFO防丢包 (v1.0)
- [x] 看门狗保护 (v1.0)
- [x] ACK确认机制 (v1.1)
- [x] **模块化架构重构 (v2.0)** ✨

### 进行中 ⏳
- [ ] SHT30温湿度驱动完善（已有框架）
- [ ] MPU6050 IMU驱动完善（已有框架）
- [ ] GPS NMEA解析完善（已有框架）

### 计划中 📋
- [ ] 单元测试框架
- [ ] 驱动层Mock测试
- [ ] 低功耗深度休眠
- [ ] 数据压缩传输
- [ ] 本地存储（掉电缓存）
- [ ] OTA升级支持
- [ ] 多节点组网测试
- [ ] 长期稳定性测试

---

## 架构演进

```
v0.x: 原型验证
└─> 单文件，快速验证功能

v1.0: 功能完整
└─> 单文件，基础功能完整

v1.1: ACK增强
└─> 单文件，真实ACK确认

v2.0: 架构升级
└─> 模块化分层架构
    ├── 配置层：集中管理
    ├── 工具层：可复用模块
    ├── 驱动层：硬件抽象
    ├── 应用层：数据定义
    └── 主程序：业务编排
```

---

## 贡献者

- 项目维护者 - 架构设计、实现和测试验证

---

## 许可

Apache License 2.0

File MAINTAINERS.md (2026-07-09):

# Maintainers Guide

This project keeps the public repository focused on maintained, buildable system surfaces: the Windows desktop client, RK3568 edge services, RK2206 field firmware package, carrier-board hardware handoff assets, packaging scripts, and public documentation.

## Review Principles

- Keep changes scoped to a documented product area and add a public README plus validation path when reintroducing older modules.
- Prefer small pull requests with clear screenshots for UI work and clear review notes for firmware, edge, or hardware changes.
- Do not merge generated artifacts such as `dist/`, `bin/`, `obj/`, `artifacts/`, local reports, runtime state, or package output directories.
- Do not publish credentials, production endpoints, site-specific configuration, or local environment values.
- Require the CI workflow to pass before merging.

## Dependency Updates

Dependabot is configured to open low-noise weekly updates:

- npm updates are grouped by runtime and tooling dependencies.
- GitHub Actions updates are grouped separately.
- Semver-major upgrades are ignored automatically and should be handled manually when the project is ready for a compatibility review.

When reviewing dependency changes, run:

```powershell
npm audit
npm run lint
npm run build
npm run edge:build
npm run edge:lint
dotnet build .\apps\windows-shell\LandslideDesk.Win\LandslideDesk.Win.csproj -c Release
```

For packaging-related changes, also run:

```powershell
npm run desktop:publish
```

## Release Readiness

Before creating a release, confirm:

- README and `docs/` match the current end-to-end public scope.
- `CHANGELOG.md` has a dated entry.
- The Windows package includes `web/index.html`.
- Edge services build and lint from the root workspace.
- Firmware and hardware README files match the published package contents.
- The working tree is clean after removing generated outputs.
- Main branch CI is green.

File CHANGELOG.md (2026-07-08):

# Changelog

All notable changes to this project will be documented in this file.

## 0.1.0 - 2026-07-09

- Extracted the maintained desktop client into a focused public repository.
- Included the React/Vite desktop UI and WPF/WebView2 Windows host.
- Added desktop publish and verification scripts.
- Added open-source project metadata, license, community files, and CI workflow.
- Added bilingual documentation, maintainer guidance, and low-noise dependency automation.
- Retained the original repository history while narrowing the current public tree to the maintained desktop client.

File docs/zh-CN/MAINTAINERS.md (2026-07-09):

# 维护者指南

本项目公开仓库聚焦当前维护、可构建、可复核的系统面：Windows 桌面客户端、RK3568 边缘服务、RK2206 现场固件包、载板硬件交付资料、打包脚本和公开文档。

## 评审原则

- 改动应落在有文档说明的产品面内；重新引入旧模块时应补充公开 README 和验证路径。
- UI 改动建议保持 PR 小而清晰，并附截图或录屏；固件、边缘服务或硬件改动应写清复核要点。
- `dist/`、`bin/`、`obj/`、`artifacts/`、本地报告、运行状态和打包输出目录等生成物保留在 Git 之外。
- 凭据、生产端点、点位特定配置和本机环境值保留在 Git 之外。
- 合并前应确认 CI 通过。

## 依赖更新

Dependabot 已配置为低噪音的每周更新：

- npm 依赖按运行时依赖和工具链依赖分组。
- GitHub Actions 依赖单独分组。
- semver-major 更新默认忽略，应在项目准备好做兼容性评审时手动处理。

评审依赖更新时运行：

```powershell
npm audit
npm run lint
npm run build
npm run edge:build
npm run edge:lint
dotnet build .\apps\windows-shell\LandslideDesk.Win\LandslideDesk.Win.csproj -c Release
```

如果改动涉及打包流程，还需要运行：

```powershell
npm run desktop:publish
```

## 发布前检查

创建 release 前确认：

- README 和 `docs/` 与当前端到端公开范围一致。
- `CHANGELOG.md` 有对应日期的记录。
- Windows 发布包包含 `web/index.html`。
- 边缘服务可从仓库根目录 build/lint。
- 固件和硬件 README 与发布包内容一致。
- 清理生成物后工作区干净。
- main 分支 CI 为绿色。

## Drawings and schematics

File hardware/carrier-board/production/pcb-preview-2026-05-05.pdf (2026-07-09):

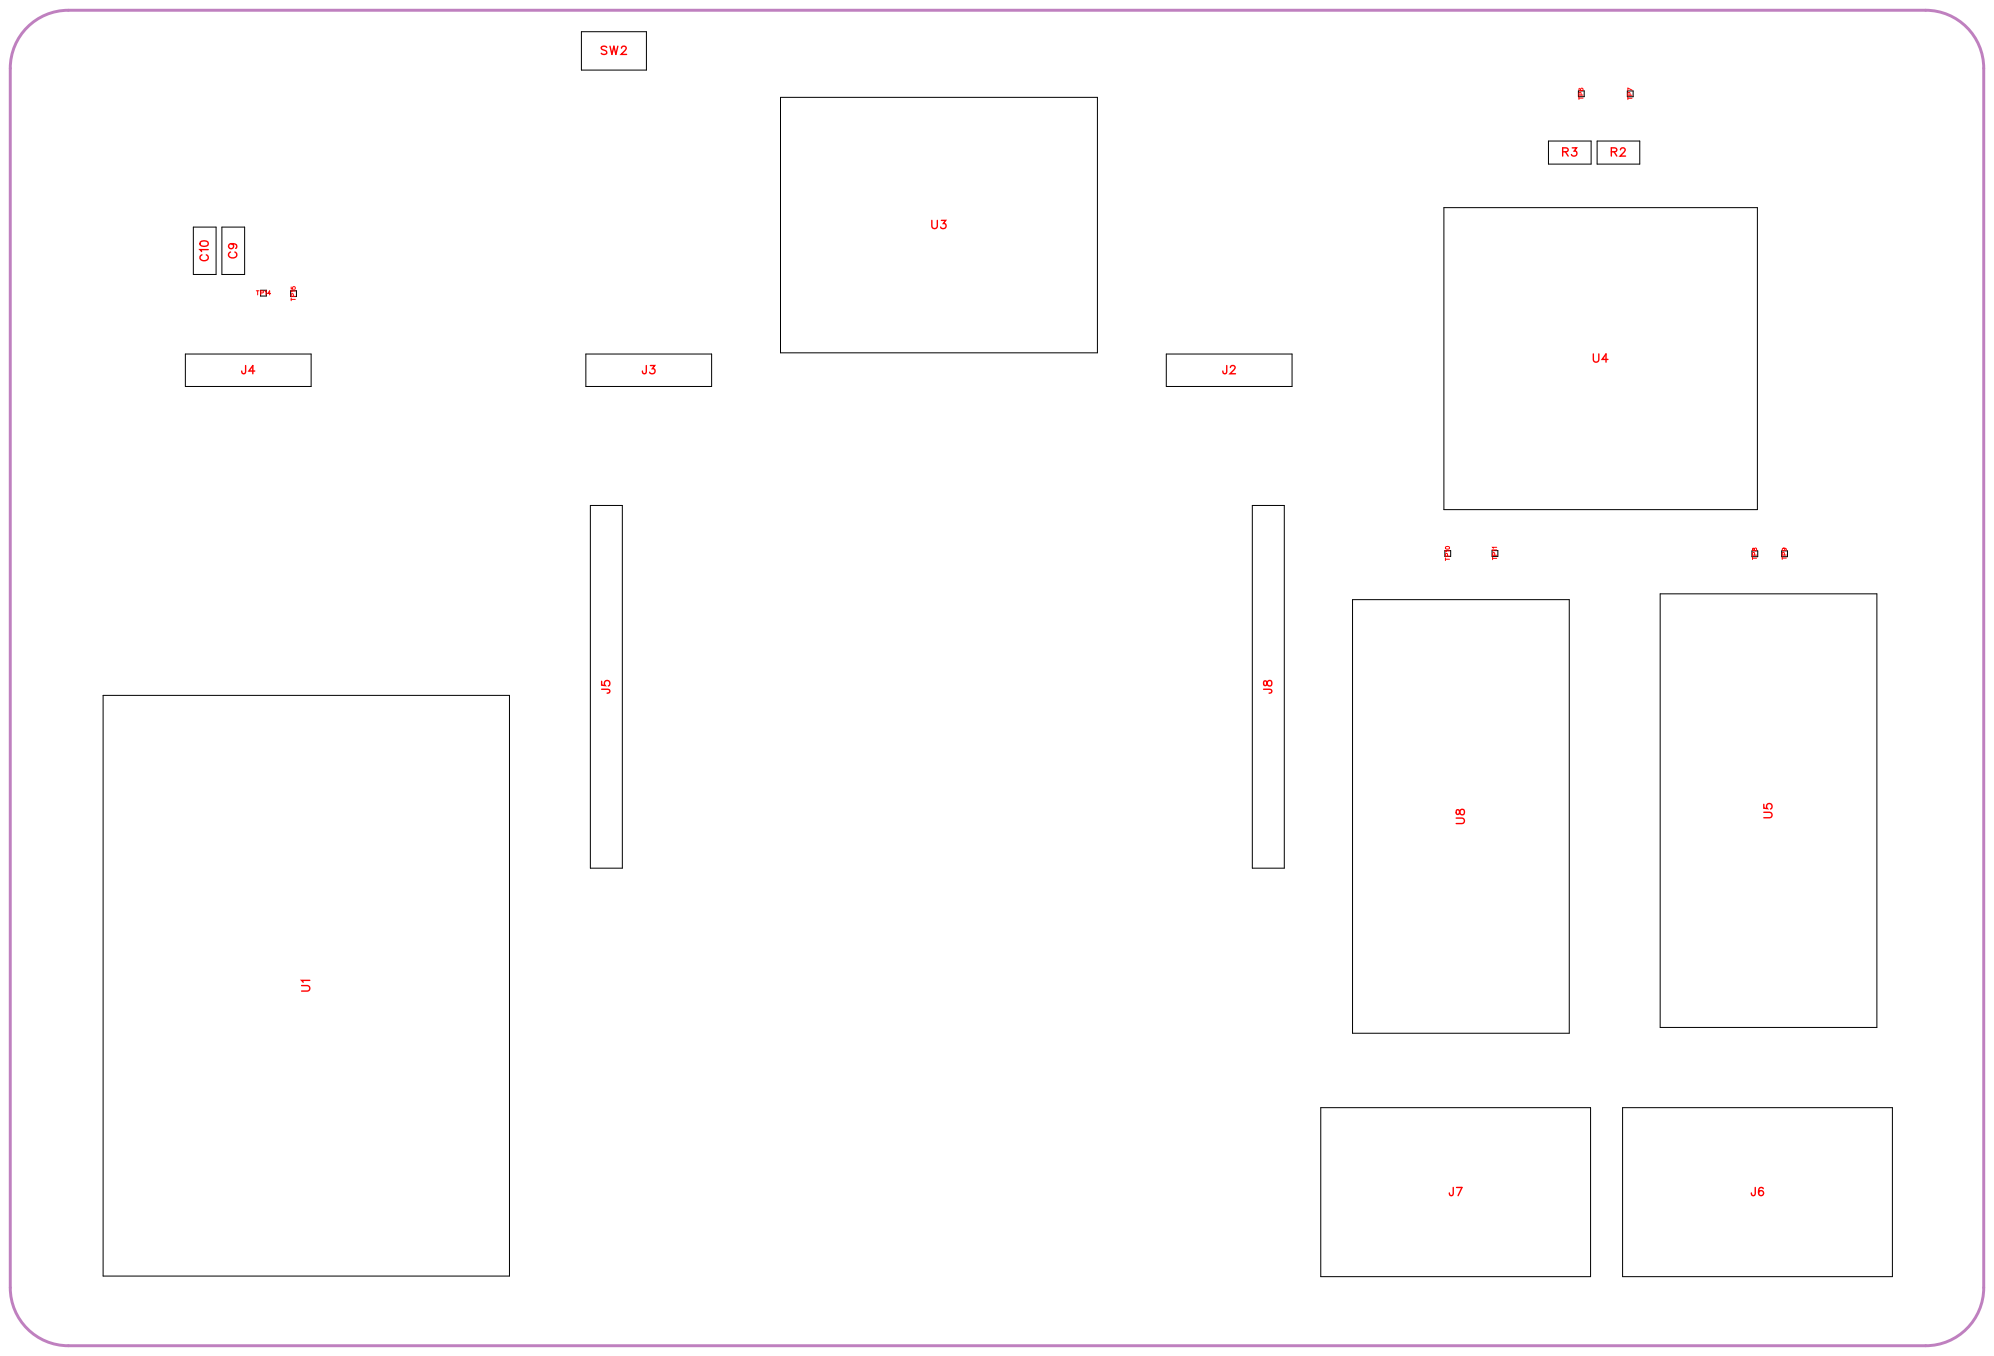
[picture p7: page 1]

No. | Quantity | Comment | Designator | Footprint | Value | Manufacturer Part | Manufacturer | Supplier Part | Supplier
1 | 1 | 100nF | C9 | C0805 | 100nF | CC0805KRX 7R9BB104 | YAGEO(国巨 ) | C49678 | LCSC
2 | 1 | 10uF | C10 | C0805 | 10uF | CGA0805X5 R106K500M T | HRE(芯声) | C6119889 | LCSC
3 | 3 | HDR-F_2.54 _1x4P | J2,J3,J4 | HDR-TH_4P-P2.54-V-F | | | | C2718488
4 | 2 | RK2206_IF | J5,J8 | HDR-TH_12 P-P2.54-V-F
5 | 2 | KF142R-5.08 -4P | J6,J7 | CONN-TH_4 P-P5.08_KF1 42R-5.08-4P | | KF142R-5.08 -4P | KEFA(科发) | C475146 | LCSC
6 | 2 | 4.7k | R2,R3 | R0805 | 4.7K
7 | 1 | XLS1_KEY | SW2 | Key_SMD_3 x4x2
8 | 1 | TP_I2C_SCL | TP6 | Test-Point-0. 5mm
9 | 1 | TP_I2C_SDA | TP7 | Test-Point-0. 5mm
10 | 6 | Test-Point | TP8,TP9,TP10,TP11,TP14, TP15 | Test-Point-0. 5mm
11 | 1 | PWR_MOD_ 12V_5V_3V3 | U1 | PWR_MOD_ 50X35_12V_ 5V_3V3
12 | 1 | XLS1 | U3 | MODULE
13 | 1 | CJMCU-752_ MODULE | U4 | CJMCU752_ SOCKET_2X 8_2X5_P2.54
14 | 1 | RS485_ISO_ MOD_1 | U5 | 隔离型TTL转 485模块PCB 半孔封装
15 | 1 | RS485_ISO_ HALFHOLE_ MODULE | U8 | 隔离型TTL转 485模块PCB 半孔封装

Landslide_V1.2 | TP6 | TP7

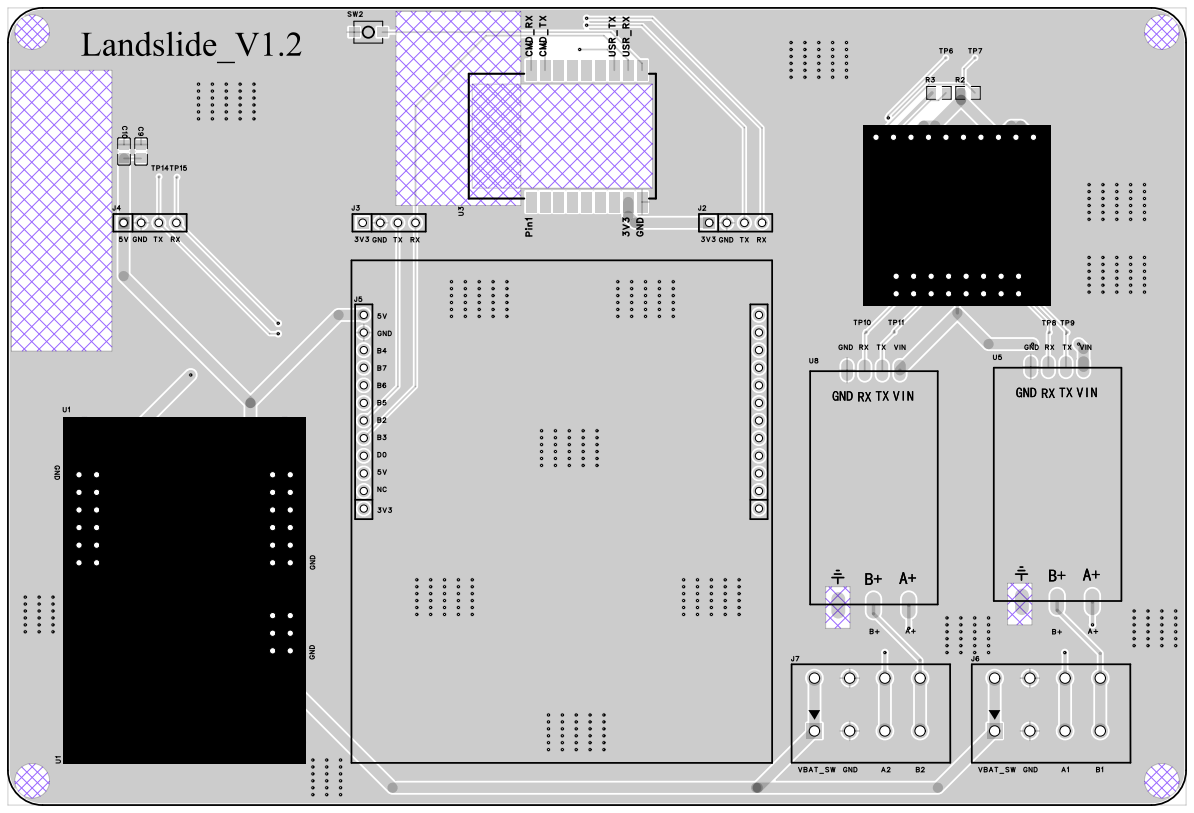
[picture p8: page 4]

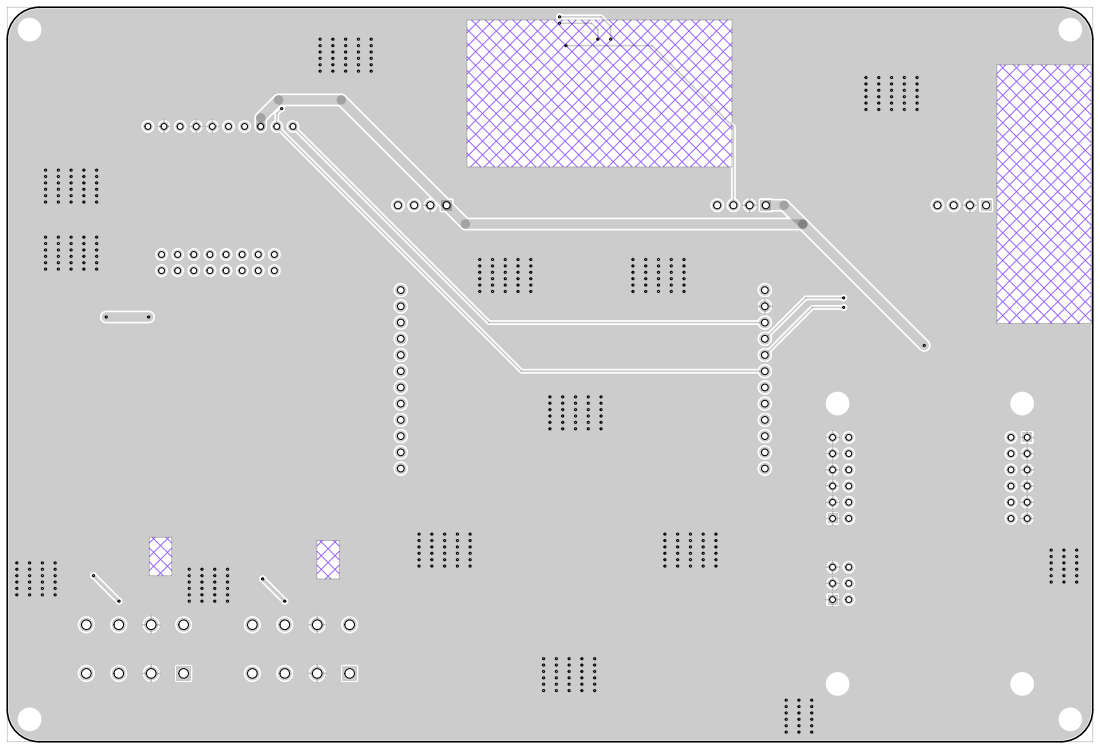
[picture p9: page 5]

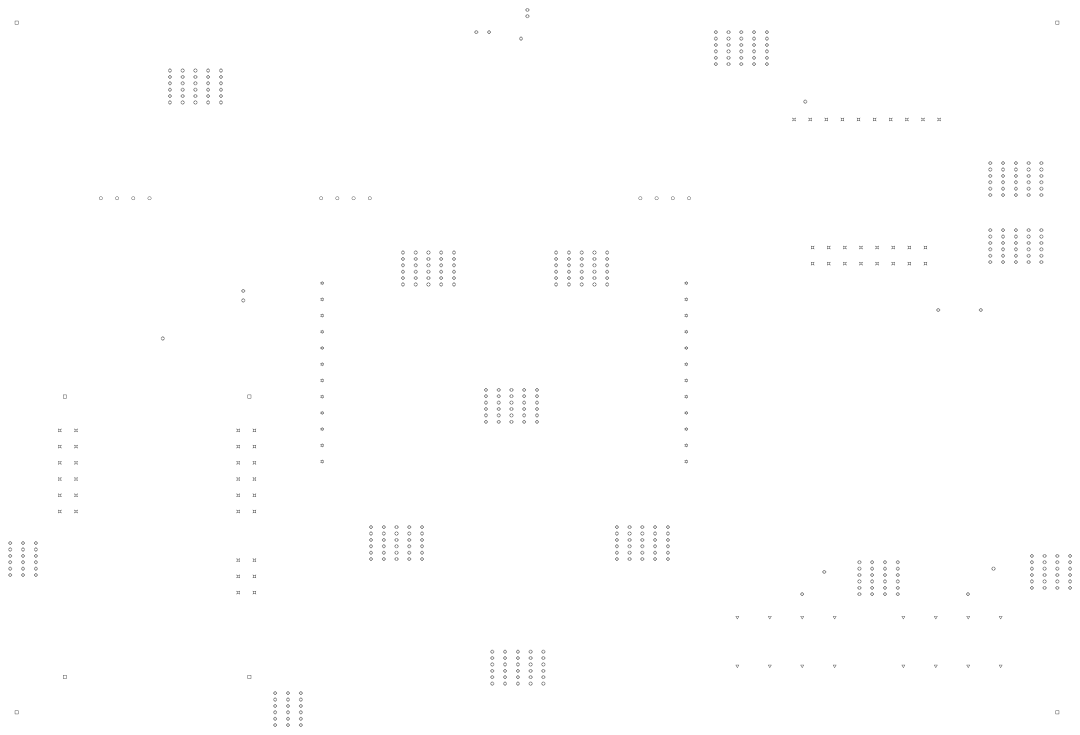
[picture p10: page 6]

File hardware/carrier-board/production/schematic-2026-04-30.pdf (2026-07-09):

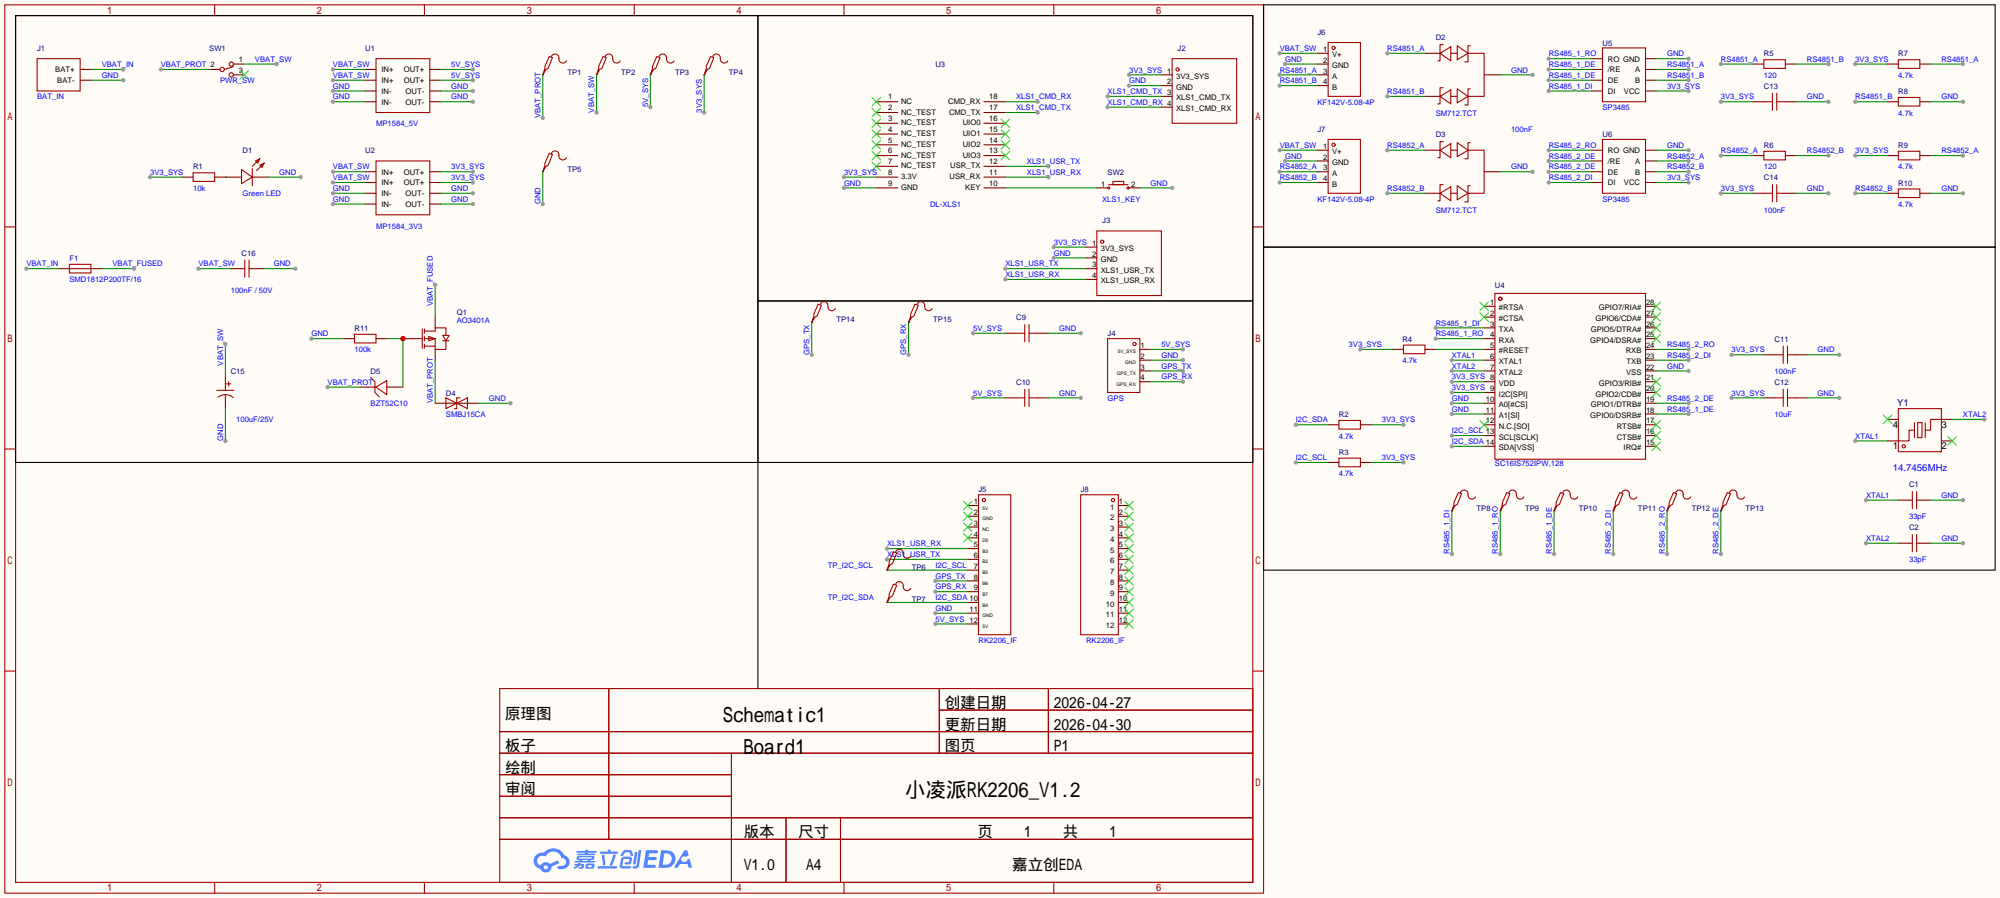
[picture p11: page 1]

原理图 | Schematic1 | 创建日期 | 2026-04-27

更新日期 | 2026-04-30

板子 | Board1 | 图页 | P1
绘制 | | 小凌派RK2206_V1.2
审阅

V1.0 | A4 | 嘉立创EDA

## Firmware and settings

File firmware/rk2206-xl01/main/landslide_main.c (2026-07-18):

/*
 * Landslide Monitoring System - Main Application
 * RK2206 + XL01 Wireless Module
 * 
 * Architecture: Production-grade modular design
 * - Separation of concerns (drivers, utils, app, config)
 * - Hardware abstraction layer
 * - Resource management
 * - Multi-tasking with priority
 */

#include <stdio.h>
#include <math.h>
#include <string.h>
#include <stdbool.h>
#include <time.h>
#include "los_task.h"
#include "ohos_init.h"
#include "cmsis_os.h"
#include "iot_i2c.h"

// Configuration
#include "../config/app_config.h"

// Some OpenHarmony/WSL build trees have lagged behind the latest app_config.h
// update. Keep a local fallback so the mainline polled-uplink build still
// compiles even if the mounted header is stale.
#ifndef EDGE_UPLINK_MODE_PERIODIC
#define EDGE_UPLINK_MODE_PERIODIC 0
#endif

#ifndef EDGE_UPLINK_MODE_POLLED
#define EDGE_UPLINK_MODE_POLLED 1
#endif

#ifndef EDGE_UPLINK_MODE
#define EDGE_UPLINK_MODE EDGE_UPLINK_MODE_POLLED
#endif

#ifndef PLATFORM_COMMAND_RX_LOG_MODE
#define PLATFORM_COMMAND_RX_LOG_MODE 0
#endif

#ifndef BOOT_SERIAL_DIAG_MODE
#define BOOT_SERIAL_DIAG_MODE 0
#endif

// Utilities
#include "../utils/fifo.h"
#include "../utils/watchdog_mgr.h"

// Drivers
#include "../drivers/xl01/xl01_driver.h"
#if ENABLE_SHT30
#include "../drivers/sensors/sht30_driver.h"
#endif
#if ENABLE_MPU6050
#include "../drivers/sensors/mpu6050_driver.h"
#endif
#if ENABLE_GPS
#include "../drivers/sensors/gps_driver.h"
#endif
#if ENABLE_RS485_BUS
#include "../drivers/sensors/field_sensors_rs485.h"
#include "../drivers/sensors/field_alarm_rs485.h"
#endif

// Application
#include "../app/sensor_data.h"
#include "../app/device_command_parser.h"
#include "../app/command_ack_builder.h"
#include "../app/device_identity.h"
#include "../app/shared_port_scheduler.h"
#include "../app/telemetry_envelope_builder.h"

// Keep the local command/runtime path decoupled from the legacy monolithic
// header, which defines a conflicting SensorData shape for another sample.
typedef enum {
    MOTOR_DIRECTION_STOP = 0,
    MOTOR_DIRECTION_FORWARD = 1,
    MOTOR_DIRECTION_REVERSE = 2,
} MotorDirection;

#if FIELD_LINK_POSTTX_DIAG_MODE
#define APP_UPLOAD_TASK_STACK_SIZE       12288
#define APP_PROCESS_TASK_STACK_SIZE      16384
#define APP_SHARED_PORT_TASK_STACK_SIZE  12288
#else
// The command hot path now includes JSON dequeue, parse, ACK build and field-link encode.
// Real command traffic has proven the old 4KB worker stacks are no longer sufficient.
#define APP_UPLOAD_TASK_STACK_SIZE       8192
#define APP_PROCESS_TASK_STACK_SIZE      12288
#define APP_SHARED_PORT_TASK_STACK_SIZE  8192
#endif

// ==================== Global State ====================

static SensorData g_sensor_data = {0};
static osMutexId_t g_sensor_data_mutex = NULL;
static Statistics g_stats = {0};
// Keep the platform command staging buffer off the ProcessTask stack.
static char g_process_command_json[FIELD_LINK_MAX_PAYLOAD_BYTES + 1] = {0};
static int g_system_ready = 0;
static int g_i2c_ready = 0;
static int g_sht30_ready = 0;
static int g_mpu6050_ready = 0;
static int g_rs485_ready = 0;
static unsigned int g_runtime_sampling_interval_ms = 1000;
static unsigned int g_runtime_report_interval_ms = UPLOAD_INTERVAL_MS;
static int g_platform_uplink_enabled = 1;
static volatile int g_platform_manual_collect_requested = 0;
static volatile int g_platform_poll_latest_requested = 0;
static volatile unsigned int g_platform_uplink_quiet_remaining_ms = 0;
static char g_last_platform_command_type[32] = "";
static char g_last_platform_command_id[64] = "";
static unsigned int g_last_platform_command_uptime_s = 0;
static char g_last_trusted_time_ts[40] = "";
static char g_last_trusted_time_source[32] = "";
static volatile uint32_t g_last_platform_command_tick = 0;
static volatile int g_field_link_recovery_requested = 0;
#define FW_RX_DIAG_MARKER "fw-field-link-auto-recovery-20260719"
bool g_cloud_motor_enabled = false;
int g_cloud_motor_speed = 0;
MotorDirection g_cloud_motor_direction = MOTOR_DIRECTION_STOP;
int g_cloud_motor_duration = 0;
bool g_cloud_buzzer_enabled = false;
bool g_cloud_rgb_enabled = false;
bool g_cloud_voice_enabled = false;
bool g_cloud_test_mode = false;
int g_cloud_rgb_red = 0;
int g_cloud_rgb_green = 0;
int g_cloud_rgb_blue = 0;

#define ACK_TS_BEIJING_OFFSET_SECONDS (8 * 60 * 60)
#define ACK_TS_MIN_VALID_UNIX_SECONDS ((time_t)1704067200)
#define COMMAND_INTERVAL_MIN_SECONDS 1
#define COMMAND_INTERVAL_MAX_SECONDS 3600
#define COMMAND_REBOOT_DELAY_MS 1000U
#define SENSOR_I2C_SETTLE_MS 50U
#define MPU6050_INIT_RETRY_COUNT 3
#define MPU6050_INIT_RETRY_DELAY_MS 150U
#define SENSOR_REINIT_RETRY_MS 5000U

static void SensorData_Lock(void)
{
    if (g_sensor_data_mutex != NULL) {
        osMutexAcquire(g_sensor_data_mutex, osWaitForever);
    }
}

static void SensorData_Unlock(void)
{
    if (g_sensor_data_mutex != NULL) {
        osMutexRelease(g_sensor_data_mutex);
    }
}

static void SensorData_CopySnapshot(SensorData *snapshot)
{
    if (snapshot == NULL) {
        return;
    }

    SensorData_Lock();
    memcpy(snapshot, &g_sensor_data, sizeof(*snapshot));
    SensorData_Unlock();
}

static void SensorData_StoreSnapshot(const SensorData *snapshot)
{
    unsigned int seq;

    if (snapshot == NULL) {
        return;
    }

    SensorData_Lock();
    seq = g_sensor_data.seq;
    memcpy(&g_sensor_data, snapshot, sizeof(g_sensor_data));
    g_sensor_data.seq = seq;
    SensorData_Unlock();
}

static void SensorData_TakeUploadSnapshot(SensorData *snapshot)
{
    if (snapshot == NULL) {
        return;
    }

    memset(snapshot, 0, sizeof(*snapshot));
    SensorData_Lock();
    memcpy(snapshot, &g_sensor_data, sizeof(*snapshot));
    snapshot->seq = g_sensor_data.seq + 1;
    g_sensor_data.seq = snapshot->seq;
    SensorData_Unlock();
}

static unsigned int SensorData_GetUptimeSnapshot(void)
{
    unsigned int uptime;

    SensorData_Lock();
    uptime = g_sensor_data.uptime;
    SensorData_Unlock();
    return uptime;
}

static int TryInitMpu6050WithRetry(const char *phase_tag)
{
    int attempt;

    for (attempt = 1; attempt <= MPU6050_INIT_RETRY_COUNT; ++attempt) {
        if (attempt > 1) {
            printf(
                "[WARN] MPU6050 init retry %d/%d phase=%s after %u ms\n",
                attempt,
                MPU6050_INIT_RETRY_COUNT,
                phase_tag != NULL ? phase_tag : "unknown",
                MPU6050_INIT_RETRY_DELAY_MS
            );
            LOS_Msleep(MPU6050_INIT_RETRY_DELAY_MS);
        }

        if (MPU6050_Init() == 0) {
            return 0;
        }
    }

    return -1;
}

static int FormatUnixTimeAsBeijingIso8601(time_t unix_seconds, char *output, int output_size)
{
    time_t beijing_seconds;
    struct tm *tm_ptr;
    struct tm tm_value;

    if (output == NULL || output_size <= 0) {
        return -1;
    }

    beijing_seconds = unix_seconds + ACK_TS_BEIJING_OFFSET_SECONDS;
    tm_ptr = gmtime(&beijing_seconds);
    if (tm_ptr == NULL) {
        return -1;
    }
    tm_value = *tm_ptr;

    if (snprintf(
            output,
            (size_t)output_size,
            "%04d-%02d-%02dT%02d:%02d:%02d+08:00",
            tm_value.tm_year + 1900,
            tm_value.tm_mon + 1,
            tm_value.tm_mday,
            tm_value.tm_hour,
            tm_value.tm_min,
            tm_value.tm_sec) >= output_size) {
        return -1;
    }

    return 0;
}

static const char *GetCommandTrustedTimeTs(const DeviceCommandMessage *cmd)
{
    if (cmd == NULL) {
        return NULL;
    }
    if (cmd->has_gateway_sent_ts && cmd->gateway_sent_ts[0] != '\0') {
        return cmd->gateway_sent_ts;
    }
    if (cmd->has_time_sync_sent_ts && cmd->time_sync_sent_ts[0] != '\0') {
        return cmd->time_sync_sent_ts;
    }
    if (cmd->has_sent_ts && cmd->sent_ts[0] != '\0') {
        return cmd->sent_ts;
    }
    return NULL;
}

static const char *GetCommandTrustedTimeSource(const DeviceCommandMessage *cmd)
{
    if (cmd == NULL) {
        return "unknown";
    }
    if (cmd->has_gateway_sent_ts && cmd->gateway_sent_ts[0] != '\0') {
        return "rk3568_gateway_sent_ts";
    }
    if (cmd->has_time_sync_sent_ts && cmd->time_sync_sent_ts[0] != '\0') {
        return "rk3568_time_sync";
    }
    if (cmd->has_sent_ts && cmd->sent_ts[0] != '\0') {
        return "rk3568_sent_ts";
    }
    return "unknown";
}

static int BuildAckTimestamp(
    const DeviceCommandMessage *cmd,
    char *output,
    int output_size,
    const char **time_source
)
{
    time_t now;
    static int g_ack_ts_clock_warned = 0;
    const char *trusted_ts;

    if (output == NULL || output_size <= 0) {
        return 0;
    }

    trusted_ts = GetCommandTrustedTimeTs(cmd);
    if (trusted_ts != NULL && trusted_ts[0] != '\0') {
        strncpy(output, trusted_ts, (size_t)output_size - 1);
        output[output_size - 1] = '\0';
        if (time_source != NULL) {
            *time_source = GetCommandTrustedTimeSource(cmd);
        }
        return 1;
    }

    now = time(NULL);
    if (now >= ACK_TS_MIN_VALID_UNIX_SECONDS &&
        FormatUnixTimeAsBeijingIso8601(now, output, output_size) == 0) {
        if (time_source != NULL) {
            *time_source = "clock_realtime";
        }
        return 1;
    }

    if (!g_ack_ts_clock_warned) {
        g_ack_ts_clock_warned = 1;
#if PLATFORM_COMMAND_RX_LOG_MODE
        printf("[TIME WARN] CLOCK_REALTIME unavailable or unsynced; ack_ts falls back to uptime-derived Beijing placeholder\n");
#endif
    }

    if (FormatUnixTimeAsBeijingIso8601((time_t)SensorData_GetUptimeSnapshot(), output, output_size) != 0) {
        snprintf(output, (size_t)output_size, "1970-01-01T08:00:00+08:00");
    }
    if (time_source != NULL) {
        *time_source = "uptime_fallback";
    }
    return 0;
}

static int BuildAckResultJsonWithTimeSource(
    const char *base_result_json_fragment,
    const char *time_source,
    char *output,
    int output_size
)
{
    int base_len;
    int written;

    if (output == NULL || output_size <= 0) {
        return -1;
    }
    if (time_source == NULL || time_source[0] == '\0') {
        time_source = "unknown";
    }

    if (base_result_json_fragment == NULL || base_result_json_fragment[0] == '\0') {
        written = snprintf(
            output,
            (size_t)output_size,
            "{\"time_source\":\"%s\"}",
            time_source
        );
        return (written > 0 && written < output_size) ? written : -1;
    }

    base_len = (int)strlen(base_result_json_fragment);
    if (base_len >= 2 &&
        base_result_json_fragment[0] == '{' &&
        base_result_json_fragment[base_len - 1] == '}') {
        written = snprintf(
            output,
            (size_t)output_size,
            "%.*s,\"time_source\":\"%s\"}",
            base_len - 1,
            base_result_json_fragment,
            time_source
        );
        return (written > 0 && written < output_size) ? written : -1;
    }

    written = snprintf(
        output,
        (size_t)output_size,
        "{\"detail\":\"unstructured_result_fragment\",\"time_source\":\"%s\"}",
        time_source
    );
    return (written > 0 && written < output_size) ? written : -1;
}

static void RecordAcceptedPlatformCommand(const DeviceCommandMessage *cmd)
{
    const char *trusted_ts;

    if (cmd == NULL) {
        return;
    }

    strncpy(g_last_platform_command_type, cmd->command_type, sizeof(g_last_platform_command_type) - 1);
    g_last_platform_command_type[sizeof(g_last_platform_command_type) - 1] = '\0';

    strncpy(g_last_platform_command_id, cmd->command_id, sizeof(g_last_platform_command_id) - 1);
    g_last_platform_command_id[sizeof(g_last_platform_command_id) - 1] = '\0';

    g_last_platform_command_uptime_s = SensorData_GetUptimeSnapshot();
    g_last_platform_command_tick = (uint32_t)LOS_TickCountGet();

    trusted_ts = GetCommandTrustedTimeTs(cmd);
    if (trusted_ts != NULL && trusted_ts[0] != '\0') {
        strncpy(g_last_trusted_time_ts, trusted_ts, sizeof(g_last_trusted_time_ts) - 1);
        g_last_trusted_time_ts[sizeof(g_last_trusted_time_ts) - 1] = '\0';
        strncpy(g_last_trusted_time_source, GetCommandTrustedTimeSource(cmd), sizeof(g_last_trusted_time_source) - 1);
        g_last_trusted_time_source[sizeof(g_last_trusted_time_source) - 1] = '\0';
    }
}

static void* FieldLinkHealthTask(const char* arg)
{
    (void)arg;

    printf(
        "[Task] Field Link Health started (auto_recovery=%s stale=%u ms)\n",
        ENABLE_FIELD_LINK_AUTO_RECOVERY ? "yes" : "no",
        (unsigned int)FIELD_LINK_STALE_REBOOT_MS
    );

    while (1) {
#if ENABLE_FIELD_LINK_AUTO_RECOVERY && EDGE_UPLINK_MODE == EDGE_UPLINK_MODE_POLLED
        uint32_t now_tick = (uint32_t)LOS_TickCountGet();
        uint32_t last_command_tick = g_last_platform_command_tick;
        uint32_t stale_ticks = LOS_MS2Tick(FIELD_LINK_STALE_REBOOT_MS);

        if (!g_field_link_recovery_requested &&
            stale_ticks > 0U &&
            (uint32_t)(now_tick - last_command_tick) >= stale_ticks &&
            last_command_tick == g_last_platform_command_tick) {
            g_field_link_recovery_requested = 1;
            printf(
                "[LINK RECOVERY] no accepted gateway command for %u ms; rebooting node in %u ms\n",
                (unsigned int)FIELD_LINK_STALE_REBOOT_MS,
                (unsigned int)FIELD_LINK_RECOVERY_REBOOT_DELAY_MS
            );
            Watchdog_RequestReboot(FIELD_LINK_RECOVERY_REBOOT_DELAY_MS);
        }
#endif
        LOS_Msleep(FIELD_LINK_RECOVERY_CHECK_MS);
    }

    return NULL;
}

static void ExtendPlatformUplinkQuietWindow(unsigned int quiet_ms)
{
    if (quiet_ms == 0) {
        return;
    }

    if (quiet_ms > g_platform_uplink_quiet_remaining_ms) {
        g_platform_uplink_quiet_remaining_ms = quiet_ms;
    }
}

static void ArmPlatformCommandQuietWindow(const char *command_type)
{
#if ENABLE_SHARED_PORT_SOURCE_CONTROL
    SharedPortScheduler_BeginQuietWindow(command_type, g_last_platform_command_id);
#else
    unsigned int quiet_ms = PLATFORM_POST_ACK_QUIET_MS;

    if (command_type != NULL &&
        (strcmp(command_type, "manual_collect") == 0 ||
         strcmp(command_type, "poll_latest_telemetry") == 0)) {
        quiet_ms += PLATFORM_MANUAL_COLLECT_DELAY_MS;
    }

    ExtendPlatformUplinkQuietWindow(quiet_ms);
#if PLATFORM_COMMAND_RX_LOG_MODE
    printf(
        "[CMD GUARD] type=%s quiet_ms=%u\n",
        command_type != NULL ? command_type : "(null)",
        quiet_ms
    );
#endif
#endif
}

static int SendPlatformCommandAckWithGuard(
    const DeviceCommandMessage *cmd,
    const char *status,
    const char *result_json_fragment,
    int trigger_manual_collect,
    int trigger_poll_latest
)
{
    char ackTs[32];
    char ackPayload[512];
    char ackResultJson[320];
    const char *effectiveResultJson = NULL;
    int ackLen;
    int sendRet = -1;
    int ackAccepted = 0;
    const char *ackTimeSource = NULL;

    if (cmd == NULL || status == NULL) {
        return -1;
    }

    BuildAckTimestamp(cmd, ackTs, sizeof(ackTs), &ackTimeSource);
    if (BuildAckResultJsonWithTimeSource(
            result_json_fragment,
            ackTimeSource,
            ackResultJson,
            sizeof(ackResultJson)
        ) > 0) {
        effectiveResultJson = ackResultJson;
    } else {
        effectiveResultJson = result_json_fragment;
    }

    ackLen = BuildDeviceCommandAckV1(
        cmd->command_id,
        status,
        effectiveResultJson,
        ackTs,
        ackPayload,
        sizeof(ackPayload)
    );

    if (ackLen <= 0 || ackLen >= (int)sizeof(ackPayload)) {
        printf("[CMD ACK BUILD FAIL] type=%s id=%s len=%d\n", cmd->command_type, cmd->command_id, ackLen);
        sendRet = -1;
    } else {
#if ENABLE_SHARED_PORT_SOURCE_CONTROL
        sendRet = SharedPortScheduler_EnqueueAckOrResult(
            cmd->command_type,
            cmd->command_id,
            ackPayload,
            ackLen
        );
#else
        sendRet = XL01_SendPlatformCommandAck(ackPayload, ackLen);
#endif
        if (sendRet == ackLen) {
            ackAccepted = 1;
        } else {
            printf("[CMD ACK TX FAIL] type=%s id=%s ret=%d len=%d\n",
                   cmd->command_type,
                   cmd->command_id,
                   sendRet,
                   ackLen);
        }
    }

    if (!ackAccepted) {
        if (trigger_manual_collect || trigger_poll_latest) {
            printf("[CMD FOLLOWUP BLOCKED] type=%s id=%s ack_unavailable\n",
                   cmd->command_type,
                   cmd->command_id);
        }
        return sendRet;
    }

    RecordAcceptedPlatformCommand(cmd);
    ArmPlatformCommandQuietWindow(cmd->command_type);
    if (trigger_manual_collect) {
        g_platform_manual_collect_requested = 1;
    }
    if (trigger_poll_latest) {
        g_platform_poll_latest_requested = 1;
    }

    return sendRet;
}

static int BuildRuntimeConfigResultJson(
    int include_sampling_s,
    int include_report_interval_s,
    char *output,
    int output_size
)
{
    int first = 1;
    int len = 0;

    if (output == NULL || output_size <= 0) {
        return -1;
    }

    len = snprintf(output, (size_t)output_size, "{\"applied\":true,\"applied_keys\":[");
    if (len < 0 || len >= output_size) {
        return -1;
    }

    if (include_sampling_s) {
        len += snprintf(
            output + len,
            (size_t)(output_size - len),
            "%s\"sampling_s\"",
            first ? "" : ","
        );
        if (len < 0 || len >= output_size) {
            return -1;
        }
        first = 0;
    }

    if (include_report_interval_s) {
        len += snprintf(
            output + len,
            (size_t)(output_size - len),
            "%s\"report_interval_s\"",
            first ? "" : ","
        );
        if (len < 0 || len >= output_size) {
            return -1;
        }
    }

    len += snprintf(
        output + len,
        (size_t)(output_size - len),
        "],\"effective\":{\"sampling_s\":%u,\"report_interval_s\":%u},\"runtime_config\":{\"sampling_s\":%u,\"report_interval_s\":%u}}",
        g_runtime_sampling_interval_ms / 1000,
        g_runtime_report_interval_ms / 1000,
        g_runtime_sampling_interval_ms / 1000,
        g_runtime_report_interval_ms / 1000
    );
    if (len < 0 || len >= output_size) {
        return -1;
    }

    return len;
}

static int IsRuntimeIntervalValid(int seconds)
{
    return seconds >= COMMAND_INTERVAL_MIN_SECONDS && seconds <= COMMAND_INTERVAL_MAX_SECONDS;
}

static void HandlePlatformCommand(const char *commandJson)
{
    DeviceCommandMessage cmd;
    const DeviceIdentity *identity;
    char resultJson[256];
    int sendRet;

    if (ParseDeviceCommandV1(commandJson, &cmd) != 0) {
        printf("[CMD PARSE FAIL] %s\n", commandJson != NULL ? commandJson : "(null)");
        return;
    }

    identity = DeviceIdentity_Get();
    if (identity == NULL || identity->device_id == NULL) {
        printf("[CMD IGNORE] missing local device identity\n");
        return;
    }
    if (strcmp(cmd.device_id, identity->device_id) != 0) {
#if PLATFORM_COMMAND_RX_LOG_MODE
        printf("[CMD IGNORE] device_id mismatch cmd=%s local=%s\n", cmd.device_id, identity->device_id);
#endif
        return;
    }

#if PLATFORM_COMMAND_RX_LOG_MODE
    printf(
        "[CMD APPLY] type=%s id=%s sampling=%d report=%d intervalSeconds=%d\n",
        cmd.command_type,
        cmd.command_id,
        cmd.has_sampling_s ? cmd.sampling_s : -1,
        cmd.has_report_interval_s ? cmd.report_interval_s : -1,
        cmd.has_interval_seconds ? cmd.interval_seconds : -1
    );
#endif

    if (strcmp(cmd.command_type, "ping") == 0) {
        SendPlatformCommandAckWithGuard(&cmd, "acked", "{\"pong\":true}", 0, 0);
        return;
    }

    if (strcmp(cmd.command_type, "set_config") == 0) {
        if (!cmd.has_sampling_s && !cmd.has_report_interval_s) {
            SendPlatformCommandAckWithGuard(&cmd, "failed", "{\"error\":\"no_supported_keys\"}", 0, 0);
            return;
        }

        if (cmd.has_sampling_s && !IsRuntimeIntervalValid(cmd.sampling_s)) {
            snprintf(
                resultJson,
                sizeof(resultJson),
                "{\"error\":\"invalid_sampling_s\",\"min\":%d,\"max\":%d,\"received\":%d}",
                COMMAND_INTERVAL_MIN_SECONDS,
                COMMAND_INTERVAL_MAX_SECONDS,
                cmd.sampling_s
            );
            SendPlatformCommandAckWithGuard(&cmd, "failed", resultJson, 0, 0);
            return;
        }

        if (cmd.has_report_interval_s && !IsRuntimeIntervalValid(cmd.report_interval_s)) {
            snprintf(
                resultJson,
                sizeof(resultJson),
                "{\"error\":\"invalid_report_interval_s\",\"min\":%d,\"max\":%d,\"received\":%d}",
                COMMAND_INTERVAL_MIN_SECONDS,
                COMMAND_INTERVAL_MAX_SECONDS,
                cmd.report_interval_s
            );
            SendPlatformCommandAckWithGuard(&cmd, "failed", resultJson, 0, 0);
            return;
        }

        if (cmd.has_sampling_s) {
            g_runtime_sampling_interval_ms = (unsigned int)cmd.sampling_s * 1000;
        }
        if (cmd.has_report_interval_s) {
            g_runtime_report_interval_ms = (unsigned int)cmd.report_interval_s * 1000;
        }
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

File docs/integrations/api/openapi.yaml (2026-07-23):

openapi: 3.0.3
info:
  title: Landslide Monitoring API (v2)
  version: 0.1.0
  description: |
    本文件是 API 契约的机器可读入口（契约优先），与 `docs/integrations/api/*.md` 保持一致。

servers:
  - url: /api/v1

tags:
  - name: auth
  - name: users
  - name: devices
  - name: stations
  - name: data
  - name: ai
  - name: realtime
  - name: camera
  - name: gps
  - name: alerts
  - name: system

security:
  - BearerAuth: []

paths:
  /auth/login:
    post:
      tags: [auth]
      summary: User login
      security: []
      requestBody:
        required: true
        content:
          application/json:
            schema:
              $ref: "#/components/schemas/LoginRequest"
      responses:
        "200":
          description: ok
          content:
            application/json:
              schema:
                allOf:
                  - $ref: "#/components/schemas/SuccessResponse"
                  - type: object
                    properties:
                      data:
                        $ref: "#/components/schemas/LoginResponse"
        "400":
          $ref: "#/components/responses/ErrorResponse"
        "500":
          $ref: "#/components/responses/InternalServerErrorResponse"
        default:
          $ref: "#/components/responses/ErrorResponse"

  /auth/refresh:
    post:
      tags: [auth]
      summary: Refresh token
      security: []
      requestBody:
        required: true
        content:
          application/json:
            schema:
              $ref: "#/components/schemas/RefreshRequest"
      responses:
        "200":
          $ref: "#/components/responses/SuccessResponse"
        "400":
          $ref: "#/components/responses/ErrorResponse"
        "500":
          $ref: "#/components/responses/InternalServerErrorResponse"
        default:
          $ref: "#/components/responses/ErrorResponse"

  /auth/logout:
    post:
      tags: [auth]
      summary: Logout
      responses:
        "200":
          $ref: "#/components/responses/SuccessResponse"
        "401":
          $ref: "#/components/responses/UnauthorizedResponse"
        "403":
          $ref: "#/components/responses/ForbiddenResponse"
        "500":
          $ref: "#/components/responses/InternalServerErrorResponse"
        default:
          $ref: "#/components/responses/ErrorResponse"

  /auth/me:
    get:
      tags: [auth]
      summary: Get current user
      responses:
        "200":
          description: ok
          content:
            application/json:
              schema:
                allOf:
                  - $ref: "#/components/schemas/SuccessResponse"
                  - type: object
                    properties:
                      data:
                        $ref: "#/components/schemas/CurrentUser"
        "401":
          $ref: "#/components/responses/UnauthorizedResponse"
        "403":
          $ref: "#/components/responses/ForbiddenResponse"
        "500":
          $ref: "#/components/responses/InternalServerErrorResponse"
        default:
          $ref: "#/components/responses/ErrorResponse"

  /auth/password:
    put:
      tags: [auth]
      summary: Change password
      requestBody:
        required: true
        content:
          application/json:
            schema:
              $ref: "#/components/schemas/ChangePasswordRequest"
      responses:
        "200":
          $ref: "#/components/responses/SuccessResponse"
        "400":
          $ref: "#/components/responses/ErrorResponse"
        "401":
          $ref: "#/components/responses/UnauthorizedResponse"
        "403":
          $ref: "#/components/responses/ForbiddenResponse"
        "500":
          $ref: "#/components/responses/InternalServerErrorResponse"
        default:
          $ref: "#/components/responses/ErrorResponse"
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

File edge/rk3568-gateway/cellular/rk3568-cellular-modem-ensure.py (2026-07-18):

#!/usr/bin/env python3
"""Verify and recover the RK3568 EC200A cellular modem."""

from __future__ import annotations

import argparse
import json
import os
import re
import subprocess
import sys
import time
from datetime import datetime, timezone
from pathlib import Path
from typing import Any


def env_int(name: str, default: int) -> int:
    try:
        return max(0, int(os.environ.get(name, str(default))))
    except ValueError:
        return default


AT_PORT = Path(os.environ.get("AT_PORT", "/dev/ttyUSB2"))
EXPECTED_APN = os.environ.get("EXPECTED_APN", "cmnet")
ENUM_WAIT_SECONDS = env_int("ENUM_WAIT_SECONDS", 45)
POST_RESET_WAIT_SECONDS = env_int("POST_RESET_WAIT_SECONDS", 20)
POST_RESET_ENUM_WAIT_SECONDS = env_int("POST_RESET_ENUM_WAIT_SECONDS", 90)
RECOVERY_FAILURE_THRESHOLD = max(1, env_int("RECOVERY_FAILURE_THRESHOLD", 2))
REGISTRATION_FAILURE_THRESHOLD = max(
    RECOVERY_FAILURE_THRESHOLD,
    env_int("REGISTRATION_FAILURE_THRESHOLD", 4),
)
RECOVERY_COOLDOWN_SECONDS = env_int("RECOVERY_COOLDOWN_SECONDS", 600)
MAX_RESETS_PER_BOOT = max(1, env_int("MAX_RESETS_PER_BOOT", 1))
USB_DEVICE = os.environ.get("USB_DEVICE", "usb0")
USB_CONNECTION_NAME = os.environ.get("USB_CONNECTION_NAME", "有线连接 2")
FIELD_GATEWAY_SERVICE = os.environ.get(
    "FIELD_GATEWAY_SERVICE", "lsmv2-field-gateway.service"
)
REVERSE_TUNNEL_SERVICE = os.environ.get(
    "REVERSE_TUNNEL_SERVICE", "lsmv2-rk3568-reverse-tunnel.service"
)
GUARDIAN_SERVICE = os.environ.get(
    "GUARDIAN_SERVICE", "lsmv2-rk3568-cellular-link-guardian.service"
)
STATUS_FILE = Path(
    os.environ.get(
        "MODEM_STATUS_FILE", "/var/lib/lsmv2/cellular-cloud/modem-status.json"
    )
)
STATE_FILE = Path(
    os.environ.get(
        "MODEM_STATE_FILE", "/var/lib/lsmv2/cellular-cloud/modem-state.json"
    )
)
LOCK_FILE = Path(
    os.environ.get("MODEM_LOCK_FILE", "/run/lsmv2-cellular-modem-ensure.lock")
)

QUERY_COMMANDS = (
    "AT+CPIN?",
    "AT+CEREG?",
    "AT+CGATT?",
    "AT+CSQ",
    "AT+CGDCONT?",
    "AT+QCCID",
)


def now_iso() -> str:
    return datetime.now(timezone.utc).astimezone().isoformat(timespec="seconds")


def boot_id() -> str:
    try:
        return Path("/proc/sys/kernel/random/boot_id").read_text(
            encoding="ascii"
        ).strip()
    except OSError:
        return "unknown"


def atomic_json_write(path: Path, payload: dict[str, Any], mode: int) -> None:
    path.parent.mkdir(parents=True, exist_ok=True)
    temporary = path.with_name(f".{path.name}.{os.getpid()}.tmp")
    temporary.write_text(
        json.dumps(payload, ensure_ascii=False, indent=2) + "\n", encoding="utf-8"
    )
    os.chmod(temporary, mode)
    os.replace(temporary, path)


def load_state(current_boot_id: str) -> dict[str, Any]:
    state: dict[str, Any] = {}
    try:
        state = json.loads(STATE_FILE.read_text(encoding="utf-8"))
    except (OSError, ValueError, TypeError):
        pass

    if state.get("bootId") != current_boot_id:
        state = {
            "bootId": current_boot_id,
            "consecutiveFailures": 0,
            "resetsThisBoot": 0,
            "lastResetEpoch": 0,
            "totalResets": int(state.get("totalResets", 0) or 0),
        }
    return state


def wait_for_path(path: Path, timeout_seconds: int) -> bool:
    deadline = time.monotonic() + timeout_seconds
    while time.monotonic() <= deadline:
        if path.exists():
            return True
        time.sleep(1)
    return False


def run_at_commands(commands: tuple[str, ...]) -> dict[str, str]:
    try:
        import serial  # type: ignore
    except ImportError as exc:
        raise RuntimeError("python serial module is not installed") from exc

    responses: dict[str, str] = {}
    with serial.Serial(
        str(AT_PORT),
        115200,
        timeout=0.2,
        write_timeout=1,
        exclusive=True,
    ) as modem:
        for command in commands:
            modem.reset_input_buffer()
            modem.write((command + "\r").encode("ascii"))
            modem.flush()
            deadline = time.monotonic() + 1.5
            chunks = bytearray()
            while time.monotonic() < deadline:
                chunk = modem.read(4096)
                if chunk:
                    chunks.extend(chunk)
                    upper = bytes(chunks).upper()
                    if b"\r\nOK\r\n" in upper or b"ERROR" in upper:
                        break
            responses[command] = bytes(chunks).decode("ascii", errors="replace")
    return responses


def registration_state(response: str) -> int | None:
    match = re.search(r"\+CEREG:\s*([^\r\n]+)", response, re.IGNORECASE)
    if not match:
        return None
    fields = [field.strip().strip('"') for field in match.group(1).split(",")]
    try:
        if len(fields) >= 2:
            return int(fields[1])
        return int(fields[0])
    except (ValueError, IndexError):
        return None


def parse_snapshot(responses: dict[str, str]) -> dict[str, Any]:
    cpin = responses.get("AT+CPIN?", "")
    qccid = responses.get("AT+QCCID", "")
    cereg = responses.get("AT+CEREG?", "")
    cgatt = responses.get("AT+CGATT?", "")
    contexts = responses.get("AT+CGDCONT?", "")
    csq = responses.get("AT+CSQ", "")

    sim_ready = "+CPIN: READY" in cpin.upper()
    sim_detected = "+QCCID:" in qccid.upper() and "+CME ERROR: 10" not in qccid.upper()
    reg_state = registration_state(cereg)
    registered = reg_state in (1, 5)
    attached = bool(re.search(r"\+CGATT:\s*1\b", cgatt, re.IGNORECASE))
    apn_ok = EXPECTED_APN.lower() in contexts.lower()
    signal_match = re.search(r"\+CSQ:\s*(\d+)", csq, re.IGNORECASE)
    signal_rssi = int(signal_match.group(1)) if signal_match else None
    sim_operational = sim_ready or (sim_detected and registered and attached)

    if not sim_operational:
        reason = "sim_not_ready"
    elif not registered:
        reason = "network_not_registered"
    elif not attached:
        reason = "packet_not_attached"
    elif not apn_ok:
        reason = "apn_mismatch"
    else:
        reason = "modem_ready"

    return {
        "ok": reason == "modem_ready",
        "reason": reason,
        "simReady": sim_ready,
        "simDetected": sim_detected,
        "simOperational": sim_operational,
        "registered": registered,
        "registrationState": reg_state,
        "attached": attached,
        "apnOk": apn_ok,
        "expectedApn": EXPECTED_APN,
        "signalRssi": signal_rssi,
    }
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

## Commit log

2025-12-17 Chore/chinese templates (#3)
    * chore(repo): switch GitHub templates to Chinese
    * docs(standards): add language policy and writing rules
    * docs(standards): add governance, DoD, PR howto, kickoff checklist
2025-12-17 docs(standards): 完善仓库治理与重构启动闭环
    - 完善 GitHub Rulesets/分支保护配置指引（必走 PR、必过 CI、禁止强推/删除）。
    - 新增 PR 操作指南与常见 CI 失败处理办法。
    - 新增 Definition of Done（DoD）与重构启动前检查清单。
    - 强化 PR/Issue 模板：补充证据收集与验收要点。
2025-12-17 feat(ingest): 引入 TypeScript 工具链与 ingest-service 骨架
    - Why：进入代码重构阶段，先落地后端 TypeScript(strict) 与 ingest 最小链路，保证后续可扩展、可复用。
    - What：新增 @lsmv2/observability/@lsmv2/validation；新增 services/ingest（schema 校验 + DLQ）；CI 在 docs-and-contracts 内追加 npm lint/build。
    - Verify：python docs/tools/run-quality-gates.py；npm run lint；npm run build。
    - Risk/Rollback：revert 本 commit（对应 PR）。
2025-12-17 docs(ai): 增加交接套件与项目状态页
    - Why：解决换窗口/换模型后无法接手的问题，建立仓库自解释交接入口。
    - What：新增 project-status.md 与 handoff.md，并更新 Docs Hub + AI 清单引用。
    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
2025-12-17 feat(writer): 增加 telemetry-writer（Kafka→ClickHouse）骨架
    - 新增 `services/telemetry-writer`：消费 `telemetry.raw.v1` 并批量写入 ClickHouse
    - 对齐 `docs/` 下 Kafka schema 与 ClickHouse DDL 契约
    - 更新 `docs/guides/roadmap/project-status.md`（交接入口状态）
2025-12-17 feat(api): 增加 data 查询最小端点（state/series）
    - 新增 `services/api`：实现 `/data/state` 与 `/data/series`（ClickHouse 查询）
    - 对齐 `docs/integrations/api/openapi.yaml` 与 `docs/integrations/api/05-data.md`
    - 加入单机查询保护（范围/点数）与 traceId 响应
2025-12-18 docs(testing): add e2e smoke test guide
    - 新增端到端冒烟测试文档与本地发布遥测脚本
    - 更新 project-status：API 已完成，下一步为端到端冒烟联调
    - 调整 ESLint：忽略 scripts/，避免类型感知 lint 误报
2025-12-18 fix(compose): stabilize single-host infra and e2e
    - 修复 Compose：Kafka 镜像切换为 apache/kafka（避免 manifest unknown），健康检查与数据卷对齐
    - 修复 init 脚本：ready 等待 + 失败即中止，create-topics 不依赖 PATH
    - 修复 Postgres DDL：保留字列名、分区表主键约束
    - 服务改进：dotenv 自动加载 .env；Ajv 2020-12 支持 `$schema`
    - 新增 incident：INC-0007
2025-12-18 feat(api): 增加设备注册与传感器配置接口（Postgres） (#14)
    * feat(api): 增加设备注册与传感器配置接口（Postgres）
    * fix(lint): 修复 eslint 规则与忽略目录
2025-12-18 chore(gates): 强制更新项目状态页 + docs(standards): CI 常见问题排查 (#15)
    * docs(handoff): 更新阶段进度与自动合并说明
    * chore(gates): 强制更新项目状态页
    - 在 PR 场景下，若修改 services/infra/apps/libs 或 docs 的关键契约/架构目录，则必须同步更新 project-status.md\n- 作为质量门禁的一部分运行，避免换窗口/换模型后丢失进度与上下文
    * docs(standards): 补充 CI 常见问题排查
    - 收敛 openapi/contract/project-status/ESLint/docker/rulesets 等常见失败与解决办法\n- 作为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
2025-12-18 feat(infra): add single-host e2e smoke runner (#16)
    * feat(e2e): add smoke runner script
    - Add infra/compose/scripts/e2e-smoke-test.ps1 to automate local E2E smoke test and collect logs
    - Make ingest-service MQTT auth optional (username/password must be both set or both empty)
    - Update docs and examples accordingly
    * docs(roadmap): update project status for e2e smoke runner
    - Note the new one-click e2e smoke script and where to find it
    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
2025-12-18 feat(mqtt): add EMQX http authn/authz webhooks (#17)
    - Add /emqx/authn and /emqx/acl endpoints in api-service for device_id+secret auth and topic ACL
    - Support JSON + form-encoded payloads; protect webhooks via optional x-emqx-token
    - Document single-host wiring steps and update project-status
2025-12-18 chore(infra): automate EMQX http auth wiring (#18)
    - Add PowerShell script to configure EMQX authn/authz via dashboard API
    - Document one-command setup and update project status
2025-12-18 feat(e2e): support auth-enabled smoke test (#19)
    - Extend e2e smoke script to optionally configure EMQX authn/authz, create a test device, and publish using device_id/secret
    - Update docs and project-status for stage-1 one-click smoke
2025-12-18 fix(infra): expand clickhouse url in EMQX wiring (#22)
    - configure-emqx-http-auth.ps1 now expands CH_HTTP_URL before writing CLICKHOUSE_URL
    - Update project status note for CI gate
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2025-12-19 fix(writer): commit offsets after ClickHouse insert (#30)
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2025-12-19 test(infra): e2e 覆盖命令 failed + 通知链路 (#44)
    * test(infra): cover command failed notifications
    * docs(roadmap): record e2e failed command case
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2025-12-19 fix(stage2): stabilize alerts + command regression (#56)
    * fix(stage2): stabilize alerts + command regression
    - Fix DSL schema for Ajv strict mode (no union type arrays)
    - Make MQTT command services tolerant to transient authn startup
    - Ensure Kafka topics + deterministic env in Stage2Regression
    - Fix alerts list summary SQL and e2e quoting/exit-code edge cases
    * docs(roadmap): note Stage2Regression re-verified
    [openapi.yaml]
2025-12-19 feat(rules): support station/global scope (#57)
    - rule-engine-worker now matches station/global rules via devices.station_id
    - project-status updated (Stage3 progress note)
2025-12-19 feat(rules): implement metric leaf evaluation (#58)
    - Add DSL v1 metric leaf (last/min/max/avg/delta/slope)
    - Maintain per-rule sensor series for aggregation windows
    - Document slope unit + update project status
2025-12-19 feat(alerts): 完成 Stage3 回放与告警通知闭环
    - Why：完成 Stage3 Next Actions：规则回放/回测 + 告警事件→通知最小闭环，并沉淀到 e2e 证据包
    - What：新增 @lsmv2/rules；rule-engine-worker 发布 lerts.events.v1；新增 lert-notify-worker；API 增加 rule replay 端点并更新 OpenAPI
    - Verify：python docs/tools/run-quality-gates.py、
    pm run lint、
    pm run build、infra/compose/scripts/e2e-smoke-test.ps1 -Stage2Regression
    - Risk/Rollback：revert 本 commit
    [openapi.yaml]
2025-12-19 feat(system): 实现 /dashboard 与 /system/status（Stage4）
    - Why：阶段 4 需要 App/Web 可读取系统状态与仪表盘汇总，OpenAPI 已定义但实现缺失
    - What：实现 GET /system/status、GET /dashboard；新增阶段 4 验收清单；e2e 增加断言并留证
    pm run build、e2e-smoke-test.ps1 -Stage2Regression
    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
2025-12-19 docs(roadmap): 阶段4完成，进入阶段5
    - Why：阶段推进需要在 project-status.md 明确记录，避免交接遗漏
    - What：标记阶段 4 完成并给出阶段 5 Next Actions
    pm run build
    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
2025-12-20 feat: migrate repo to landslide-monitoring-v2 monorepo (#65)
    * Initial commit: OpenHarmony滑坡监测系统完整代码（包含密钥和环境变量）
    * feat: migrate to landslide-monitoring-v2 monorepo
    - Replace legacy landslide-monitor stack with v2 monorepo layout (apps/, services/, libs/, infra/, docs/)\n- Move legacy project into backups/legacy-landslide-monitor (ignored)\n- Fix apps/web to build on v2: use /api/v1 endpoints for device list + device shadow; deprecate Supabase-only Next API routes that break build\n- Ensure quality gates, lint, and build pass
    * docs: record GitHub remote and migration branch
    Add GitHub remote URL and current migration branch/commit to the project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
    [openapi.yaml]
2025-12-21 feat(security): enforce API RBAC permissions
    - API: switch admin-gated routes to permission-based RBAC (requirePermission)\n- Storage: seed default role_permissions mapping for super_admin/admin/user\n- Web: add JWT login, auto refresh, and per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
2025-12-22 feat(web): ops system monitor and debug API (WS-G) (#79)
    * feat(web): add ops system monitor and debug API
    * fix(web): avoid Windows .next trace EPERM
    * docs(roadmap): update project status
    * docs(roadmap): update project status for WS-G
2025-12-22 feat(ws-d.2): GPS deformation series API (#110)
    * feat(ws-d.2): gps deformation series API
    * fix(api): satisfy eslint types in gps deformations
    * docs(api): clarify gps deformation metric keys
    * docs(project-status): note WS-D.2 key overrides
    * docs(workstreams): link WS-D.2 PR (#110)
    [openapi.yaml]
2025-12-23 feat(api): anomaly assessment compatibility endpoint (WS-K.4) (#130)
    * feat(api): add anomaly assessment compatibility endpoint (WS-K.4)
    * docs(api): fix anomaly assessment endpoint signature
    * fix(api): build errors for anomaly assessment routes
    [openapi.yaml]
2025-12-23 feat(api): GPS baselines advanced endpoints (WS-K.5) (#133)
    * feat(api): add GPS baselines advanced endpoints (WS-K.5)
    * fix(api): satisfy lint for gps baselines advanced
    [openapi.yaml]
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2025-12-23 feat(ws-k3): device health expert (#145)
    * feat(ws-k3): device health expert
    * fix(ws-k3): restore ajv2020 + device checks
    * docs(workstreams): mark WS-K.3 done (#145)
    [openapi.yaml]
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2025-12-24 feat(ws-n5): analysis legacy UI shell (#192)
    * feat(ws-n5): add legacy analysis UI shell
    * feat(ws-n5): switch /analysis to legacy UI
    * docs(workstreams): link WS-N.5 PR #192
    * docs(status): note WS-N.5 PR #192
2025-12-24 feat(ws-n6): analysis core charts 1:1 (#195)
    * feat(ws-n6): port core charts (temp/humidity/accel/gyro)
    * docs(project-status): link WS-N.6 PR
2025-12-25 feat(ws-n10): analysis device naming/mapping 1:1 (#205)
    * feat(ws-n10): restore device naming and mapping
    * docs(project-status): link WS-N.8 and add WS-N.10
    * docs(workstreams): link WS-N.10 PR #205
2025-12-25 feat(ws-n11): analysis 2D/卫星 MapContainer 1:1 (#207)
    * feat(ws-n11): restore analysis 2d/satellite map
    * docs(project-status): link WS-N.11 PR
2025-12-25 WS-O.4: restore /device-management legacy page (#218)
    * feat(ws-o4): restore /device-management legacy page
    * fix(ws-o4): guard nullable device coordinates
    * docs(ws-o4): set PR link and status
    * docs(workstreams): mark WS-O.2/WS-O.4 done
2025-12-25 WS-K.10: legacy /iot/api prefix alias (#232)
    * docs(workstreams): claim WS-K.10
    * WS-K.10: mount legacy compat under /iot/api
    * docs(workstreams): link WS-K.10 PR
    * docs(roadmap): note WS-K.10 /iot/api alias
2025-12-25 WS-K.9: device-management deformation legacy compat (#230)
    * docs(workstreams): claim WS-K.9
    * WS-K.9: add device-management deformation compat
    * docs(roadmap): note WS-K.9 deformation compat
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2025-12-26 WS-K.11: legacy device-management export/reports/diagnostics (#244)
    * WS-K.11: legacy device-management export/reports/diagnostics
    * docs(roadmap): update project status for WS-K.11
2025-12-26 fix(api): support legacy /api/camera (and /iot/api/camera) (#252)
    * fix(api): expose legacy /api/camera paths
    * chore(api): fix camera legacy handler types
    * docs(roadmap): update project status for WS-K.17
2025-12-26 feat(api): iot-server /devices compat aliases (#254)
    * feat(api): add iot-server /devices compat aliases
    * fix(api): type fastify inject method
    * docs(roadmap): update project status for WS-K.18
2025-12-26 fix(api): legacy data-aggregation clear_cache (#256)
    * fix(api): support legacy data-aggregation clear_cache
    * fix(api): satisfy eslint optional chain rule
    * docs(roadmap): update project status for WS-K.19
2025-12-26 fix(api): iot-server /devices management+status compat (#262)
    Squash merge via Codex CLI
2025-12-27 fix(api): legacy monitoring-stations :deviceId mutations (#273)
    * fix(api): support monitoring-stations :deviceId PUT/DELETE
    * fix(api): update stations via monitoring-stations PUT
    * docs(roadmap): link PR #273
2025-12-27 fix(web): restore legacy device-management backup file (#277)
    * fix(web): restore device-management backup file
    * docs(roadmap): link PR for WS-O.6
2025-12-28 docs(roadmap): mark Stage4 acceptance complete
    - Why：把 Stage4 验收结论显式落到文档，便于后续交接与回归基线约束
    - What：更新 Stage4 验收清单状态与说明
    - Verify：CI docs-and-contracts 通过
    - Risk/Rollback：revert 本 PR
2025-12-28 fix(api): WS-K.33 monitoring-stations chart config compat
    - Why：兼容旧前端/脚本对 monitoring-stations 图表配置的历史调用
    - What：补齐 /api/monitoring-stations/chart-config 代理与 legacy query 返回字段一致性；修复相关 lint/文档门禁
    - Verify：CI docs-and-contracts 通过；本地已验证 lint/build 通过
    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
2025-12-28 docs(roadmap): mark WS-K.33 done
    - Why：WS-K.33 已合并，需要回填 workstreams 状态
    - What：将 WS-K.33 状态更新为 done
    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
2025-12-28 fix(infra): retry ClickHouse init with container creds
    - Why：本地长期运行的 ClickHouse 可能与 .env 不一致，导致 e2e/Stage5Regression 初始化失败
    - What：init-clickhouse.ps1 在认证失败时读取容器内 CLICKHOUSE_* 并重试
    - Verify：CI docs-and-contracts 通过；本地执行 init-clickhouse.ps1 已验证可重试
    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
2025-12-28 fix(api): avoid duplicated legacy alias routes
    - Why：Stage5Regression 启动 api-service 时 Fastify 报 duplicated route（/api/device-management-optimized 等）
    - What：移除重复注册的 legacy compat alias routes，保留 legacy-device-management 提供的等价别名
    - Verify：CI docs-and-contracts 通过；本地
    pm run lint -w @lsmv2/api-service 通过
    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
2025-12-28 fix(infra): use runtime DB creds in e2e env
    - Why：本地 infra 容器长期运行时可能与 infra/compose/.env 不一致，导致 Stage5Regression 访问 /api/v1/system/status 与 /api/v1/dashboard 失败
    - What：e2e-smoke-test.ps1 生成各服务 .env 前优先读取 postgres/clickhouse 容器内实际 POSTGRES_*/CLICKHOUSE_*
    - Verify：CI docs-and-contracts 通过；本地 Stage5Regression 已复跑通过
    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
2025-12-28 docs(roadmap): record Stage5Regression status
    - Why：Stage5Regression 已跑通，需要把状态落到验收/交接文档并回填 workstreams
    - What：更新 stage5-acceptance、project-status；将 WS-G.9 标记为 done
    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
2025-12-28 fix(api): camera legacy compat PUT/DELETE (#294)
    * fix(api): camera legacy compat PUT/DELETE
    * docs(roadmap): update project status for camera PUT/DELETE
2025-12-28 docs(roadmap): update /debug-api walkthrough notes
    - Why：文档仍按旧行为描述 /debug-api 跳转，但 v2 已恢复参考区同款调试页
    - What：更新 final-acceptance-walkthrough 与 gap-audit 的 /debug-api 描述
    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
2026-03-26 feat: extend gateway samples to remaining command types
    [motor_start.pretty.json, motor_stop.pretty.json]
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2026-04-08 fix: tighten shared-port proof acceptance
2026-04-08 fix: harden rk3568 parser deploy flow
2026-04-08 fix: filter non-schema southbound json candidates
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2026-04-09 fix: sanitize field device state shadow keys
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2026-06-02 chore: organize desktop-first project repository
    [rk2206-v1-self-purchase-bom-2026-04-23.csv]
2026-06-02 fix: keep web device last active typed
2026-07-08 chore: focus public tree on desktop client
    [motor_start.pretty.json, motor_stop.pretty.json, rk2206-v1-self-purchase-bom-2026-04-23.csv]
2026-07-09 feat: publish end-to-end monitoring system assets (#312)
    * feat: publish end-to-end monitoring system assets
    * ci: split desktop and windows validation jobs
    ---------
    [bom-board1-2026-04-23.xlsx, pick-and-place-2026-04-27.xlsx]
2026-07-18 feat(firmware): recover stalled field links (#325)
    [app_config.h, field_sensors_rs485.c]
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2026-07-20 fix(api): make current-day telemetry counts reliable
    Use Beijing-day boundaries and ClickHouse String-to-DateTime64 conversion for dashboard and device-state telemetry counts.
2026-07-20 fix(harmonyos): show report and actuator status accurately (#337)
    * fix(harmonyos): report uploads and actuator status accurately
    * fix(harmonyos): separate colocated map nodes
    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
2026-07-20 feat: add isolated Hermes edge risk agent (#338)
    * feat(edge-ai): add isolated Hermes risk agent
    * ci: build regional model types before AI lint
    * fix(ai): track artifact registry source
    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
    [openapi.yaml]

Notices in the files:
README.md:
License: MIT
